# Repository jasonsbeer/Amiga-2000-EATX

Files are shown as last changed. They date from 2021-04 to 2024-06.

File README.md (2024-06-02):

# Amiga 2000 EATX PCB

This is an open source Amiga 2000 PCB in the EATX form factor. EATX is an ATX variant that defines larger PCBs, measuring 12 x 13 inches (305 × 330 mm). These are referred to as Extended ATX, or, EATX (see [Enterprise Electronics Bay Specification](/DataSheets/SSI%20EEB%202011%201.0.1.pdf)). The length of Zorro II cards and the abundance of components on the Amiga 2000 makes EATX the best choice for this project.

There are one-to-one board replacement projects for the Amiga 2000, but none to change the layout to meet current form factor standards. In addition, the Amiga 2000 made use of connectors and custom parts that are no longer commercially manufactured. This often requires parts to be pulled from existing machines. As such, this project will make use of only actively supported components when possible.

In addition to a new board replacement option, I believe the ubiquitous EATX standard will bring additional interest to the Amiga as a hobbyist and retro-computing option. At the time or writting this, the Amiga operating system is still actively developed and supported. In addition, there is a substantial database of existing software and hardware add-on options and an active community.

Discord: https://discord.gg/NU7SPYfNFj

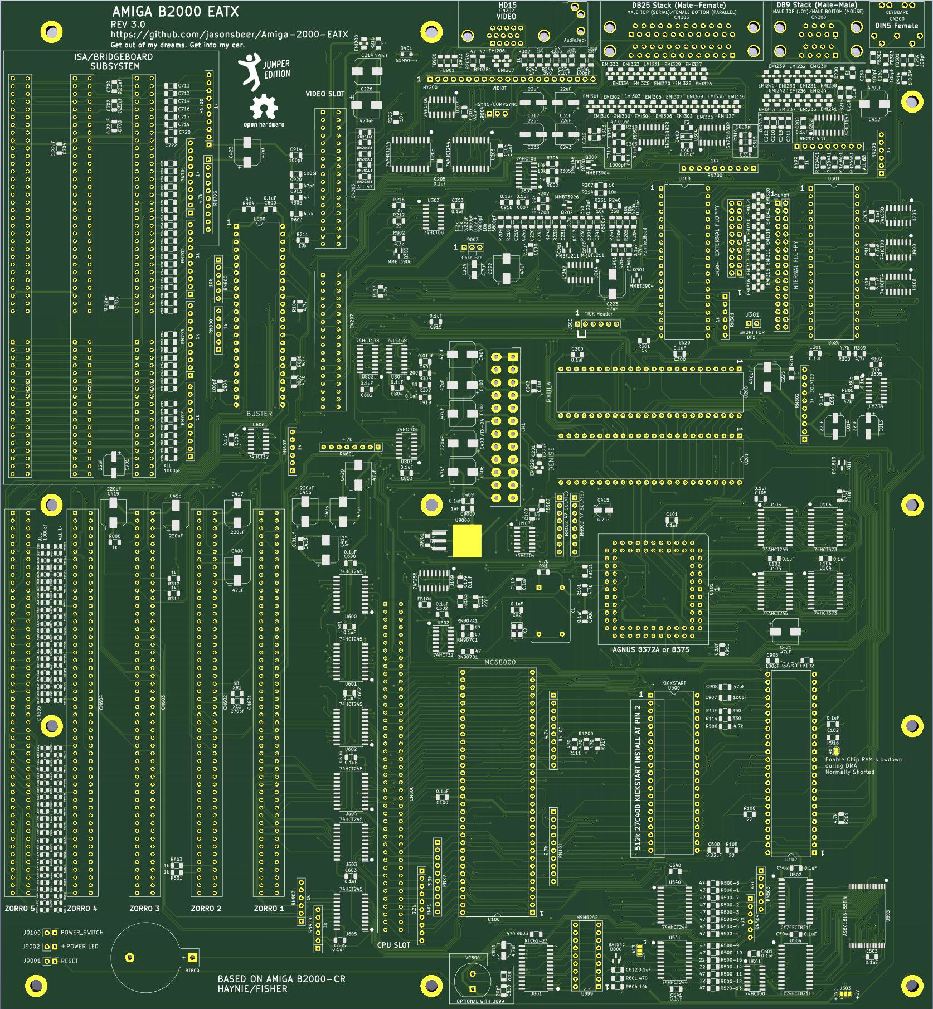
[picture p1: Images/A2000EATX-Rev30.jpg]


## Project Status

### Revision 3.1 is the current production board.

**Known Issues**: See Issues tab.

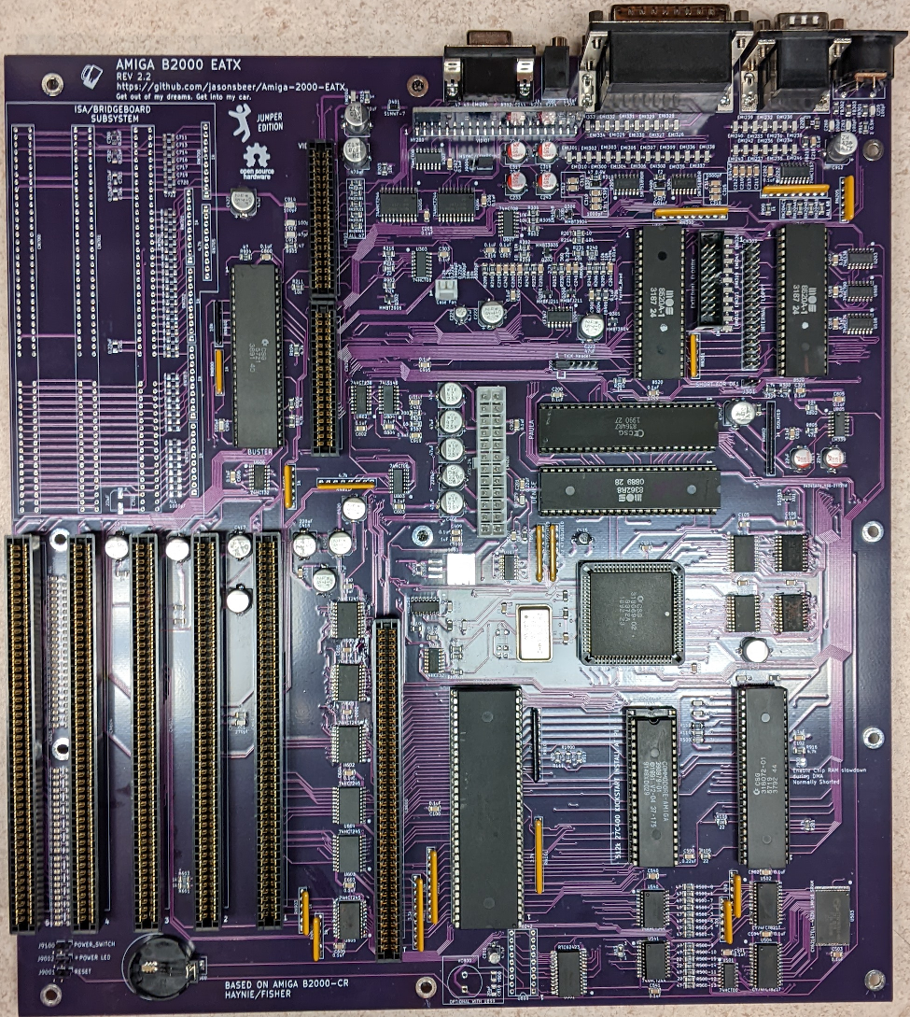
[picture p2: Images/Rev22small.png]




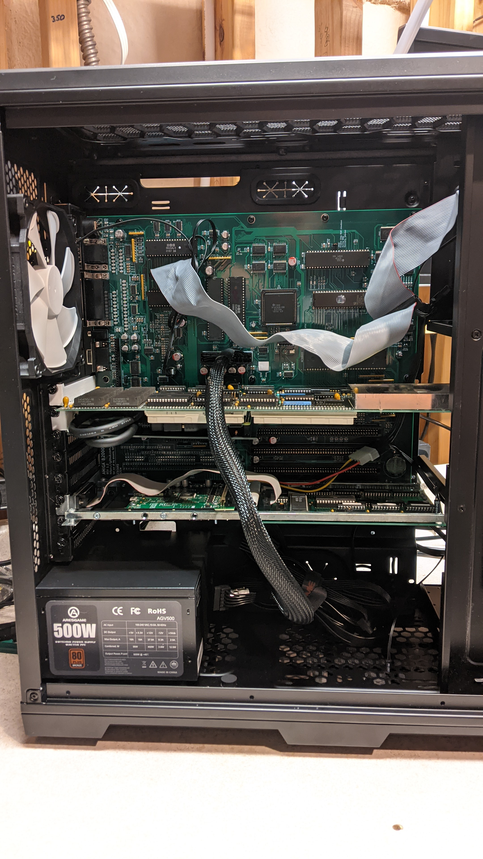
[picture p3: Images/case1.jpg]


Revision 3.0 can be found [here](https://github.com/jasonsbeer/Amiga-2000-EATX/tree/Rev-3.0).  
Revision 2.2 can be found [here](https://github.com/jasonsbeer/Amiga-2000-EATX/tree/Rev-2.2).  
Revision 1.2.1 can be found [here](https://github.com/jasonsbeer/Amiga-2000-EATX/tree/Rev-1.2.1).  

If you are interested in a brief history of this project, check out the [Gallery page](/Gallery.md).

## User Guide and Considerations
Review [this information](userguide.md) to ensure a smooth and happy experience when assembling an Amiga 2000 EATX system. It will answer many questions and inform you as to the physical requirements of the Amiga 2000 EATX PCB, various Amiga plug in cards, etc.

## Ordering PCBs
See information [here](PCB.md). 

## BOM and Assembling the Amiga 2000 EATX PCB

See information [here](AssemblyNotes.md).

## Changes from the original Amiga 2000

The Amiga 2000 EATX is derived from the Commodore Amiga 2000 Rev 6.2 schematics. To my knowledge, all known Rev 6.x PCB updates are included in this project. 

### Video
The DB23 video connector has been removed in favor of the HD15 connector. One of the goals of this project is to avoid parts that are not commercially available. The D-Sub 23 connector is a prime example. They are not stocked at popular electronic supply houses. Thus, the change to the widely available HD15 connector. Analog red, green, blue, HSYNC or COMPSYNC (jumper selectable), and VSYNC are supplied using the VGA standard pin out configuration. Other external video port signals are not supplied. Any VGA cable can be used to supply the video signal to a VGA monitor or conversion box supporting the 15KHz standard. 

The internal video slot is complete with all signals.

The external composite video jack has been removed.

### Memory
The original 256Kx4 DRAMs have been replaced by a single SRAM. The Amiga 2000 EATX supports 1 or 2 MB of chip memory, depending on your Agnus version. See additional information in the [assembly notes](AssemblyNotes.md).

### Audio Output
The left/right RCA jacks of the Amiga have been replaced by a 3.5mm stereo audio jack.

### Disk Drive Support
Internally, any Amiga compatable double density disk drive or properly configured Gotek floppy emulator is supported. Up to two internal disk drives may be connected to the internal floppy connector. Up to two external disk drives may be connected via a user supplied adapter cable.

### ISA Slots
The number of 16 bit ISA slots has been reduced to three. This was done to provide additional space on the board. Support for ISA cards via a Bridgeboard is unchanged from the Amiga 2000.

### Serial Port
The internal (infernal) serial port has been removed. The external serial port is present with all signals.

### PCB Layout
For obvious reasons, it was necessary to move components relative to one another. Zorro slots occupy slot positions 1-5, overlapping with ISA slots in the first 3 positions. The video slot occupies the sixth slot position on the board.  The CPU slot occupies position 7. It is possible to have every slot position populated simultaneously.

### ATX Power
ATX 24-pin power supplies are supported with -5V being supplied on board via a voltage regulator. The original Amiga 2000 power supply is not supported.

### External Reset Switch
The computer can be reset via CTRL-Amiga-Amiga on an Amiga keyboard or via the reset switch found on EATX computer cases.

### Real Time Clock
There are two real time clock (RTC) options beginning with revision 2.x. You can install the original Amiga 2000 RTC, which is based on the MSM6242, or a simplified RTC based on the RTC-62423. The MSM6242 requires more components and will need to be trimmed to dial in the correct clock speed. The RTC-62423 has a built in crystal and does not need adjustment, but is less accurate over time. In the Amiga, the RTC is written and read by 4 address and 4 data lines. There are no direct "modern" replacements for the type of bus connected RTC used in the Amiga. As such, the RTC chip you choose is among the legacy IC's that must be obtained. 

### TICK
The TICK timing signal on the original Amiga 2000 was supplied by the power supply and is a 50 or 60Hz signal determined by the mains power in use. ATX power supplies do not supply a TICK or any AC signal. Starting with Revision 2.2, a TICK Header (J300) was added to support independently generated TICK signals in the event your desired configuration demands this. The factory default setting supplies a TICK signal from the Agnus _VSYNC signal, which is suitable for most configurations. See [TICK HEADER](/AssemblyNotes.md#tick-header-j300) for more details and considerations. All revisions 2.1 and lower use the Agnus _VSYNC signal.

## What has not changed?
### Most External Ports
The keyboard, joystick, mouse, parallel, and serial ports are all present and function as they did in the Amiga 2000. The parallel, serial, mouse, and joystick ports are stacked DB9 and DB25 connectors, respectively. The Amiga keyboard port remains a DIN5 connector.

### Zorro II Slots
There are no changes to the Zorro II slots.

### Kickstart ROM
For now, the Kickstart ROM remains the original 27C400. These are no longer made, but are easy to find. In addition, this allows the use of an original Commodore Kickstart mask ROM. Revision 1.2 added support for 1MB (27C800) and 2MB (27C160) EPROMs for custom Kickstart ROMs.

### Everything Else
If something is not specifically mentioned, you should expect it to be unchanged in function or component from the original Amiga 2000.

## Revision History

Rev 3.1 **CURRENT PRODUCTION REVISION**
1. Various fixes (see closed issues flagged for Revision 3.1)
2. Changed SRAM back to +5V part
3. Added copper pours to top and bottom layer
4. Updated to KiCAD 8.0

Rev 3.0
1. Various fixes (see closed issues flagged for Revision 3.0)
2. Changed SRAM to 5V tolerant 3.3V part (lack of availability of +5V part)
3. Removed almost all signal traces from power planes
4. Swapped position of U801 and U899 and brought related components to front of board
5. Updated to KiCAD 7.0

Rev. 2.2  
1. Added TICK header (J300)
2. Cleaned up some odd routing that went back to the early revisions of this project
3. Changed footprint of CN300 to support more part options

Rev 2.1
1. Changed footprint of U9000 to offer more part options
2. Added U207 to buffer VSYNC and HSYNC signals
3. Relocated Zorro termination components
4. Added additional component values to silk screen
5. Moved many traces to the external layers

Rev 2.0
1. Supports both Agnus 8372A and certain Agnus 8375 part numbers on the same board
2. Added external floppy drive header
3. Support for two real-time clock options
4. Cleaned up the schematics

Rev 1.2.1 (First Production Release)
1. Added some missing component values to the silk screen, where there was room
2. Moved VIDIOT over to make additional room for coprocessor cards

Rev 1.2
1. Fixed traces on the keyboard connector (error on the C= schematic)
2. Added missing _COPCFG trace
3. Deleted some extra traces that were not needed
4. Added HSYNC/COMPSYNC selection jumper
5. Cleaned up parts of the schematics
6. Widened U801 footprint (RTC62423 is wider than the standard SOIC package)
7. Added support for 1 and 2 MB Kickstart ROMs (512k still supported)
8. Added some space around the external ports...they were crowded

Rev 1.1
1. New ATX on/off circuit
2. Modified SRAM circuit
3. Added case fan header
4. Fixed U100 and other footprints
5. Moved some components
6. Cleaned up silk screen

Rev 1.0
1. Adjusted postion of slots and several other components
2. Moved ATX On/Off circuit to back of board

Rev 0 - Prototype board
   
## Acknowledgments
kr239 - for the Amiga 500 DRAM replacement project inspiration and LIV2 and texneus for the modifications used in this project

iansbremmer - Amiga IC KiCad footprints - https://github.com/iansbremner/ReAmiga-3000---KiCAD

texneus - ATX ON/OFF and AC TICK circuit

DarrenHD - Pics and measurements of the Amiga 3000 video slot bracket adapter - https://eab.abime.net/showthread.php?t=106928

Chucky - Amiga Diagrom...a priceless diagnostic tool - http://www.diagrom.com/

floppie209 - For testing the Rev 3.0 board.

Everyone that made the Amiga possible.

**Last Updated 02-JUN-2024**

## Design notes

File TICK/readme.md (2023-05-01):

# TICK Generator Boards

Included here are two options ([9VAC](#9vac-tick-generator) and [Crystal Oscillator](#crystal-oscillator-tick-generator)) for generating an independent TICK signal for the Amiga 2000 EATX. These could be used in other projects needing a replacement TICK generator, such as adding an ATX power supply to an original big box Amiga. Both options are very simple circuits, small in size, and designed to be placed directly on J300 of the Amiga 2000 EATX Rev 2.2 and greater.

For more information on the Amiga 2000 EATX TICK and considerations, see [HERE](/README.md#tick) and [HERE](/AssemblyNotes.md#tick-header-j300)

Gerber files can be found [HERE](/Gerber).

## 9VAC TICK Generator
TICK signals are generated from the frequency of the mains power in use. This means 50 or 60 Hz, depending on where you are in the world. ATX power supplies, such as used by the Amiga 2000 EATX, supply neither a TICK nor AC signal of any type. Thus, it is necessary to create our own with a small circuit suitable for any mains frequency. In this case, we are using a 9VAC wall wart transformer to supply an AC signal based on the mains of the local power grid. Using 9VAC reduces the risk associated with powering such a device directly from mains while allowing us a more traditional TICK signal. Note that the AC TICK board will continue to receive power and function (to some extent) while the wall wart is plugged in, even when the Amiga 2000 EATX is turned off. You may wish to use a switched outlet or simply unplug the wall wort when not in use. Ensure alignment of pin 1 on the Amiga 2000 EATX with pin 1 on the 9VAC TICK board. See [BOM](#bom).

Image 1. The 9VAC TICK generator board on the Amiga 2000 EATX.

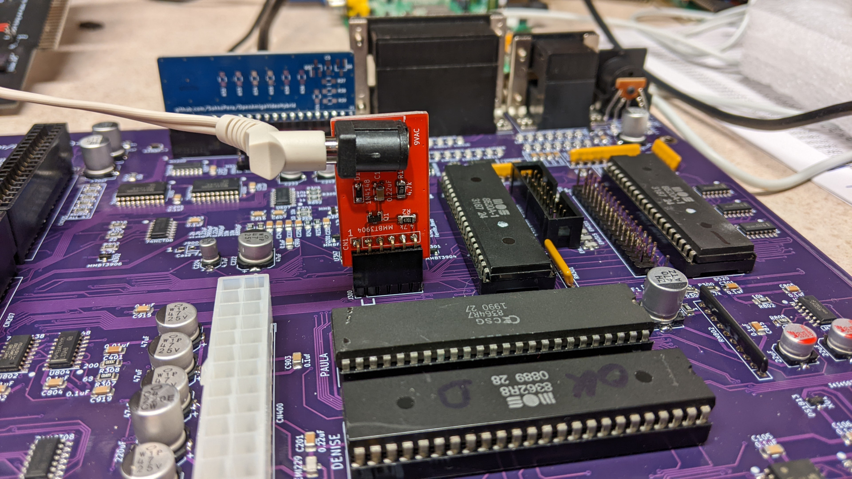
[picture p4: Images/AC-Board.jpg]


Image 2. A 60Hz TICK signal from the 9VAC TICK Generator.

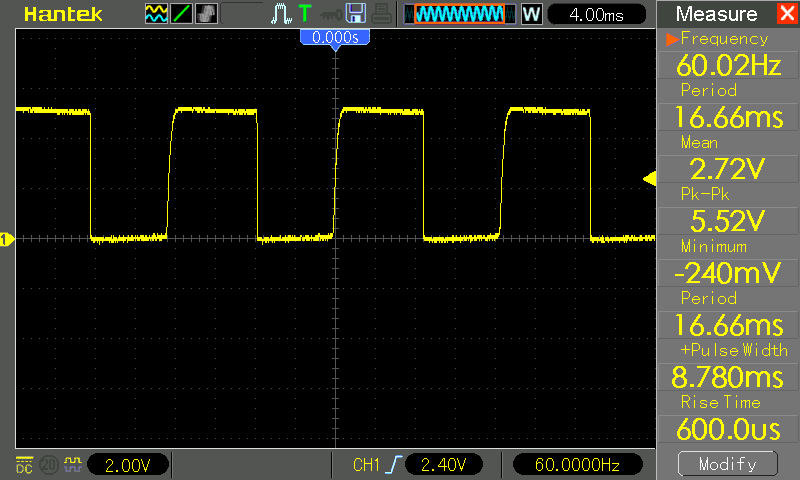
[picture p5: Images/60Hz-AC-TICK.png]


## Crystal Oscillator TICK Generator
Like many modern components, we can also generate an accurate TICK signal with a crystal oscillator. The advantage of this is that we have an entirely self-contained circuit that does not rely on external power sources to drive the frequency. This circuit is a single board, though slighly more complex than the AC TICK circuit, powered directly by the Amiga 2000 EATX. To ensure the correct 50 or 60 Hz frequency, we use the crystal that matches the desired frequency of the video standard your machine is configured to. This circuit is based on the original published by [Michael Schulz](https://aminet.net/package/docs/hard/Mix_and_Tick). Ensure alignment of pin 1 on the Amiga 2000 EATX with pin 1 on the crystal oscillator TICK board. See [BOM](#bom).

Image 3. The crystal oscillator TICK generator board on the Amiga 2000 EATX.

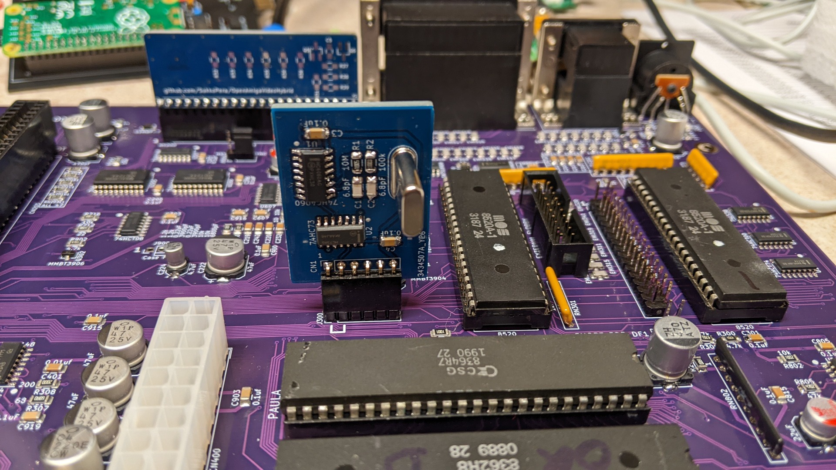
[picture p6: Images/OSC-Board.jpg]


Image 4. A 50Hz TICK signal from the crystal oscillator TICK Generator.

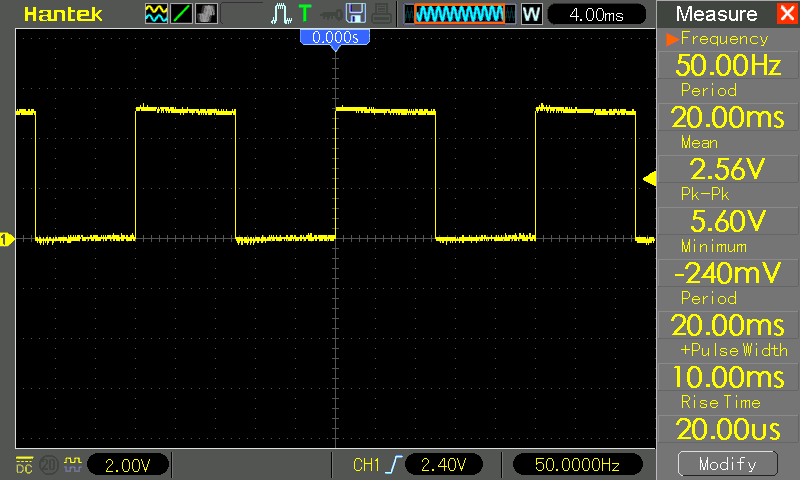
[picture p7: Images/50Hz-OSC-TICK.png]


## Dual Oscillator TICK Generator
Submitted by kavanoz and sparxUK, this TICK generator is based on the crystal oscillator TICK board but can be set to either PAL or NTSC via the on-board jumper. The passives have been reduced to the 0805 footprint. The BOM and assembly files can be found with the Gerber files in the [Gerber](/Gerber) folder.

Image 5. Dual oscillator TICK board on the Amiga 2000 EATX.

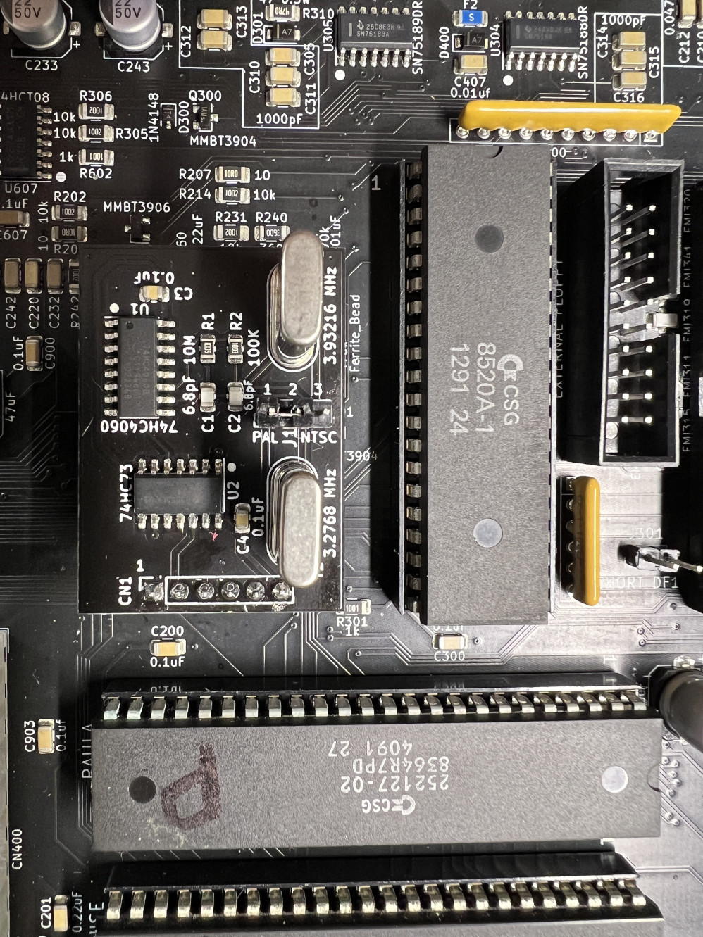
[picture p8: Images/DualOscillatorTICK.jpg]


## BOM
**Table 1.** 9VAC BOM

Reference|Value|Footprint|Notes
-|-|-|-
C1|0.22uF|1206|
D1|1N4148|SOD-323|
R1|4.7k|1206|See Footnote*
R2|4.7k|1206|
Q1|MMBT3904|SOT-23|
CN1|6 Pin Female Header|2.54mm Pitch|
CN2|Barrel Jack||Optional
-|9VAC Wall Wart Transformer||

*It is possible to use transformer output values other than 9VAC. For 6VAC, R1 does not change. For 12VAC or 16VAC transformers, R1 = 10k. For 20VAC or 24VAC transformers, R1 = 22k. These values are untested, so care should be taken when opting to use transformer values greater than 9VAC.

**Table 2.** Crystal Oscillator BOM
Reference|Value|Footprint|Notes
-|-|-|-
C1|6.8pF|1206|
C2|6.8pF|1206|
C3|0.1uF|1206|
C4|0.1uF|1206|
R1|10M|1206|
R2|100k|1206|
U1|74HC4060|16-SOIC|
U2|74HC73|14-SOIC|
Y1|3.93216MHZ|HC-49/U|60Hz (NTSC)
Y1|3.2768MHz|HC-49/U|50Hz (PAL)
CN1|6 Pin Female Header|2.54mm Pitch|

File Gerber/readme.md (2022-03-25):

Gerber files for the Amiga 2000 EATX and TICK generator boards.

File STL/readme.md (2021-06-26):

Here you can find STL and FreeCAD files for new card brackets that will be usefull when building an Amiga 2000 EATX.

[COP Adapter](/STL/COP-Simple-Adapter) is a simple adapter to attach coprocessor and video cards to standard computer slots.

[A26x0 Adapter](/STL/A26x0_Adapter) is a new bracket for the Commodore A2620 and A2630 coprocessor cards.

[Plain Bracket](/STL/Plain-Bracket) is a standard slot cover that can be used to make your own custom bracket or print a spare.

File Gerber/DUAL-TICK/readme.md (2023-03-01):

Contains the Dual-TICK gerber and production files.

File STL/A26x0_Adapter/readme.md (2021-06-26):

This is a standard bracket designed for the Commodore A2620 and A2630 coprocessor cards. This can be used to mount the A26x0 coprocessor card in a standard slot bracket for the Amiga 2000 EATX. Specifically, I designed it using the A2630 Rev 9 as a reference. As far as I know, it should work on either model and any revision.

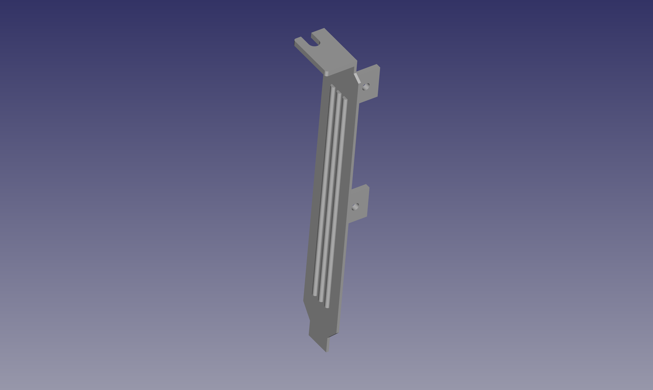
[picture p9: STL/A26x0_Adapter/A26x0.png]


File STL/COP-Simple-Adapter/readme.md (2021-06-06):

This is a simple adapter for coprocessor or video cards that allows you to attach one to a standard computer slot. The STL and FreeCAD files are included.

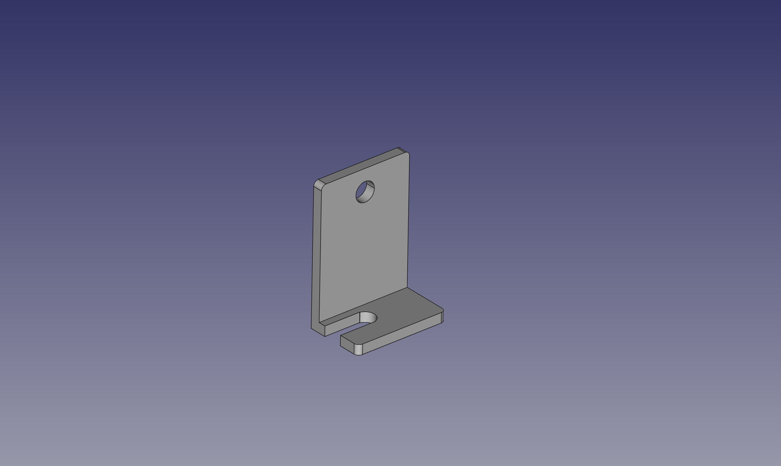
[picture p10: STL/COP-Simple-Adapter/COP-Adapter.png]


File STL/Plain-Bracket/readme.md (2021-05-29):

This is an unmodified slot cover. You can use this as a starting point to design your own custom brackets or just print spares. I have included the STL and FreeCAD files.

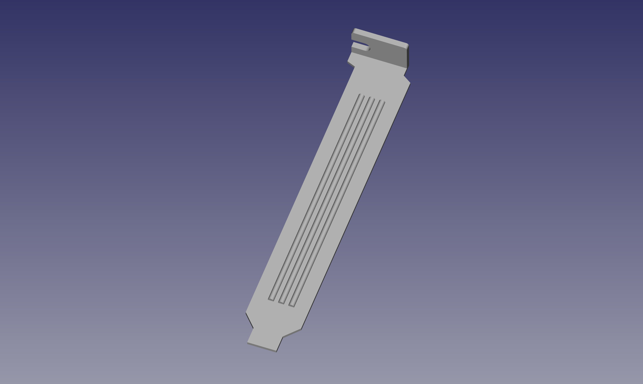
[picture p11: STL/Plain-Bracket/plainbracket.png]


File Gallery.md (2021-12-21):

Here are some photos of note and comments related to the development of the Amiga 2000 EATX. I ordered these from oldest to newest. I thought it would be fun to reflect on the last few months and how much effort this really took. It gives me a time to decompress and think about all it took to get here. Thanks for looking.

The revision 0 board. This is where it all started. Starting in March, 2021, it took 2 weeks to enter the schematics and another 6 weeks to route the board. No components were soldered to this revision because it was painfully obvious that the card slots are nowhere near where the should be. I measured from the edge of the board instead of the correct datum point, which is the upper left mounting hole. I was pretty unhappy with myself, to say the least.

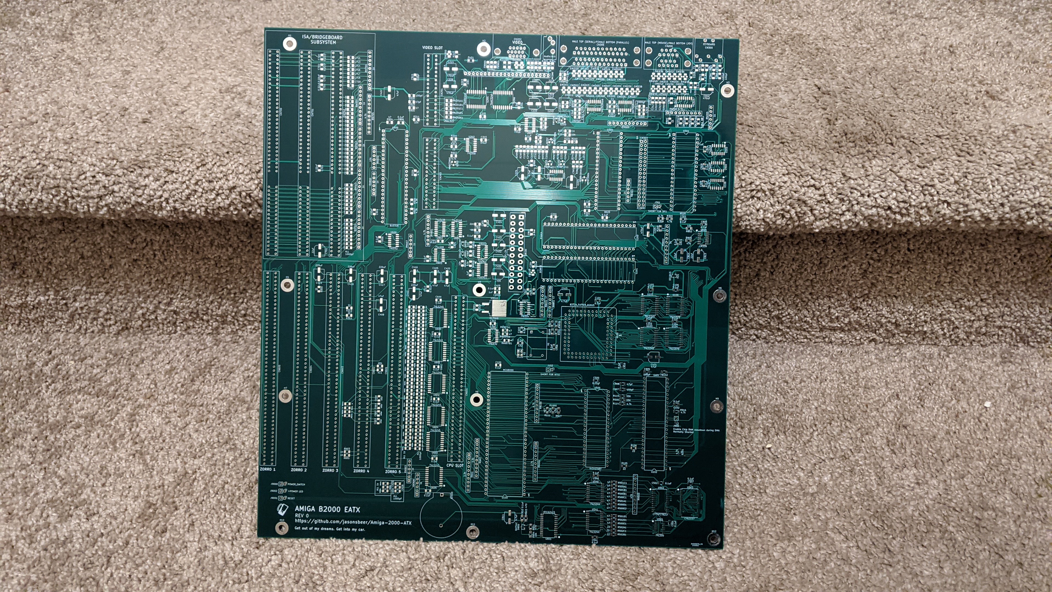
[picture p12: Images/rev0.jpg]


I quickly figured out the datum issue and moved the slots nearer to the correct position for the revision 1.0 board. The Zorro and ISA slot positions are well documented. The video and coprocessor slots...not so much. I spent time looking at pictures of the A3000 back plane and using a micrometer on my A2000 and A2630 to figure out where those slots needed to be. I was really close...within 1-2 millimeters, but still not quite right. I had to move them a little bit for the next revision.

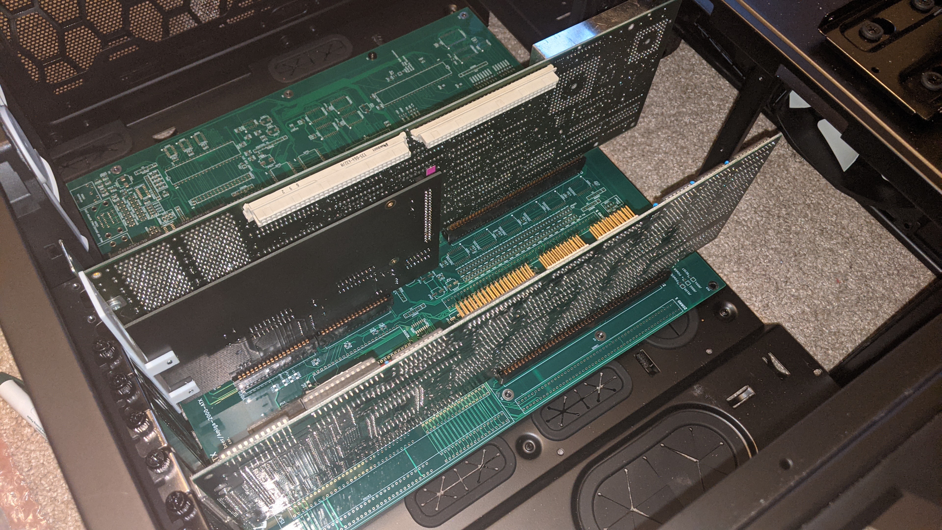
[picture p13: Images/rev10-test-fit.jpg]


Fortunately, it was pointed out to me that the RAM circuit I borrowed was, in fact, inoperable. See issue #1 on GitHub. Thanks to help from some friends and family, we were able to fix up the circuit. This is the bodge I attempted to implement the new RAM circuit on the revision 1.0 board. I never got that board to work. 

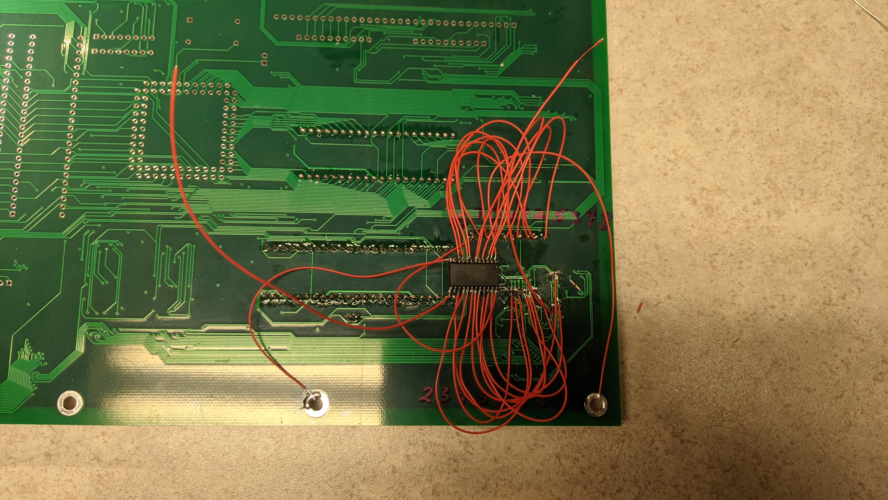
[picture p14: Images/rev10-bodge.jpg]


Trying to track down what was going on with the Revision 1.0 board.

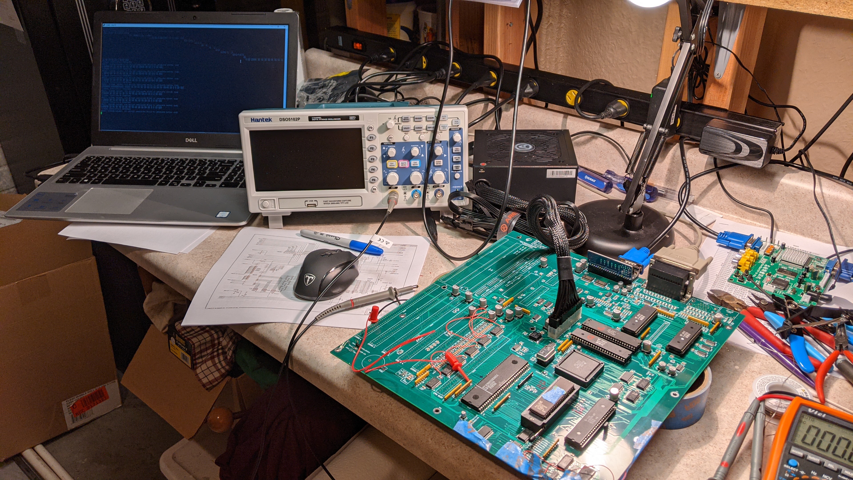
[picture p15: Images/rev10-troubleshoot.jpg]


A hint from diagrom? Ultimately, the original ATX on/off circuit stopped working, which I took as a hint it was time to move to the next revision. I turned to my brother to engineer a more robust latch circuit. He delivered one that first appeared in revision 1.1 and persists to this day.

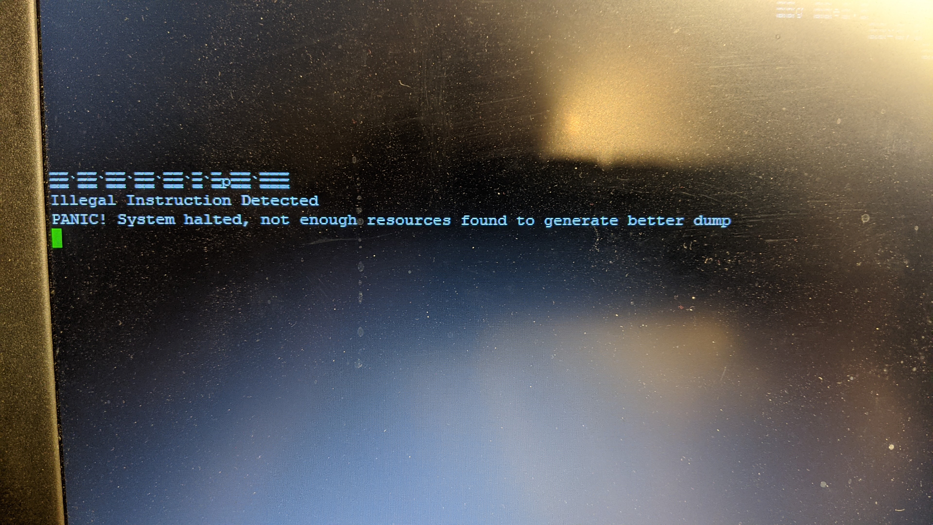
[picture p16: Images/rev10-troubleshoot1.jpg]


My idea of a pre-heater. My SMD technique is to use an electric griddle to pre-heat the board and go over it with a hot air station.

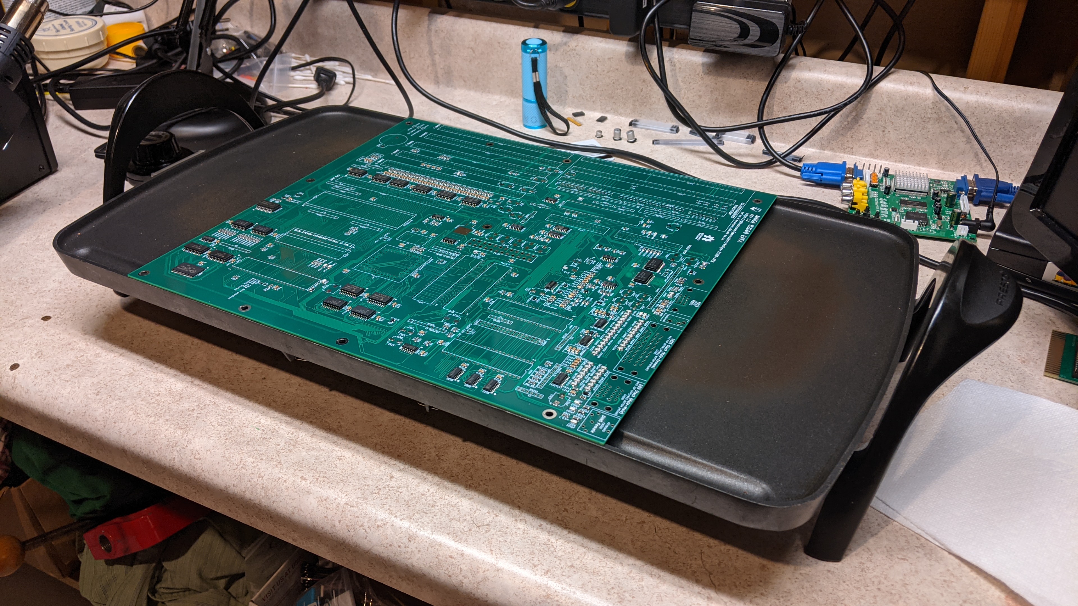
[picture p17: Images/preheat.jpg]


After sending off for the revision 1.1 boards, I found a major issue in the schematics. The most likely reason I was not able to get revision 1.0 working is due to data signals that were connected to PPD signals of U300. Basically, D1 was shorted to PPD1, etc. This happened due to how I labeled some of the signals in the schematics. Lesson learned. You can see the bodges around the serial and parallel port to fix this issue. In addition, I found an error on the Commodore A2000 (and A3000) schematics associated with the keyboard connector. You can see the bodges there, as well. One last bodge to implement the COPCFG signal, which was not routed due to a spelling mistake in the schematics. You can see a tactile switch soldered on as a power switch and an LED soldered directly to the board to serve as the power light.

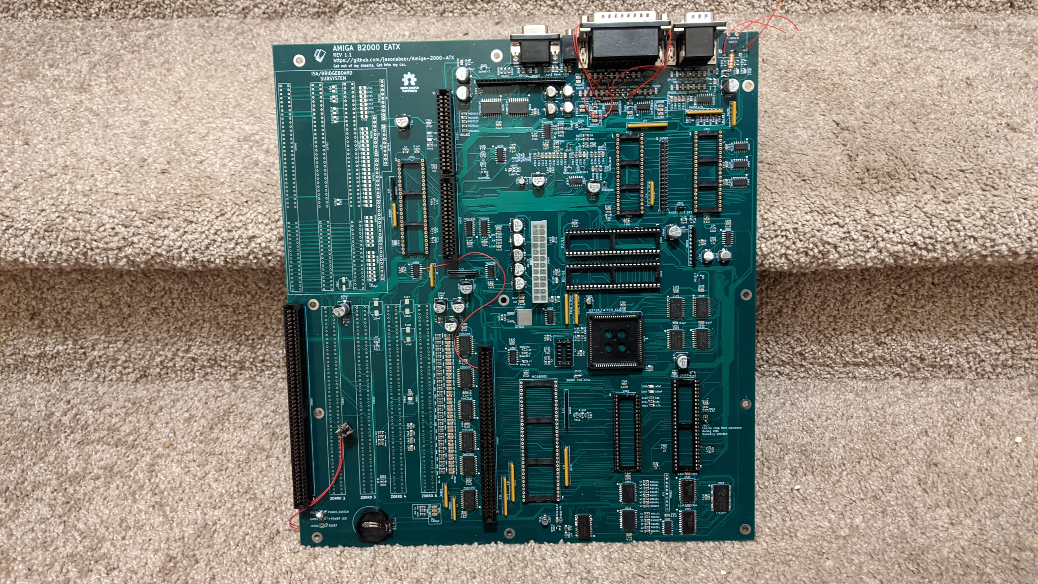
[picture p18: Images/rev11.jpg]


Diagrom says revision 1.1 is working!

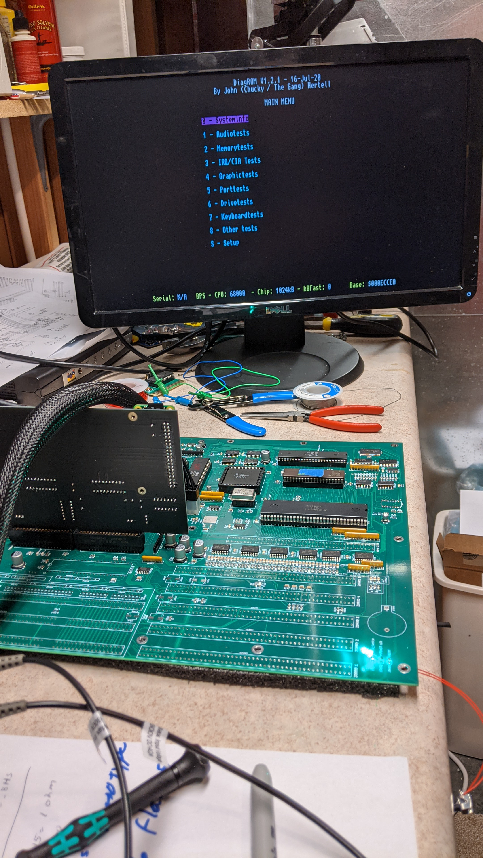
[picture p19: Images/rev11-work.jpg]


Finally! I jumped and yelled with joy when this familiar purple screen appeared.

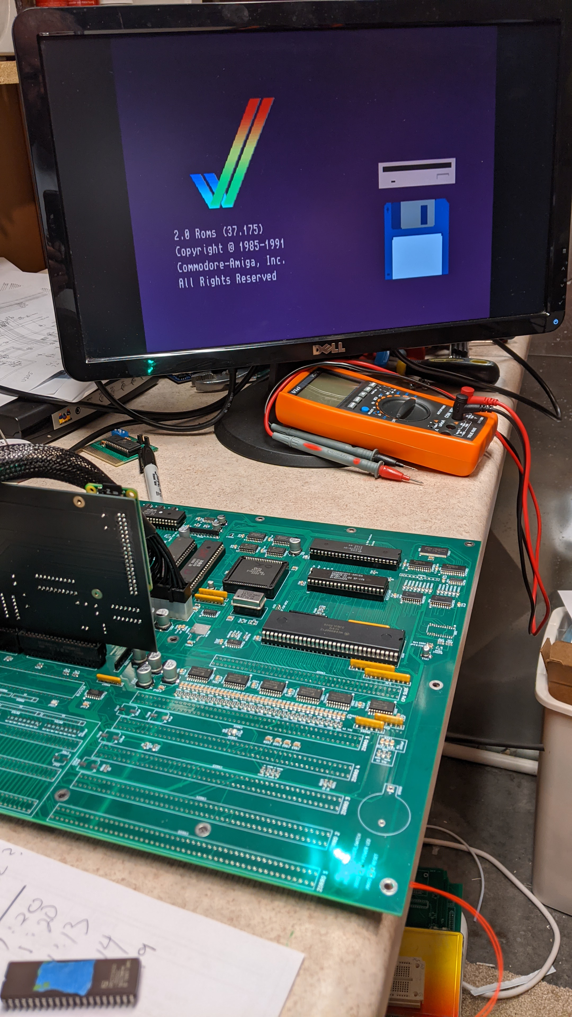
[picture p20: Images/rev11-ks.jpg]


However, not everything was rosey. I was unable to get a picture from the RGB port. The Pi -> HDMI card worked...after a firmware upgrade...that is another story. My brother and I worked on it over the phone several evenings but could find no answers. It seemed that we were unable to get a sync lock using the GBS8200 video adapter. We probed the sync signals incessantly to determine what was wrong. It turned out that there was no problem. After several days of struggle, I reviewed the GBS8200 documentation only to realize it needed a COMPSYNC signal. I had been feeding it HSYNC. I was really mad at myself. This whole ordeal lead to the inclusion of jumper J9004 HSYNC/COMPSYNC. In this picture, you can see the Amiga's VSYNC and HSYNC signals. They look great, which means Agnus is doing her job with flying colors.

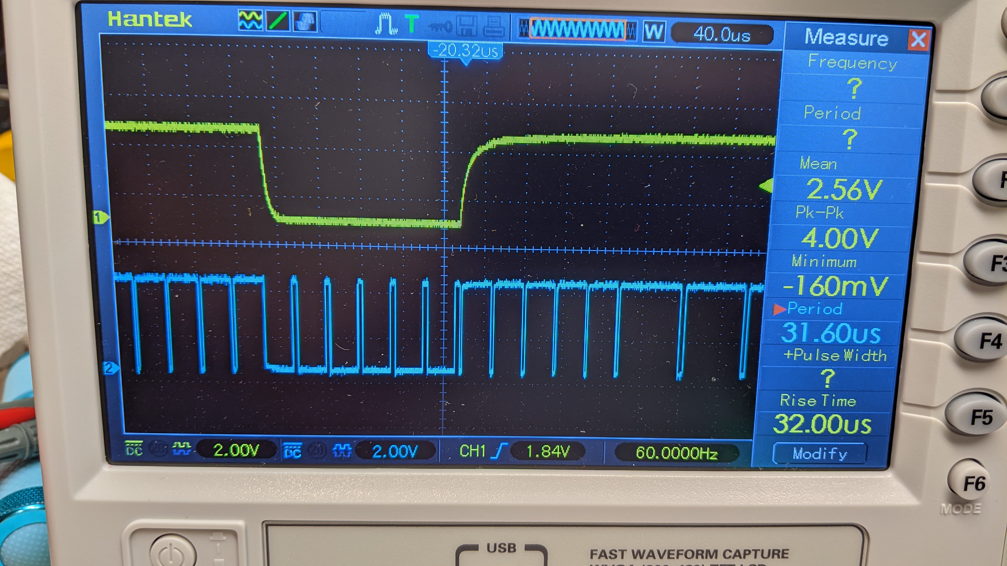
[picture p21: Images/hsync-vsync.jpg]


Revision 1.2, the first production candidate. It worked on the first try. After 6 months of work, we have a working PCB with no bodges.

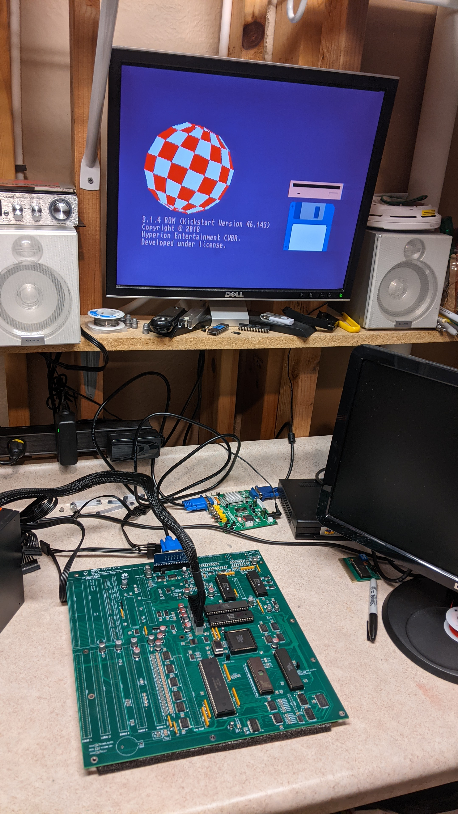
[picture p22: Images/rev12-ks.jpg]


The revision 1.2 board in an Enthoo EATX case.

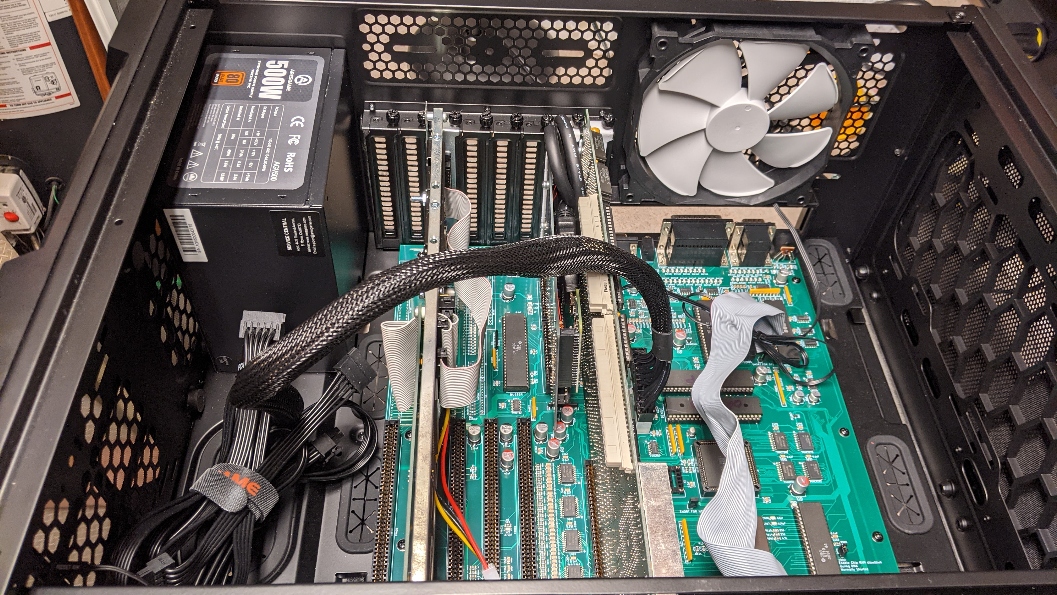
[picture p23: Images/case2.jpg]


Running Workbench 3.1.4 on the revision 1.2 board.

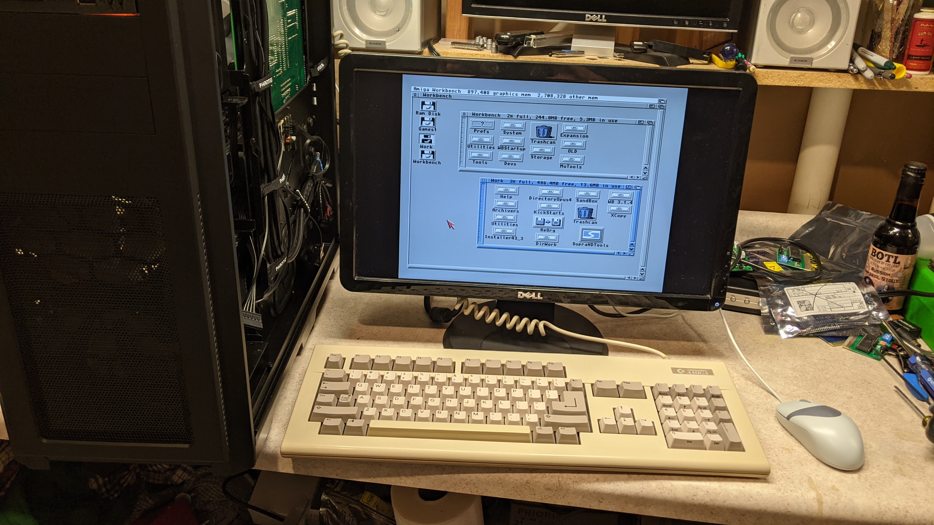
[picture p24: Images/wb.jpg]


The final touch on this project. Connected to J9003, the fan, she spins! 

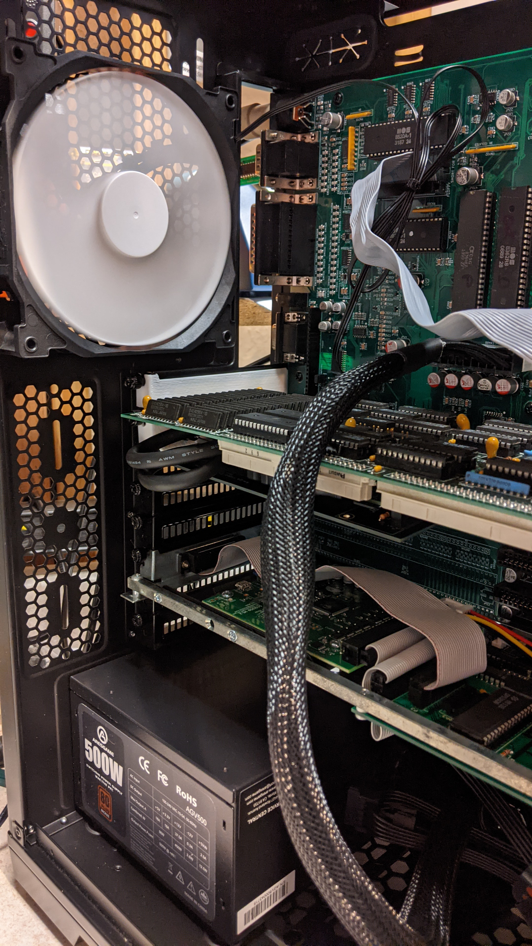
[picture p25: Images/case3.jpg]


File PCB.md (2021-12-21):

## PCB - Description and Ordering

The Amiga 2000 EATX PCB is 4 layers. See Table P1 for layer descriptions. Most components are on the top layer with the ATX on/off circuit and some Agnus and real time clock passives on the bottom.

Download the [Gerber zip file](/Gerber) and send to your favorite PCB manufacturer. If you do not have access to the appropriate stencil, it is highly recommended you purchase one at the time you purchase the PCB.

The development PCB's were purchased from JLCPCB and no issues were encountered. The JLCPCB order screens are shown to reflect their order options. Other PCB fabricators will have similar options, most will be set from the information in the gerber files. Other recommended order options are included to help guide you through the ordering process.

Final PCB thickness is 1.6mm.

Image P1 - Layer stackup

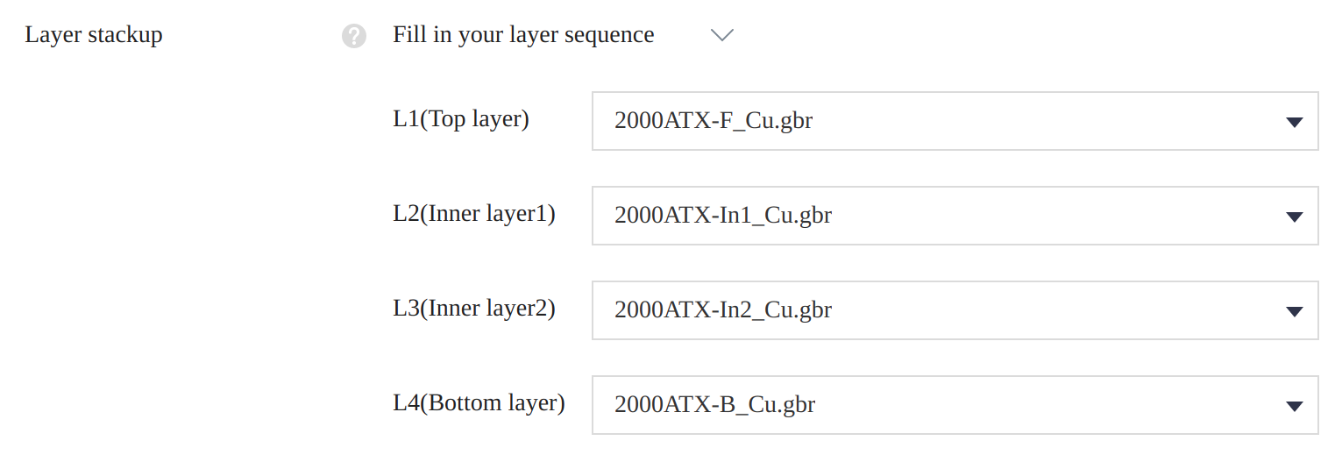
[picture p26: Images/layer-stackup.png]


Image P2 - General fabrication options

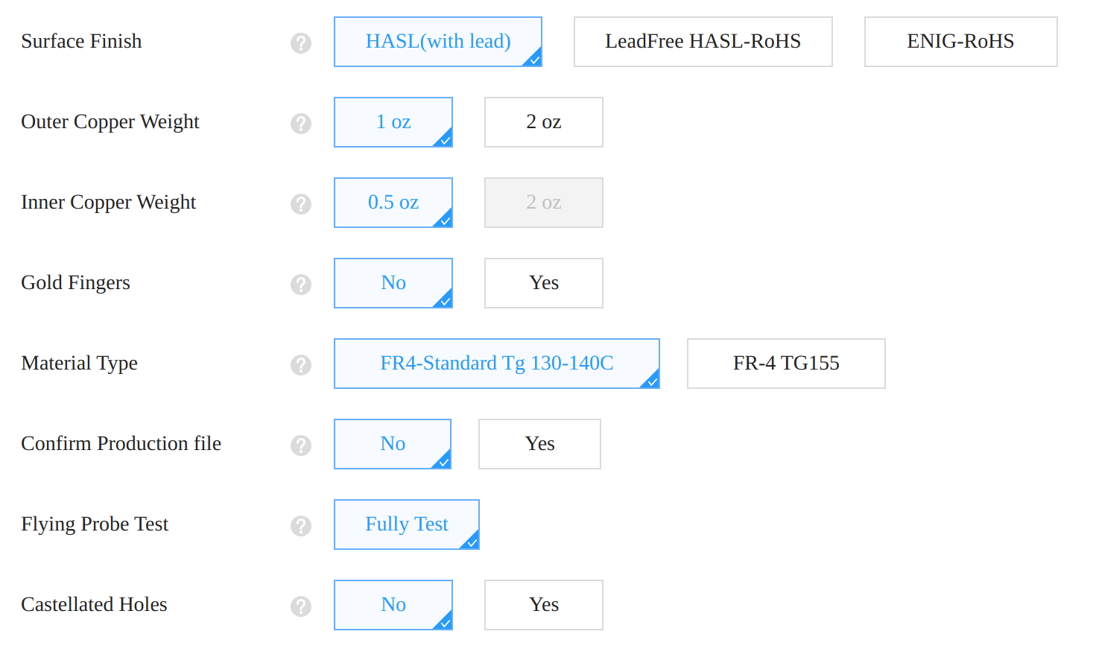
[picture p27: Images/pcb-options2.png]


Table P1. Board Layers
Layer|Description
-|-
1|Component and Signal
2|Ground Plane and Signal
3|Power Plane
4|Component and Signal

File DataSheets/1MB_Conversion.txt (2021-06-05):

Recording this process for posterity.

To convert an Amiga 2000 to 1MB chip ram with the 8372A Fatter Agnus.

1) J101 - Set to short pins 2 and 3 (default is pins 1 and 2, which is 512k chip ram)
2) J500 - Cut
3) J102 - Cut on PAL machines only

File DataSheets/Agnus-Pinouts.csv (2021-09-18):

Part # | 8372A | 8375 | 8375
Pin | All | 390554-01 | 318069-10
1 | DRD13 | DRD13 | DRD13
2 | DRD12 | DRD12 | DRD12
3 | DRD11 | DRD11 | DRD11
4 | DRD10 | DRD10 | DRD10
5 | DRD9 | DRD9 | DRD9
6 | DRD8 | DRD8 | DRD8
7 | DRD7 | DRD7 | DRD7
8 | DRD6 | DRD6 | DRD6
9 | DRD5 | DRD5 | DRD5
10 | DRD4 | DRD4 | DRD4
11 | DRD3 | DRD3 | DRD3
12 | DRD2 | DRD2 | DRD2
13 | DRD1 | DRD1 | DRD1
14 | DRD0 | DRD0 | DRD0
15 | VCC | Vcc | Vcc
16 | _RESET | _RESET | _RESET
17 | _INTR | _INTR | _INTR
18 | DMAL | DMAL | DMAL
19 | _BLISS | _BLISS | _BLISS
20 | _BLIT | _BLIT | _BLIT
21 | _WE | _WE | _WE
22 | R/W | R/W | R/W
23 | _REGEN | _REGEN | _REGEN
24 | _AS | _AS | _AS
25 | _RAMEN | _RAMEN | _RAMEN
26 | RGA8 | RGA8 | RGA8
27 | RGA7 | RGA7 | RGA7
28 | RGA6 | RGA6 | RGA6
29 | RGA5 | RGA5 | RGA5
30 | RGA4 | RGA4 | RGA4
31 | RGA3 | RGA3 | RGA3
32 | RGA2 | RGA2 | RGA2
33 | RGA1 | RGA1 | RGA1
34 | 28MHz | 28 MHz | 28 MHz
35 | XCLK | A20 | A20
36 | _XCLKEN | _CDAC | _CDAC
37 | _CDAC | 7 MHz | 7 MHz
38 | 7MHz | CCKQ | CCKQ
39 | CCKQ | CCK | CCK
40 | CCK | 14M | Vbb
41 | PAL/NTSC | GND | GND
42 | GND | DRA0 | DRA0
43 | DRA0 | DRA1 | DRA1
44 | DRA1 | DRA2 | DRA2
45 | DRA2 | DRA3 | DRA3
46 | DRA3 | DRA4 | DRA4
47 | DRA4 | DRA5 | DRA5
48 | DRA5 | DRA6 | DRA6
49 | DRA6 | DRA7 | DRA7
50 | DRA7 | DRA8 | DRA8
51 | DRA8 | _LDS | _LDS
52 | _LDS | _UDS | _UDS
53 | _UDS | _CASL | _CASL
54 | _CASL | _CASU | _CASU
55 | _CASU | DRA9 | DRA9
56 | _RAS1 | _RAS1 | _RAS1
57 | _RAS0 | _RAS0 | _RAS0
58 | GND | GND | GND
59 | A19 | A19 | A19
60 | A1 | A1 | A1
61 | A2 | A2 | A2
62 | A3 | A3 | A3
63 | A4 | A4 | A4
64 | A5 | A5 | A5
65 | A6 | A6 | A6
66 | A7 | A7 | A7
67 | A8 | A8 | A8
68 | A9 | A9 | A9
69 | A10 | A10 | A10
70 | A11 | A11 | A11
71 | A12 | A12 | A12
72 | A13 | A13 | A13
73 | A14 | A14 | A14
74 | A15 | A15 | A15
75 | A16 | A16 | A16
76 | A17 | A17 | A17
77 | A18 | A18 | A18
78 | _LPEN | _LPEN | _LPEN
79 | _VSYNC | _VSYNC | _VSYNC
80 | _CSYNC | _CSYNC | _CSYNC
81 | _HSYNC | _HSYNC | _HSYNC
82 | GND | GND | GND
83 | DRD15 | DRD15 | DRD15
84 | DRD14 | DRD14 | DRD14

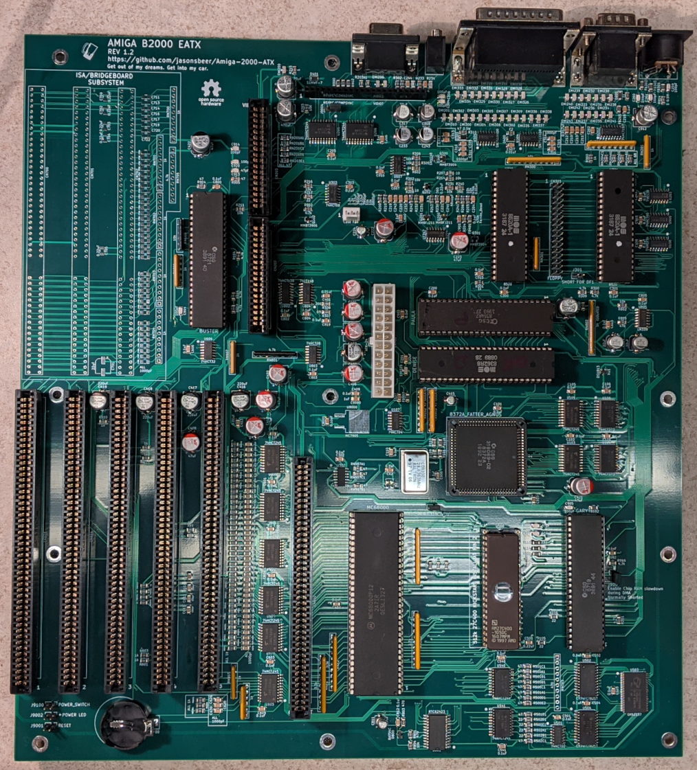
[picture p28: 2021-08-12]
Images/Rev12-Complete-small.png

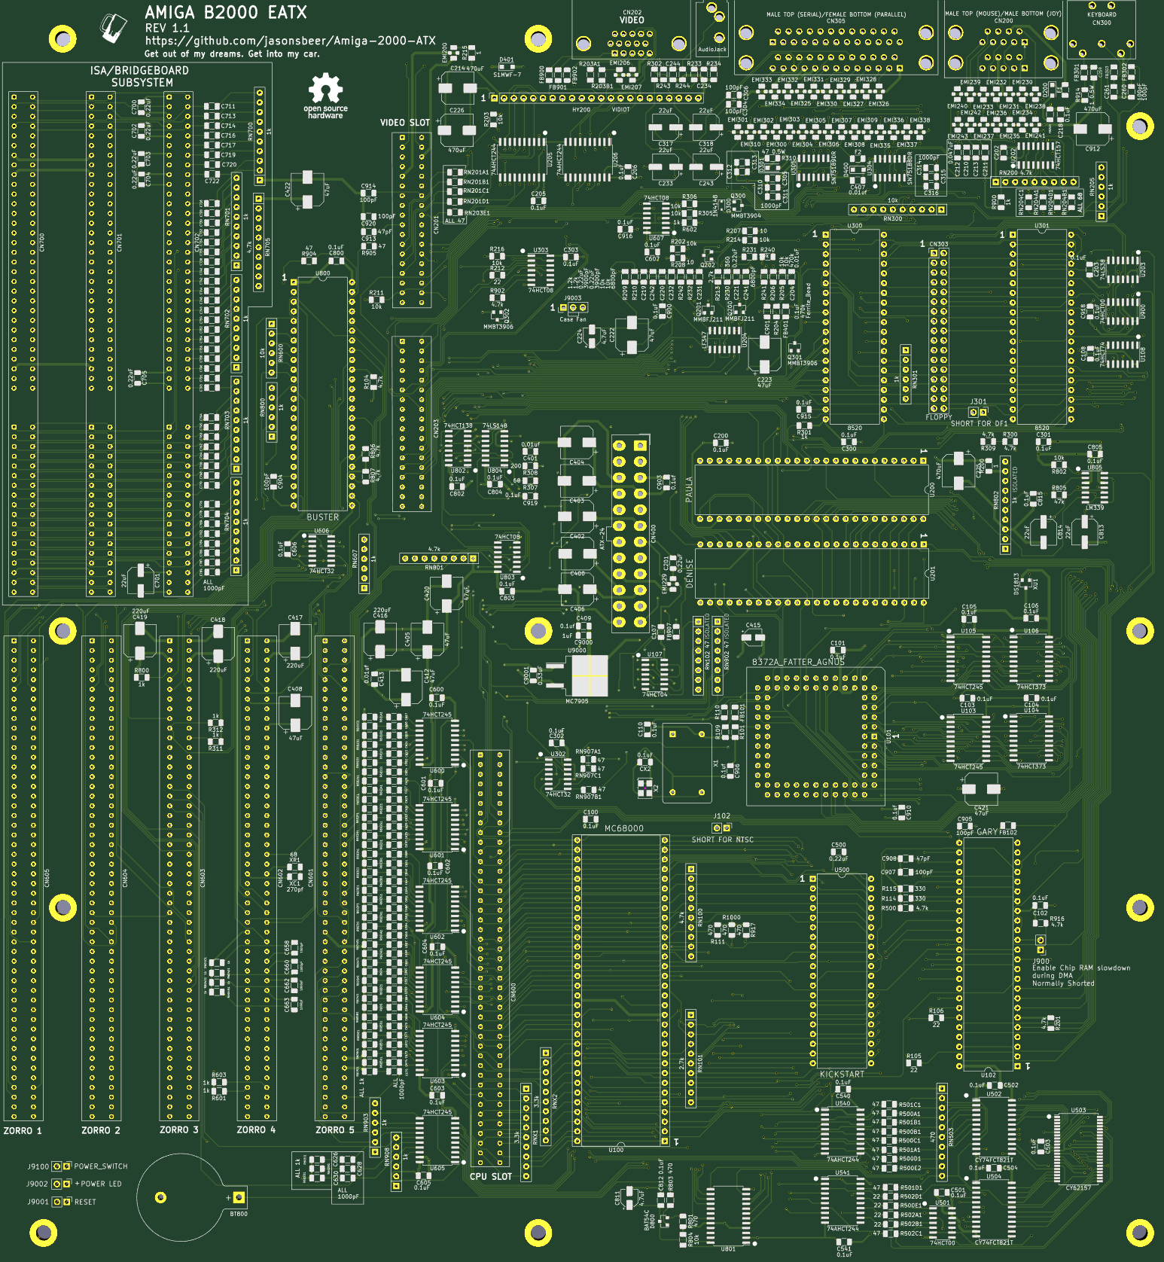
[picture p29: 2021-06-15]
Images/rev11.png

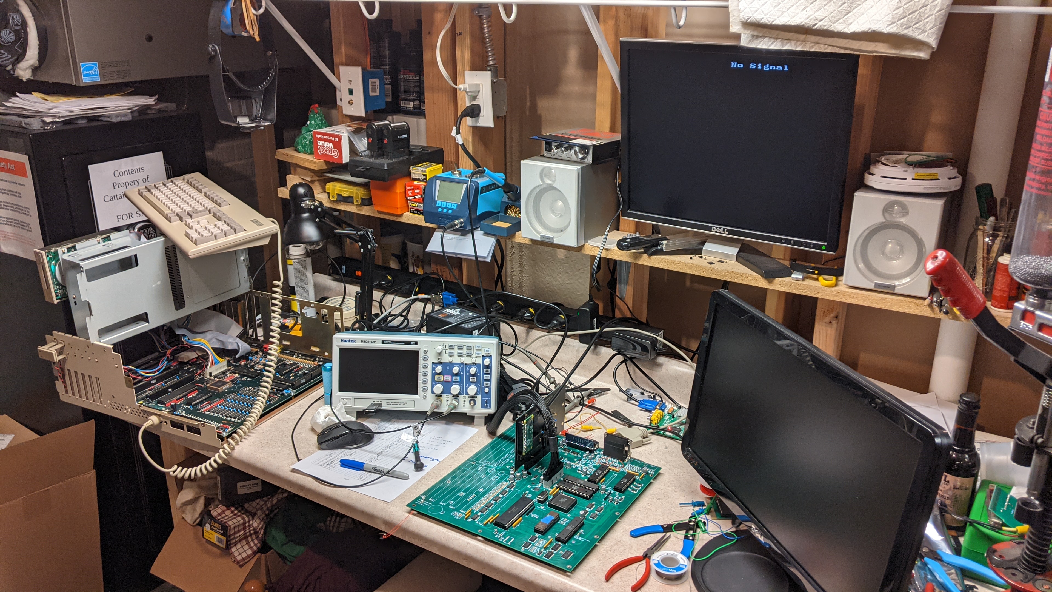
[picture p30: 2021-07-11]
Images/rev11-workbench.jpg

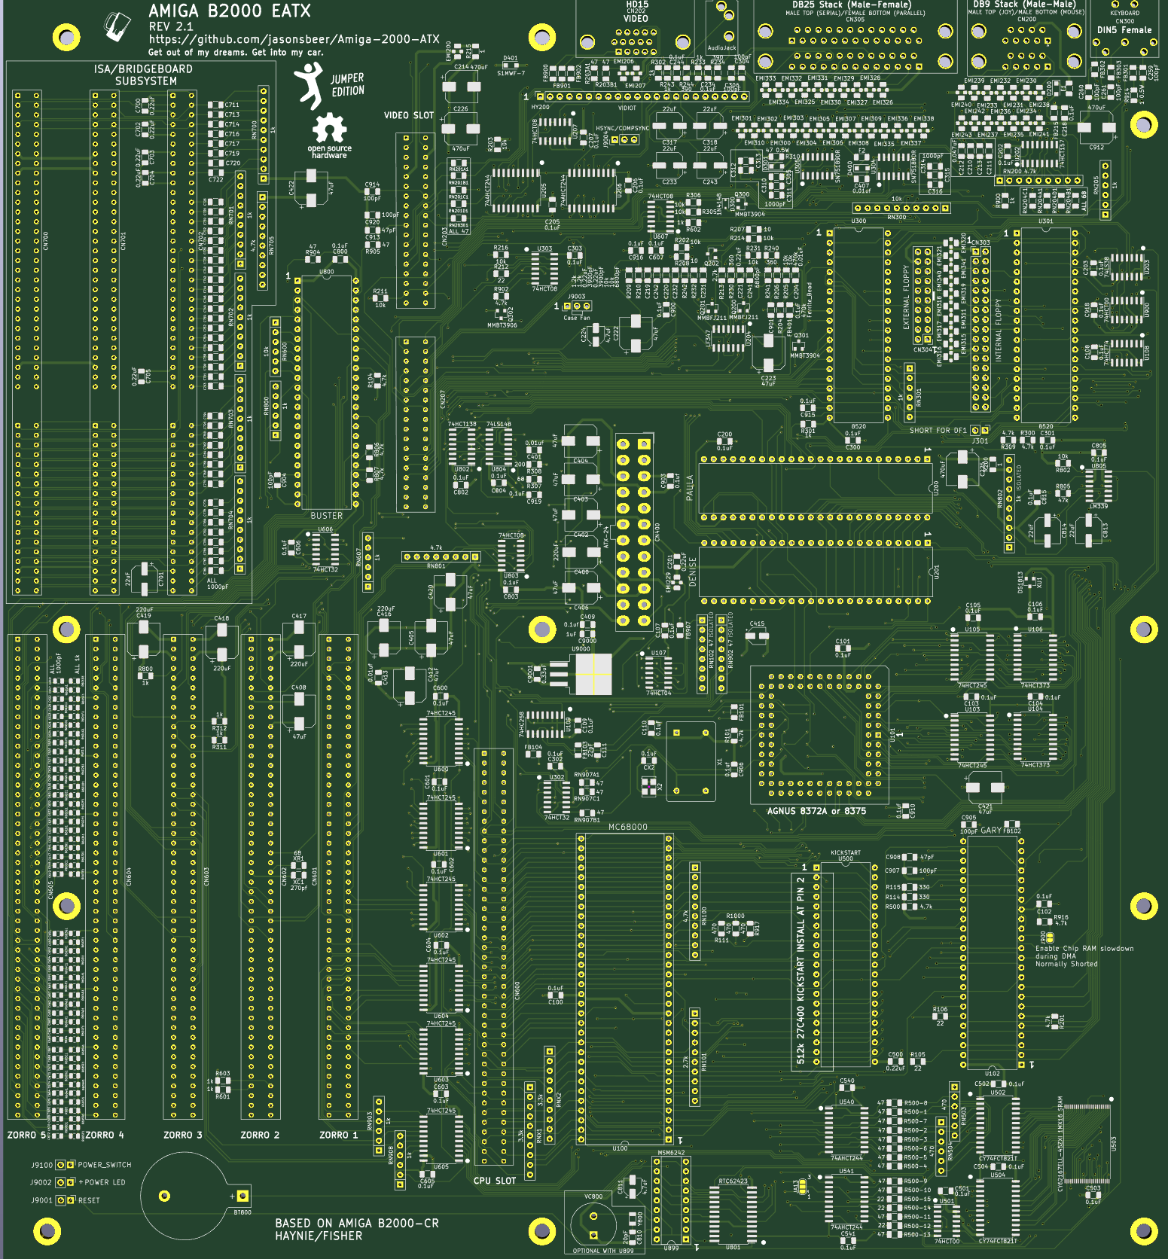
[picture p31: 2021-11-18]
Images/REV21-PCB.png

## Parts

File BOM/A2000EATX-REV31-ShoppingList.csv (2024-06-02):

Item | Qty | Value | Component Type | Footprint | Comments | Digikey Part
1 | 1 | MC7905 | -5V Voltage Regulator | TO-263-3 |  | 296-20799-2-ND
2 | 3 | ISA-16-BIT-Slot | 16 Bit ISA Slot | - |  | S3329-ND
3 | 4 | Male Pin Header | 1x02 Male Pin Header, 2.54 Pitch
4 | 1 | Case Fan | 1x03 Fan Header |  |  | WM4201-ND
5 | 1 | Male Pin Header | 1x03 Male Pin Header, 2.54 Pitch
6 | 1 | Male Pin Header | 1x06 Male Pin Header, 2.54 Pitch
7 | 1 | EXTERNAL FLOPPY | 2x10 Male Pin Header, 2.54 Pitch | -
8 | 1 | INTERNAL FLOPPY | 2x17 Male Pin Header, 2.54 Pitch | -
9 | 2 | Amiga-2000-Video-Slot | 2x18 Card Edge Slot | - | Video Slot | A31716-ND
10 | 1 | Amiga-2000-CPU-Slot | 2x43 Card Edge Slot | - | CPU Slot | A144213-ND
11 | 5 | Amiga-2000-Zorro-Slot | 2x50 Card Edge Slot | - | Zorro 2 Slot | A121376-ND
12 | 1 | AudioJack | 3.5mm Stereo Audio Jack | - |  | CP1-3533N-ND
13 | 1 | ATX-24 | ATX Power, Female | - |  | WM3811-ND
14 | 4 | 0.01uF | Capacitor, Ceramic | 1206 | 10000pF
16 | 4 | 0.047uF | Capacitor, Ceramic | 1206
17 | 62 | 0.1uF | Capacitor, Ceramic | 1206
20 | 10 | 0.22uF | Capacitor, Ceramic | 1206
21 | 1 | 0.33uF | Capacitor, Ceramic | 1206
22 | 51 | 1000pF | Capacitor, Ceramic | 1206
25 | 10 | 100pF | Capacitor, Ceramic | 1206
27 | 3 | 10uF | Capacitor, Ceramic | 1206
28 | 1 | 1uF | Capacitor, Ceramic | 1206
29 | 1 | 20pF | Capacitor, Ceramic | 1206
30 | 1 | 22pF | Capacitor, Ceramic | 1206
31 | 1 | 270pf | Capacitor, Ceramic | 1206
32 | 2 | 3900pF | Capacitor, Ceramic | 1206
33 | 2 | 47pF | Capacitor, Ceramic | 1206
35 | 2 | 6800pF | Capacitor, Ceramic | 1206
36 | 13 | 80R | Ferrite Bead | 1206
23 | 47 | 1000pF | Capacitor, Ceramic | 805
40 | 3 | 4.7uF | Capacitor, Electrolytic | 4x5.8
39 | 7 | 22uF | Capacitor, Electrolytic | 6.3x5.8
37 | 5 | 220uF | Capacitor, Electrolytic | 8x10
41 | 4 | 470uF | Capacitor, Electrolytic | 8x10
44 | 18 | 47uF | Capacitor, Electrolytic | 8x10
45 | 60 | 100pF | Capacitor, Feedthrough | 1206 |  | 478-11171-1-ND
46 | 1 | Battery_Cell | Coin Battery Holder | 1x20mm |  | 36-1066-ND
47 | 1 | KEYBOARD | DIN5, Female | - |  | CP-2350-ND
51 | 4 | S1MWF-7 | Diode, SMD | SOD-123F |  | RS1MWF-7DICT-ND
48 | 2 | 1N4148 | Diode, SMD | SOD-323 |  | 1655-1359-1-ND
50 | 1 | BAT54C | Diode, SMD | SOT-23 |  | 1655-1412-1-ND
52 | 1 | DB15_Female_HighDensity | DSUB 15 HD | - |  | AE11024-ND
53 | 1 | DB25_Stack_FemaleAndMale | DSUB 25 Stacked, Female Bottom/Male Top | - |  | AE10996-ND
54 | 1 | DB9_Male_Stack | DSUB 9 Stacked, Male/Male | - |  | L17H2110130-ND
55 | 2 | CY74FCT821T | Flip Flop | SOIC-24W_7.5x15.4mm |  | 296-CY74FCT821ATSOC-ND
56 | 4 | 4A | Fuse | 1206 |  | SF-1206S400-2CT-ND
57 | 1 | DS1813 | IC Supervisor | SOT-23 |  | DS1813R-5+CT-ND
58 | 2 | MMBFJ211 | JFET, SMD | SOT-23 |  | MMBFJ211CT-ND
63 | 2 | 74HCT00 | Logic | SOIC-14_3.9x8.7mm
65 | 1 | 74HCT04 | Logic | SOIC-14_3.9x8.7mm
66 | 4 | 74HCT08 | Logic | SOIC-14_3.9x8.7mm
68 | 1 | 74HCT14 | Logic | SOIC-14_3.9x8.7mm
71 | 2 | 74HCT32 | Logic | SOIC-14_3.9x8.7mm
73 | 2 | 74HCT74 | Logic | SOIC-14_3.9x8.7mm
76 | 1 | 74LS38 | Logic | SOIC-14_3.9x8.7mm
77 | 1 | SN75188DR | Logic | SOIC-14_3.9x8.7mm |  | 296-1276-1-ND
78 | 1 | SN75189DR | Logic | SOIC-14_3.9x8.7mm |  | 296-14957-1-ND
62 | 1 | 74F258 | Logic | SOIC-16_3.9x9.9mm
67 | 1 | 74HCT138 | Logic | SOIC-16_3.9x9.9mm
69 | 1 | 74HCT157 | Logic | SOIC-16_3.9x9.9mm
75 | 1 | 74LS148 | Logic | SOIC-16_3.9x9.9mm
59 | 4 | 74AHCT244 | Logic | SOIC-20W_7.5x12.8mm
61 | 2 | 74AHCT245 | Logic | SOIC-20W_7.5x12.8mm
70 | 6 | 74HCT245 | Logic | SOIC-20W_7.5x12.8mm
72 | 2 | 74HCT373 | Logic | SOIC-20W_7.5x12.8mm
79 | 1 | LF347 | Op Amp | SOIC-14_3.9x8.7mm
80 | 1 | 28.63636MHz | Oscillator | DIP-14 | 28.37516MHz for PAL | -
81 | 1 | RTC62423 | Real Time Clock | SOIC-24W_7.5x15.4mm |  | -
82 | 1 | MSM6242 | Real Time Clock (Optional) | DIP-18 |  | -
83 | 1 | 32.768KHz | Real Time Clock Crystal (Optional) | 3.2x1.5mm |  | SER4076CT-ND
86 | 1 | 10k | Resistor, Bussed Network | SIP10 |  | 4610X-1-103LF-ND
89 | 5 | 1k | Resistor, Bussed Network | SIP10 | RN700,RN701,RN702,RN703,RN704 | 4610X-1-102LF-ND
90 | 1 | 1k | Resistor, Isolated Network | SIP10 | RN802 | 4610X-2-102LF-ND
91 | 1 | 2.7k | Resistor, Bussed Network | SIP10 | RN101 | 4610X-1-272LF-ND
92 | 2 | 3.3k | Resistor, Bussed Network | SIP10 | RNX1,RNX2 | 4610X-1-332LF-ND
93 | 2 | 4.7k | Resistor, Bussed Network | SIP10 | RN100,RN705 | 4610X-1-472LF-ND
87 | 1 | 10k | Resistor, Bussed Network | SIP6 |  | 770-61-R10KP-ND
88 | 6 | 1k | Resistor, Bussed Network | SIP6 | RN205,RN301,RN607,RN800,RN903,RN908 | 4606X-1-102LF-ND
85 | 2 | 470R | Resistor, Bussed Network | SIP6 |  | 4606X-1-471LF-ND
95 | 1 | 4.7k | Resistor, Bussed Network | SIP8 |  | 4608X-1-472LF-ND
84 | 2 | 47R | Resistor, Isolated Network | SIP8 | RN102, RN902 | 4608X-2-470LF-ND
94 | 1 | 4.7k | Resistor, Bussed Network | SIP9 |  | 4609X-101-472LF-ND
96 | 1 | 1 0.5W | Resistor, SMD | 1206
97 | 2 | 1.2k | Resistor, SMD | 1206
98 | 10 | 10k | Resistor, SMD | 1206
99 | 4 | 10k | Resistor, SMD | 1206
100 | 2 | 10R | Resistor, SMD | 1206
101 | 10 | 1k | Resistor, SMD | 1206
103 | 1 | 1k | Resistor, SMD | 1206
104 | 1 | 1R | Resistor, SMD | 1206
105 | 1 | 1R | Resistor, SMD | 1206
106 | 1 | 2.7k | Resistor, SMD | 1206
107 | 1 | 200R | Resistor, SMD | 1206
108 | 5 | 22R | Resistor, SMD | 1206
109 | 1 | 22R | Resistor, SMD | 1206
110 | 3 | 30k | Resistor, SMD | 1206
111 | 2 | 330R | Resistor, SMD | 1206
112 | 2 | 360R | Resistor, SMD | 1206
113 | 2 | 390R | Resistor, SMD | 1206
114 | 11 | 4.7k | Resistor, SMD | 1206
115 | 3 | 4.7k | Resistor, SMD | 1206
116 | 1 | 47 0.5W | Resistor, SMD | 1206
117 | 2 | 470k | Resistor, SMD | 1206
118 | 5 | 470R | Resistor, SMD | 1206
119 | 2 | 47k | Resistor, SMD | 1206
120 | 9 | 47R | Resistor, SMD | 1206
121 | 15 | 47R | Resistor, SMD | 1206
122 | 1 | 6.2k | Resistor, SMD | 1206
123 | 5 | 68R | Resistor, SMD | 1206
124 | 1 | 68R | Resistor, SMD | 1206
102 | 47 | 1k | Resistor, SMD | 805
125 | 2 | DIP Socket | Socket, DIP 40 | DIP-40 |  | 3M5483-ND
126 | 1 | DIP Socket | Socket, DIP 42 | DIP-42 |  | -
127 | 4 | DIP Socket | Socket, DIP 48 | DIP-48 |  | 3M5484-ND
128 | 1 | DIP Socket | Socket, DIP 64 | DIP-64 |  | ED3764-ND
129 | 1 | PLCC Socket | Socket, PLCC 84 | PLCC-84 |  | 3M8411B1-ND
130 | 1 | 7C-28.63636MBB-T | Oscillator (SMD, Optional) | 5.0x3.2mm | 28.37516MHz for PAL | 887-1207-1-ND
131 | 1 | CY62167ELL-45ZXI | SRAM | TSOP-I-48_18.4x12mm |  | CY62167ELL-45ZXI-ND
132 | 3 | MMBT3904 | Transistor, NPN, SMD | SOT-23
133 | 2 | MMBT3906 | Transistor, PNP, SMD | SOT-23
134 | 1 | 22-47pF | Trimmer Cap (Optional) |  |  | 2447-GKG60015-ND
135 | 1 | LM339 | Voltage Comparator | SOIC-14_3.9x8.7mm

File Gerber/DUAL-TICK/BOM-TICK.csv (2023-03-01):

Comment | Designator | Footprint | LCSC
100K | R2 | R_0805_2012Metric | C149504
10M | R1 | R_0805_2012Metric | C26108
3.93216 MHz | Y1 | Crystal_HC49-U_Vertical | C2636250
0.1uF | C3,C4 | C_0805_2012Metric | C28233
74HC73 | U2 | SOIC-14_3.9x8.7mm_P1.27mm | C350539
3.2768 MHz | Y2 | Crystal_HC49-U_Vertical | C387612
6.8pF | C1,C2 | C_0805_2012Metric | C519942
74HC4060 | U1 | SOIC-16_3.9x9.9mm_P1.27mm | C5649

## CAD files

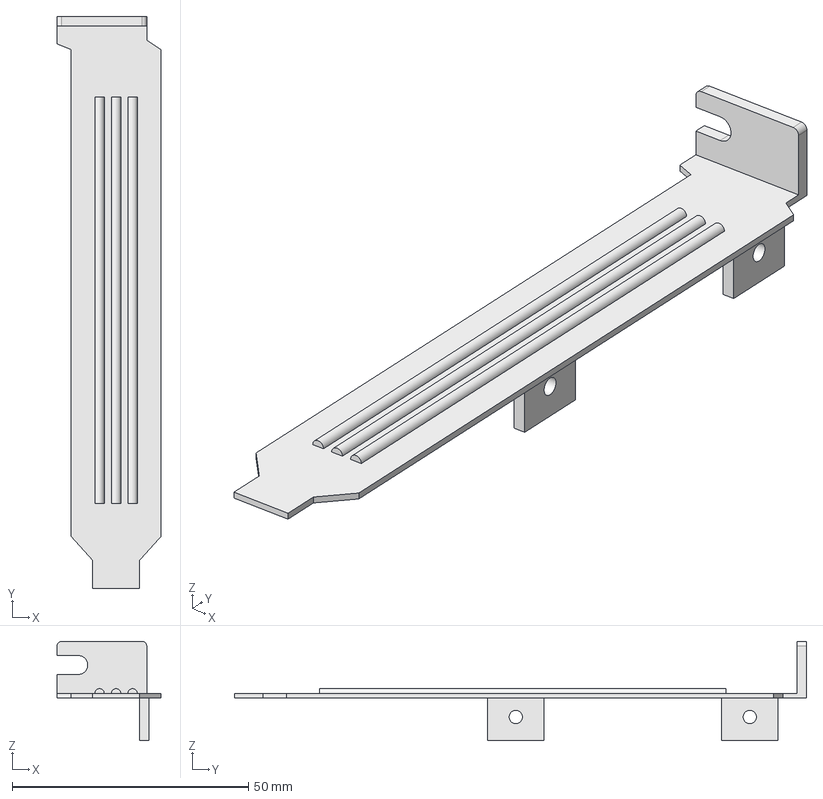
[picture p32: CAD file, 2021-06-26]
STL/A26x0_Adapter/A26x0 Slot Cover.FCStd
22.0 x 121.0 x 21.0 mm

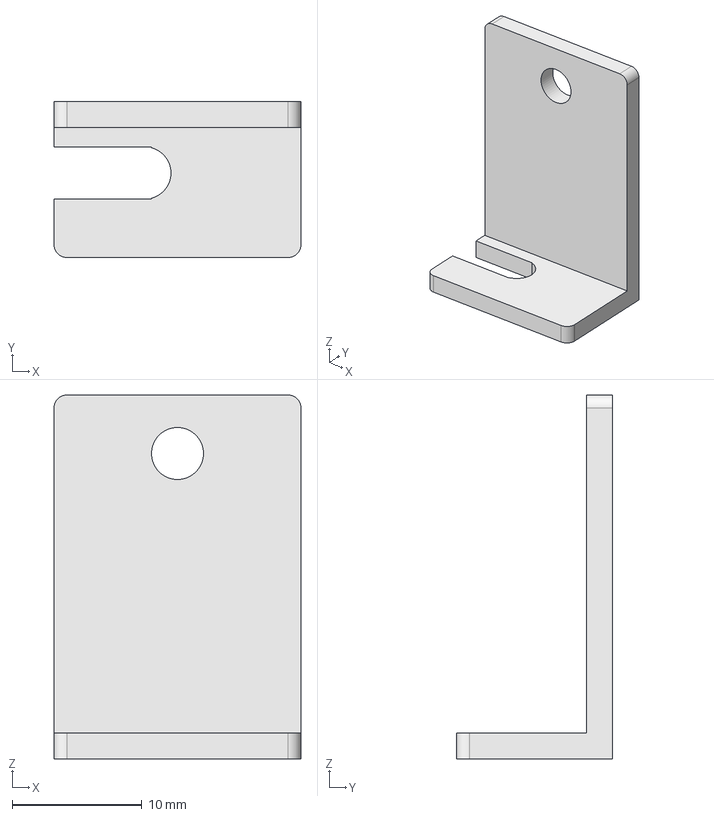
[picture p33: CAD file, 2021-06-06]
STL/COP-Simple-Adapter/COP-Adapter.FCStd
19.0 x 12.0 x 28.0 mm

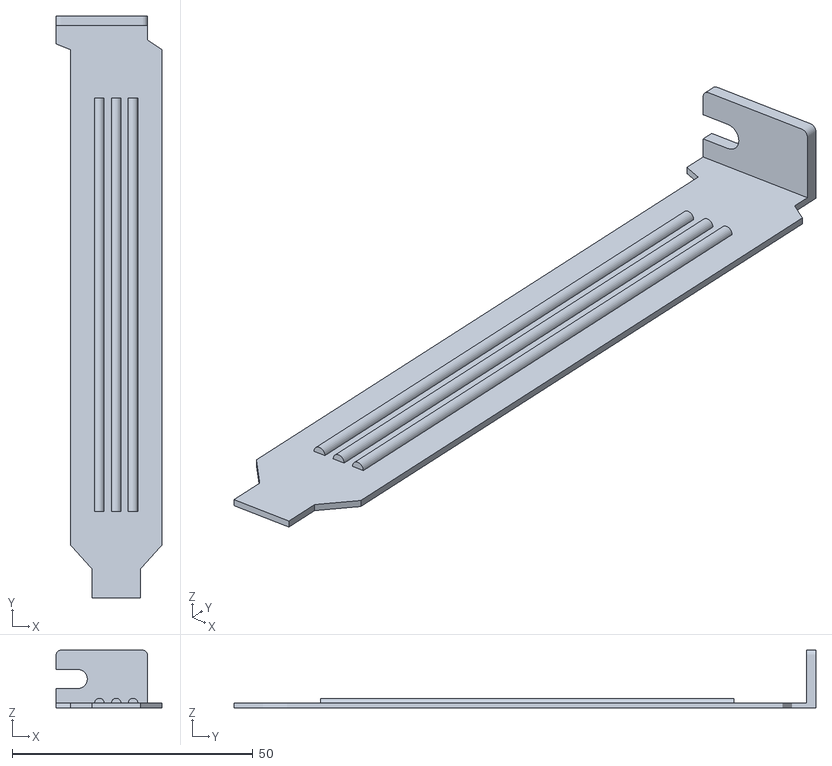
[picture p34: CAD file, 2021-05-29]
STL/Plain-Bracket/Amiga_EATX_Slot_Cover.stl
22.0 x 121.0 x 12.0

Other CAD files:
STL/Plain-Bracket/EmptyCover.FCStd
STL/A26x0_Adapter/A26x0-Slot-Cover.stl
STL/COP-Simple-Adapter/COP-Adapter.stl

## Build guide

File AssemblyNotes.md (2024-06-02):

# Assembly Notes, BOM, and Random Thoughts

IMPORTANT INFORMATION. It is highly recommended you read this entire page before assembling the Amiga 2000 EATX.

**Disclaimer:** This project is free and open source. It is a complex project and should only be undertaken by individuals experienced in SMD assembly techniques. No warranty or guarantee is offered that it will work for your particular situation. You assume all risk should you choose to build it.

This Amiga EATX PCB makes use of many modern surface mount components. These and the other standard components are available from most any good electronics supply house. In addition, you will need to obtain the legacy components shown in Table A1. 

Notes:
1. If you do not intend to use a bridgeboard or the ISA slots, you do not need to install the components shown in the ISA SUBSYSTEM silk screen.
2. When space was available, the values of components are listed on the PCB. In the event several components are placed together with the same value, the value may be shown once and the components will be marked together on the silk screen.
3. All end-of-life (no longer manufactured) components for this project are listed in table A1.
4. Always verify the orientation and location of all IC's before attaching. Never assume the orientation matches the original A2000.

## Where To Get Amiga Custom ICs and Legacy Parts

The best source of parts for this project is a dead or dying Amiga 2000 board. Otherwise, many of the Amiga legacy IC's and parts can be obatined from various internet suppliers. Unfortunately, Buster (MOS 5721) can be difficult to find. Beware the original Buster revision (318075-01) has a buffering error and cannot be used without a "Buster Tower". Be sure to use the one specifically listed in Table [A1](#table-a1-legacy-parts-required) or build a replacement option.

## Oscillator
You will need an oscillator installed at X1 or X2 to generate a clock signal. You can find 5V TTL oscillators from various legacy suppliers in the 14-DIP format. In the event you cannot find one, you can use a 3.3V CMOS oscillator of the same frequency in position X2. See Table [A1](#table-a1-legacy-parts-required). Do not populate both X1 and X2.

**Note on China sourced oscillators:** 
There are reports that some new 14-DIP oscillators sourced from China have an output enable signal on pin 1. Original 14-DIP oscillators have no connection on pin 1, thus pin 1 of X1 is not connected on the Amiga 2000 EATX board. If you have one of these oscillators and are not getting oscillations, or random system halts/crashes, you can try pulling pin 1 to logic high by temporarily bodging a resistor (<= 10k ohm) to pin 14 of X1. If that corrects the issue, you can make the bodge permanent.

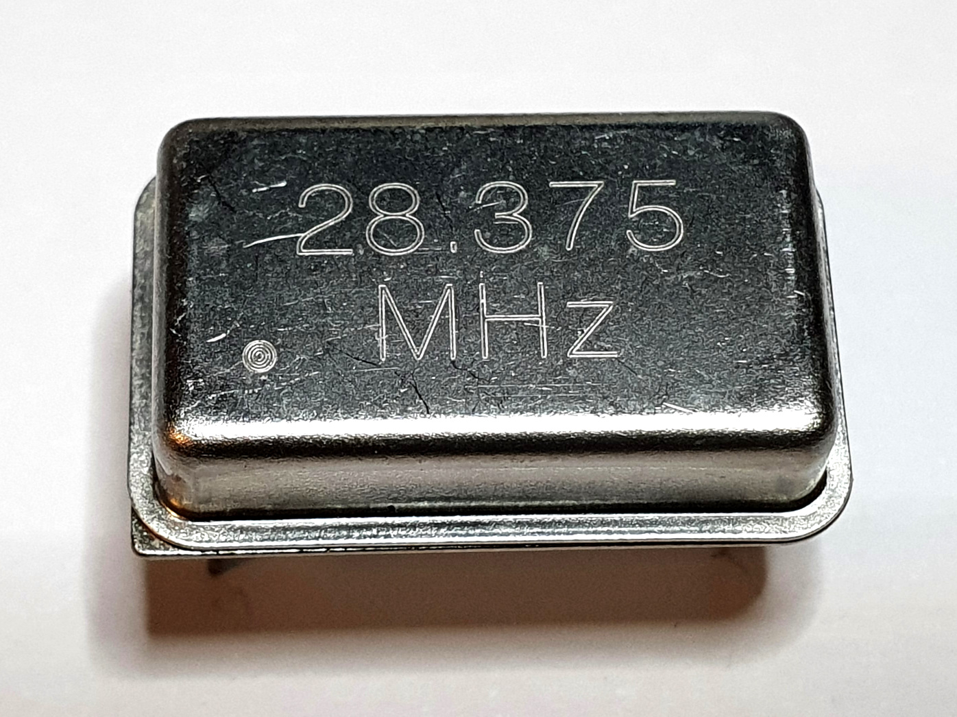
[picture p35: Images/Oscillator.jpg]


**Note on X2 CMOS oscillator:** 3.3v CMOS logic is compatible with in-spec TTL logic. My test board worked well with a +3.3V CMOS oscillator. All clock signals from Agnus are correct on my test machine. I would still recommend using like-for-like logic, if possible. Using the +3.3V CMOS oscillator should only be considered if a TTL oscillator cannot be reasonably obtained. 

## Configuring the Agnus Jumpers
The revision 2.x board supports multiple Agnus revisions. See Table [A2](#table-a2-agnus-parts-supported) for a list of part numbers supported. Not all the listed part numbers have been directly tested. Reviewing related literature suggests all the listed parts numbers *should* work. However, <b>until each specific part number is tested, there is no guarantee any particular Agnus will work</b>, even if listed. Table [A2](#table-a2-agnus-parts-supported) indicates the status of each part number. If you test a new Agnus part number, please place a new post in the issues tab so the table can be updated.

The Agnus solder pad jumpers are **not** configured from the factory. During board assembly, the jumpers defined in Table [A3](#table-a3-revision-2x-agnus-configuration-jumpers) must be configured for the specific Agnus part number to be used. The individual assembling the board must correctly short each jumper, as necessary. Failure to correctly do so will result in a malfunctioning board. Most of the configuration jumpers are on the back of the board, with only JA13 on the front of the board. See Images 1 and 2. The jumper pad locations are circled in red.

**Image 1.** Agnus Jumper Locations - Front

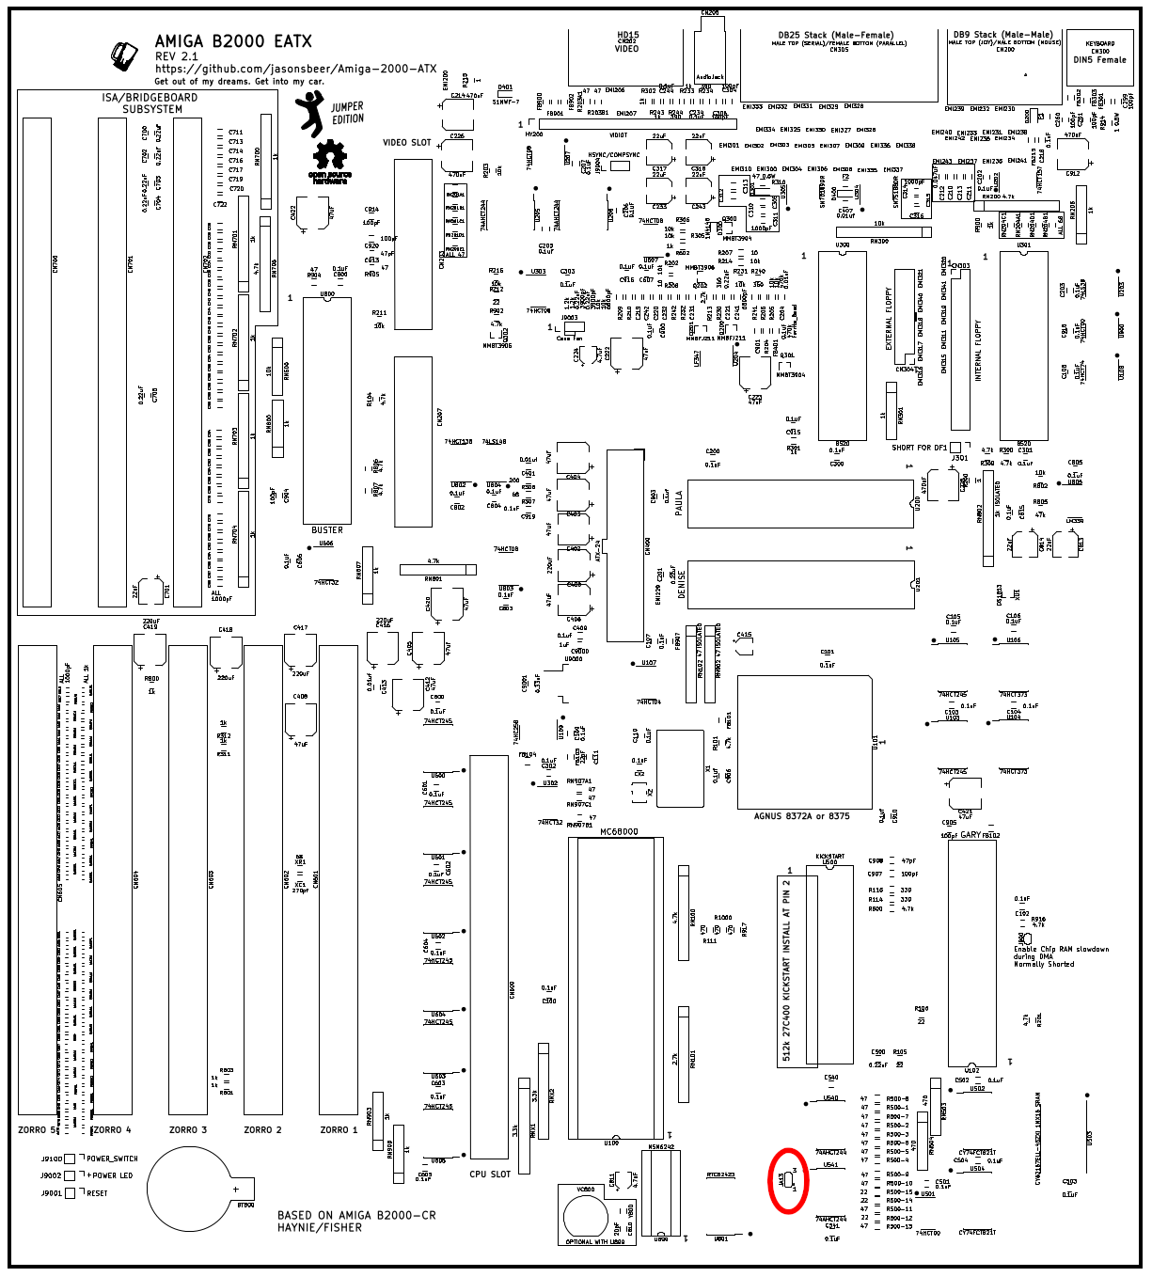
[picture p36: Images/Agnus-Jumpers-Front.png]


**Image 2.** Agnus Jumper Locations - Back

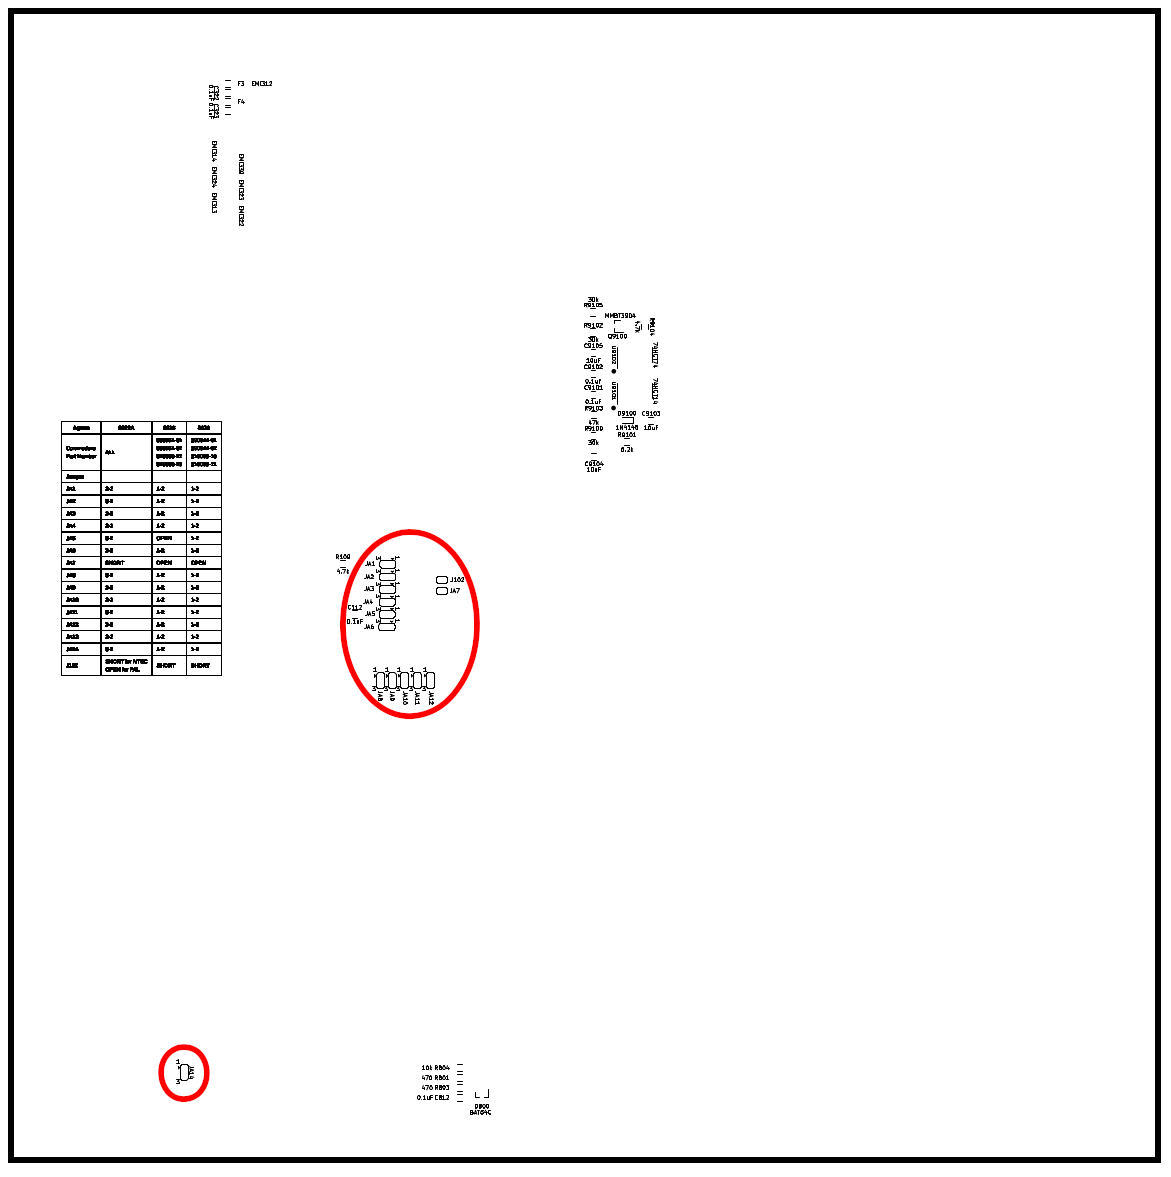
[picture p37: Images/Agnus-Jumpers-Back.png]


## SRAM Voltage
Due to lack of availability of +5V SRAM, the revision 3.0 board was set up for +3.3V SRAM. All other board revisions, including 3.1, come from the factory set up for +5V SRAM. The revision 3.x boards include jumper J503, which is used to set the SRAM voltage. It is important to note the voltage of your SRAM part and set J503 accordingly. It is recommended to use the +5V part on all revisions.

## TICK Header (J300)
The Amiga 2000 EATX (revision 2.2+) can support an externally or internally generated TICK. The factory default configuration for J300 is to short pins 1 and 2, which uses the _VSYNC signal from Agnus as the time base signal. For most configurations, the factory default is acceptable. However, if you intend to use video devices that replace the system clock via the _XCLKEN and XCLK signals, you should supply an external time base (TICK) signal. These types of video devices include genlocks, flicker fixers, and possibly others. See your product manual to determine whether this is of concern. Two accurate external TICK generators are included with this project and can be found in the [TICK](/TICK) folder. These devices are small boards with simple circuits intended to be installed directly on J300. For details on J300, see table [A6](#table-a6-tick-header-j300).

NOTE: You **MUST** jump pins 1 and 2 or install a TICK generator on J300 or your Amiga 2000 EATX will not function.

Revision 2.1 and earlier does not have a TICK header. In the event you need to add a TICK signal to an earlier revision, instructions for modifying revisions 2.1 and 1.2.1 can be seen [here](/Images/TICK-Convert.png). If power is needed, +5V can be drawn from pin 20 and ground from pin 1 of U300. You may also tap C300, if that is easier. It is recommended you make this modification only if it is required by your video hardware configuration.

## Kickstart Installation
The Amiga 2000 EATX is provisioned to accept 512k (27C400, 40 pin), 1MB (27C800, 42 pin), and 2MB (27C160, 42 pin) Kickstart EPROMs. The Kickstart socket (U500) is a 42 pin DIP footprint that supports all three types. A standard Amiga Kickstart ROM is based on the 27C400 EPROM. When installing a 27C400 EPROM, you must install it toward the bottom of the socket, leaving pins 1 and 42 of the socket empty. This is noted on the silk screen and will correctly align the pins. **Installing the 27C400 EPROM incorrectly may damage it!** Install 27C800 and 27C160 EPROMs as normal. Use of 1MB and larger EPROMs is considered experimental. Guides to create custom Kickstart ROMs can be found on Amiga community sites.



## Floppy Drive Headers
CN303 is a 34 pin header that is reponsible for the internal floppy drives DF0 and DF1. Pin 3 is a key. That is, factory Amiga floppy drive cables often have a pin socket blocked to ensure the cable is oriented correctly before installing. As such, it is recommended you remove pin 3 from the header before installing on the board. You can often pull it out with needle nose pliers. Alternatively, you can cut it off with a wire cutter.

CN304 is a 20 pin header that is reponsible for external floppy drives DF2 and DF3. This header provides 12V on pin 18. **Installing the cable backwards may result in damage to connected devices!** Thus, the BOM includes a keyed, shrouded connector that will help prevent incorrect installation when used with a keyed cable. To use external drives, an adapter cable will need to be created. See Tables [A4](#table-a4-external-floppy-drive-header-cn304) and [A5](#table-a5-amiga-db23-external-floppy-pinouts).

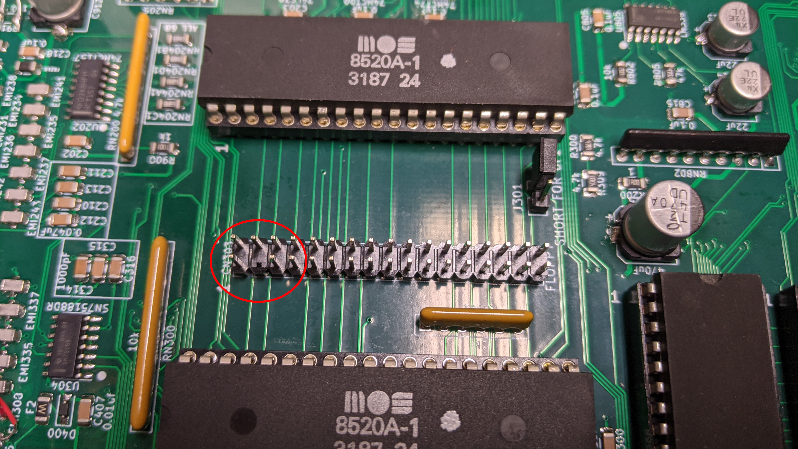
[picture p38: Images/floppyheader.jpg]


## Real Time Clock

There are two options for the real time clock (RTC). You can install the original Amiga RTC circuit based on the MSM6242 or a simpler circuit based on the RTC-62423A. The MSM6242 based circuit requires tuning of the trimmer cap to dial in the correct timing. The RTC-62423A circuit does not require tuning. This sacrifices accuracy, in that the RTC-62423A may drift over time. It is up to the user to decide which option is more appropriate for their needs.

When installing the MSM6242 circuit, include components Y800, C810, and VC800. When installing the RTC-62423A circuit, Y800, C810, and VC800 are omitted.

## BOM
The individual line items of non-legacy components with Digi-Key and manufacturer part numbers can be found [here](/BOM/Amiga_2000_EATX_REV22_SHOPPINGLIST.csv). This file can be used as a reference for ordering. This CSV file can be uploaded into your Digi-Key cart, automatically adding the required items to your cart. It will also tell you when bumping the quantity to the next price break will save you money. Quite nice! Note that some items are optional, depending on your desired configuration.

Each individual component and PCB reference can be found [here](/BOM/2000EATX-REFERENCE_REV22.csv). This is a useful reference for placing parts, especially for those locations where labeling the component value was not possible.

In addition to the items in the BOM, you will need to obtain the legacy components shown in Table A1. Select a single oscillator that matches the video standard you desire.

## Locating Components on the PCB
You should download the interactive BOM, which will help you locate components on the board. It can be found [here](/BOM/Amiga2000EATX-ibom.html). Download the file and open it in your browser.

## Component Orientation

### Diodes
There are a few single diodes on the board. They are designated Dxxx and marked with a rectangle with one open side. The closed side indicates the cathode. This is often marked on the diode body with a solid line.

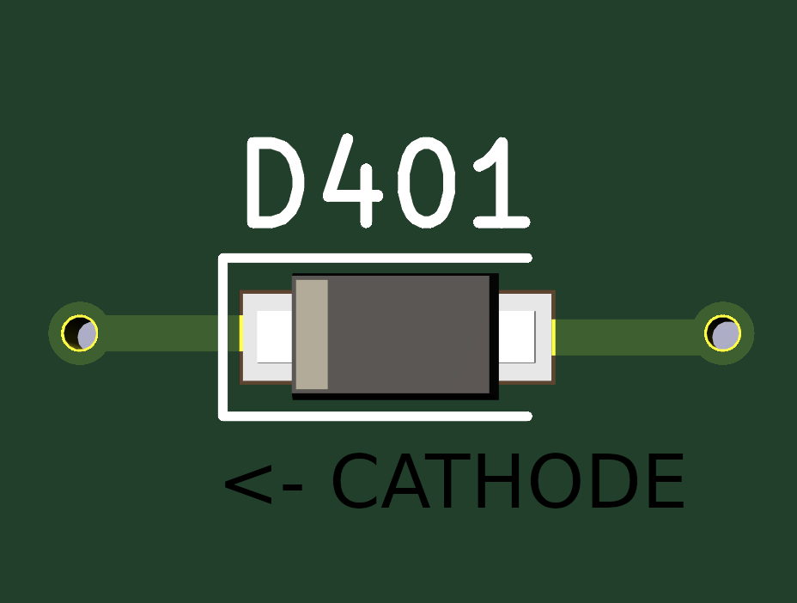
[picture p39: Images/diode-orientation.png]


### Capacitors
The electrolytic caps on the board are polarized and must be installed correctly. Electrolytic caps have a black mark that indicates negative (-). Positive (+) is marked on the board. Align the black side away from the + mark. Ceramic capacitors are not polarized and may be installed in either direction

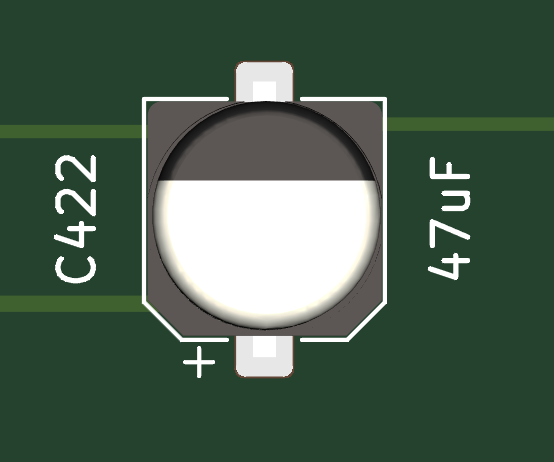
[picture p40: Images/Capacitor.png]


### Surface Mount IC's
Pin 1 of surface mount ICs may be marked in a number of different ways. A small circle, notch, line, or text alignment can indicate pin 1. If in doubt, check the data sheet. A small circle marking pin 1 has been placed next to each surace mount IC on the board to assist with orentation. There are also lines drawn across the top and bottom of the SMD position. The longer line indicates pin 1. 

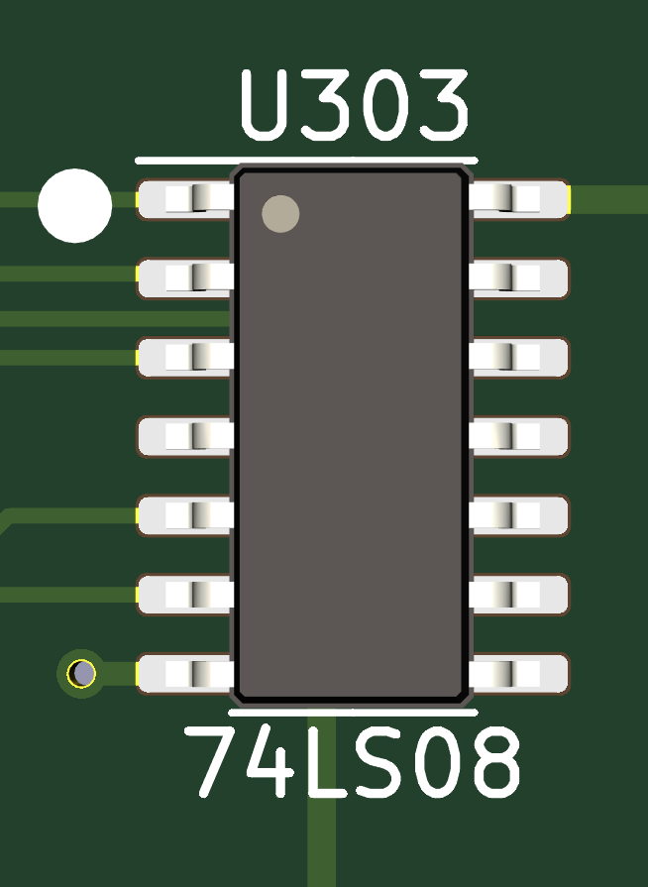
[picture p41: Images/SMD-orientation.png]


### Through Hole IC's
Throught hole IC's have a square pad and a "1" marking pin one. Pin one is usually indicated with a small notch on one end of the IC body. Occasionally, there may be a small circle on the IC body indicating pin 1.

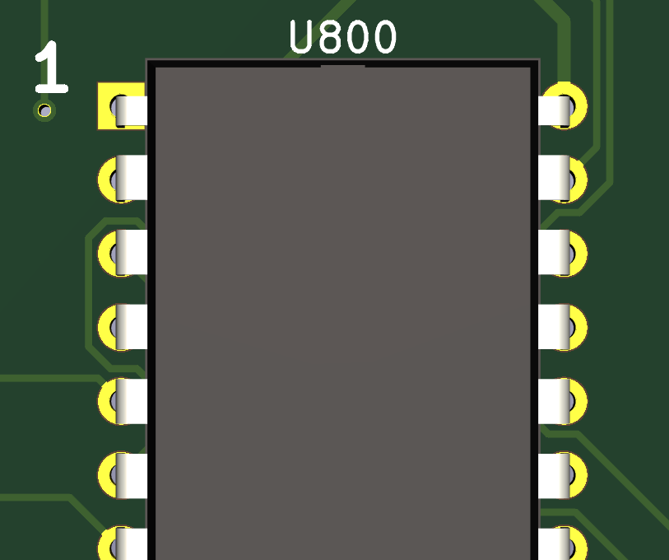
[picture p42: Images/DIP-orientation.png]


### Solder Pad Jumpers
Solder pad jumpers are present on the board. In the event there are only two pads for the jumper, you will place a solder blob across the two pads to short them when necessary. In the event of a 3 pad jumper, the solder blob must be placed between pad 2 (the center pad) and either pad 1 or 3, as defined in Table A3. Pad 1 is marked with a small arrow and the numeral "1" on the silkscreen. Pad 3 is marked by a number "3" on the silkscreen.

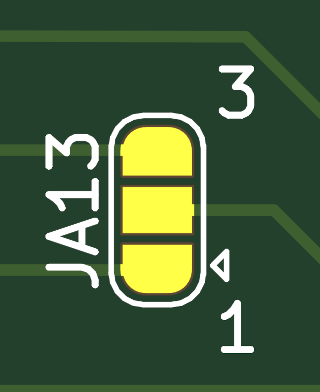
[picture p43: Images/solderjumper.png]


## Tables

### Table A1. Legacy Parts Required
Common Name|Designation/Part Number|Postion|Package|Notes
-|-|-|-|-
Motorola 68000|MC68000|U100|DIP-64| 8MHz or greater
Fatter Agnus|See Table A2|U101|PLCC-84|
Gary|MOS 5719|U102|DIP-48|
Paula|MOS 8364|U200|DIP-48|
Denise|MOS 8362 or CSG 8373|U201|DIP-48|[Deniser](https://github.com/endofexclusive/deniser)
CIA|MOS 8520A, 8520A-1, 8520R2, or 8520PD|U300 and U301|DIP-40|These are all interchangeable
Buster|MOS 5721/318075-02|U800|DIP-48|[Bluster](https://github.com/LIV2/Bluster)
Kickstart|Commodore ROM or Burned 27C400/V1.2+|U500|DIP-40|Various Amiga suppliers sell ROMs ready to use
Video Hybrid|Commodore 390229-0x|HY200|SIP-22|[Video Hybrid](https://github.com/SukkoPera/OpenAmigaVideoHybrid)
Real Time Clock|RTC-62423A|U801|SOP-24|"A" revision is more accurate, but non-A version can be used
Optional Real Time Clock|MSM6242|U899|DIP-18|This is the original, tunable RTC from the Amiga
28.636363 MHz Oscillator|NTSC Oscillator, 5V TTL|X1|DIP-14|Alternatively, populate X2 with a 5.0x3.2mm footprint 3.3V CMOS oscillator
28.37516 MHz Oscillator|PAL Oscillator, 5V TTL|X1|DIP-14|Alternatively, populate X2 with a 5.0x3.2mm footprint 3.3V CMOS oscillator

*Commodore IC's may be marked "MOS" or "CSG", or possibly neither in the case of contract runs. These are interchangeable by part number.

### Table A2. Agnus Parts Supported

Agnus|Commodore Part Number|Status
-|-|-
8372A|ALL|Tested and working
8375|390544-01|Tested and working
8375|390544-02|Tested and working
8375|318069-10|Tested and working
8375|318069-11|Tested and working
8375|390554-01|Unknown
8375|390554-02|Unknown
8375|318069-12|Unknown
8375|318069-13|Unknown

### Table A3. Revision 2.x Agnus Configuration Jumpers

Agnus|<b>8372A</b>|<b>8375</b>|<b>8375</b>
-|-|-|-
Commodore<br>Part Number|ALL|390544-01<br>390544-02<br>390554-01<br>390554-02<br>318069-12<br>318069-13|318069-10<br>318069-11
Jumper|||
JA1|3-2|1-2|1-2
JA2|3-2|1-2|1-2
JA3|3-2|1-2|1-2
JA4|3-2|1-2|1-2
JA5|3-2|OPEN|1-2
JA6|3-2|1-2|1-2
JA7|SHORT|OPEN|OPEN
JA8|3-2|1-2|1-2
JA9|3-2|1-2|1-2
JA10|3-2|1-2|1-2
JA11|3-2|1-2|1-2
JA12|3-2|1-2|1-2
JA13|3-2|1-2|1-2
JA14|3-2|1-2|1-2
J102|SHORT for NTSC<br>OPEN for PAL|SHORT|SHORT

1-2 = Short pads 1 and 2 together<br>3-2 = Short pads 3 and 2 together<br>SHORT = Short the two pads together<br>OPEN = Nothing is shorted

### Table A4. External Floppy Drive Header (CN304)

Pin|Signal|Pin|Signal
-|-|-|-
1|_RDY|11|DIR
2|_SIDE|12|_MTRX
3|_DKRD|13|_SEL3
4|_WPROT|14|_SEL2
5|GROUND|15|_DKRST
6|_TRK0|16|_INDEX
7|GROUND|17|_CHNG
8|_DKWEB|18|+12V
9|_DKWDB|19|+5V
10|_STEP|20|GROUND

### Table A5. Amiga DB23 External Floppy Pinouts

Pin|Signal|Pin|Signal
-|-|-|-
1|_RDY|13|_SIDE
2|_DKRD|14|_WPROT
3|GROUND|15|_TRK0
4|GROUND|16|_DKWEB
5|GROUND|17|_DKWDB
6|GROUND|18|_STEP
7|GROUND|19|DIR
8|_MTRX|20|NC
9|_SEL3|21|_SEL2
10|_DKRST|22|_INDEX
11|_CHNG|23|+12V
|12|+5V||

### Table A6. TICK Header (J300)
Pin|Signal
-|-
1|_VSYNC
2|Time Base (TICK)
3|GROUND
4|_RESET
5|NC
6|+5V

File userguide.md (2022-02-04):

# User Guide

Here you will find basic information on final set up of your Amiga 2000 EATX computer. For information on building an Amiga 2000 EATX PCB, see [here](AssemblyNotes.md). For general information on the Amiga 2000 not covered here, refer to the [Amiga 500 and 2000 Technical Reference Manual](/DataSheets/Amiga_A500_A2000_Technical_Reference_Manual_1987.pdf).

## Case Considerations
When selecting a case, considerations must be made for accomodating full size plug in cards (PICs). The Amiga 2000 EATX motherboard is 12x13 inches (305 × 330 mm) in size and will fit any EATX or ATX case with sufficient room for this size PCB. Beware cases advertised as "EATX" that do not support full size EATX boards. Somewhere in the fine print, the specs will indicate "EATX up to *x* x *y*". These are not true EATX cases and may not support the Amiga 2000 EATX board.  

Full length plug in cards (PICs) for the Amiga 2000 are very large by today's standards. Zorro II PICs are up to 337.19mm in length, coprocessor cards up to 356 mm in length, and video slot PICs up to 210mm (see [Amiga 500 and 2000 Technical Reference Manual](/DataSheets/Amiga_A500_A2000_Technical_Reference_Manual_1987.pdf)). As you can see, full length Zorro II and coprocessor PICs exceed the maximum depth of the EATX specification (see [Enterprise Electronics Bay Specification](/DataSheets/SSI%20EEB%202011%201.0.1.pdf)). It is recommended you consider a case that has additional space between the "front" of the PCB and the case front in the slot area. This will allow room to accomodate full length PICs. EATX cases are already quite large, but may have permanent features that conflict with full length PICs. If the case has removable drive bays or an open area, you should be fine.

For the purposes of testing, the Phanteks Enthoo EATX case was used and will accomodate full length Amiga 2000 PICs. The lower two drive bays are removable and were removed to create extra space. This case is able to accomodate the A2630 coprocessor and A2090 SCSI/MFM Zorro II PICs. Both are full length. Unfortunately, this case is very large and may not be practical for casual use.

## Coprocessor and Video Slot Plug In Cards
The Amiga 2000 used a proprietary bracket for the coprocessor and video slot cards. These brackets are not compatable with standard card slot brackets. It is recommended you obtain or create a bracket adapter to accomodate the difference. I have supplied STL files so that you can print an adapter or replacement brackets for specific plug in cards. You can find the STL files [here](/STL/). Note that Zorro II plug in card brackets are standard brackets and do not require modification.

The board surface to surface clearance between the coprocessor and video slot is approximately 21mm. These two slots were not together in the original Amiga 2000. Because of this, there may be physical incompatabilities between certain cards.

<b>Special note on the A26x0 coprocessor cards:</b> These cards have a RAM expansion connector on the non-component side of the card. In the event you have this card, especially with a RAM expansion unit, it may interfere with the placement of a card in the video slot. 

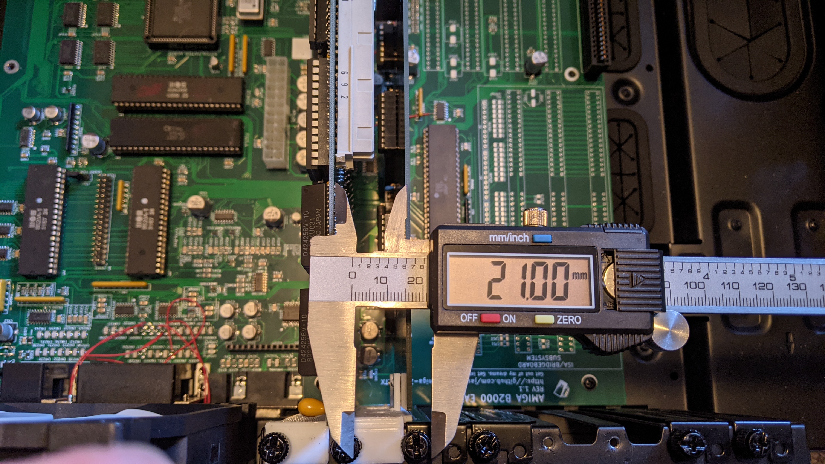
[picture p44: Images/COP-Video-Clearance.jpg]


## User Jumper Settings

Jumper|Description|Detail
-|-|-
J300|TICK Time Base|Jump Pins 1 and 2 (factory default). See [TICK](/TICK) for other options.
J301|DF1 Presence|Place jumper when using two internal disk drives.
J900|Chip RAM DMA Slowdown|Solder Pad set to factory default.
J9001|Reset|Attach EATX case reset switch.
J9002|Power LED|Attach EATX case power LED.
J9003|Case Fan|Attach 12V cooling fan.
J9004|HSYNC/COMPSYNC|Sends Composite Sync or HSYNC on video port.
J9100|Power Switch|Attach EATX case power switch.

Jumper Locations (click to enlarge)

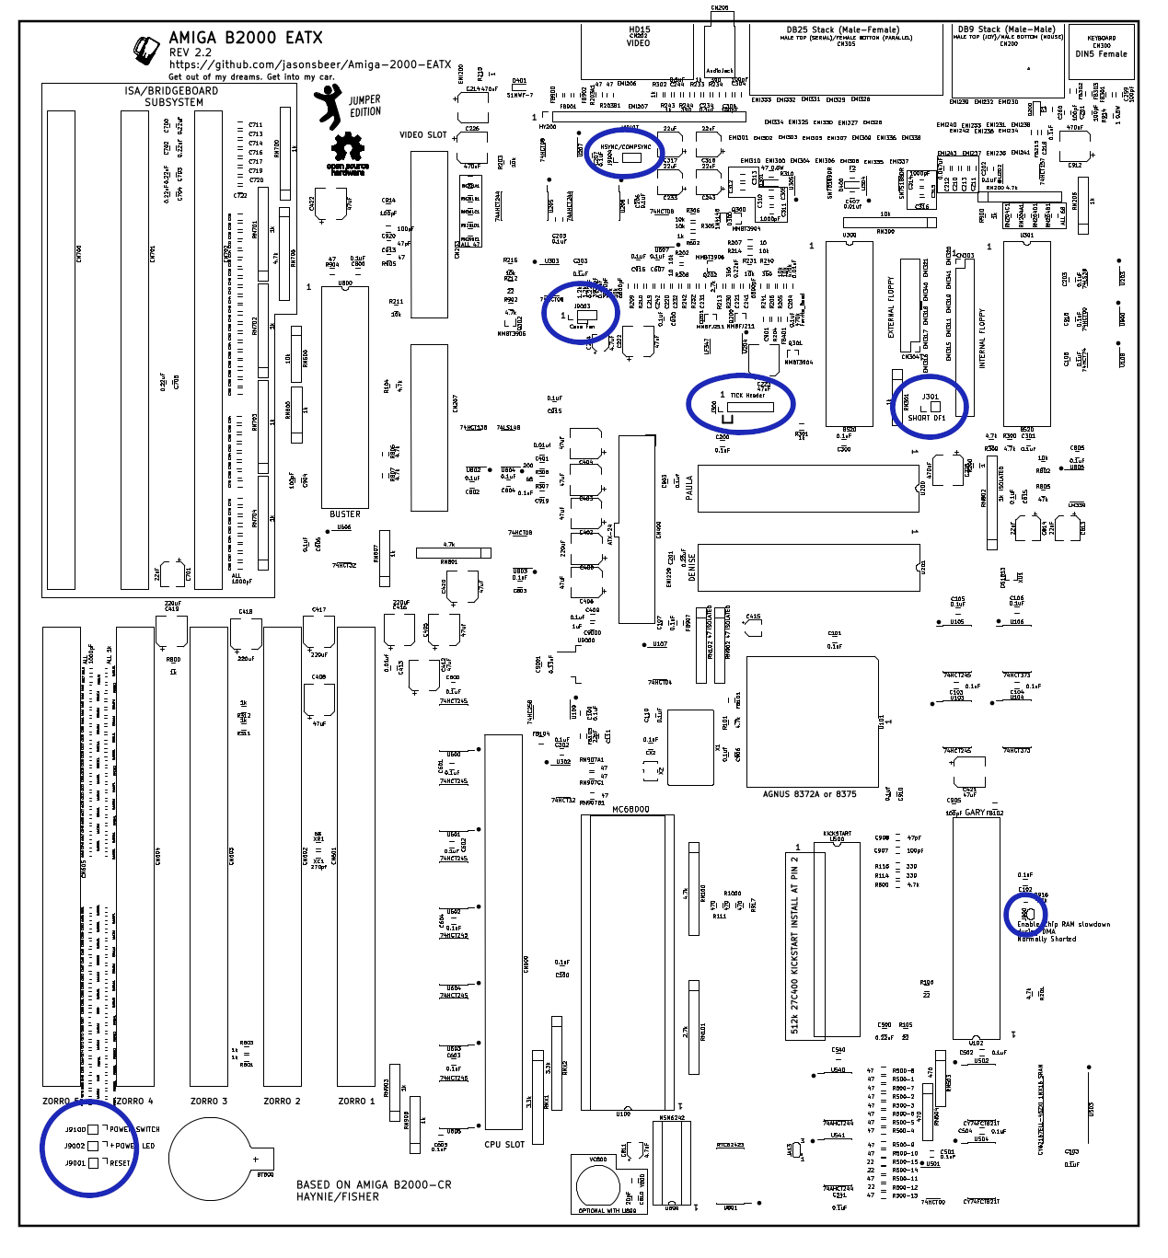
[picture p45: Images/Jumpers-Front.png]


## Connecting your Amiga 2000 EATX
You will need a computer case that will accept EATX boards as well as an ATX power supply (see Case Considerations, above). Connect the Amiga 2000 EATX as you would any other ATX board.

1. Ensure the power supply is not plugged in.
2. Mount the Amiga 2000 EATX mother board to the case.
3. Attach the ATX power supply connection to the power connector on the computer board.
4. Attach the case power button, reset button, and power LED to J9100, J9001, and J9002, respectively.
5. Attach case fan to J9003.
6. Set J9004 to HSYNC or COMPSYNC based on video output needs (see Video, below)
7. Attach floppy drive(s) with the appropriate ribbon cable to CN303, noting pin 1.
8. Attach power supply connections to any peripherals.
9. Attach keyboard, mouse, and 15KHz video.
10. Power up system.

## Connectors/Ports
The Amiga 2000 EATX is intended to be used with legacy Amiga keyboards and mice. In the event you do not have those, there are options to use PC mice and keyboards. Discussion of those options is not in the scope of this project or document. A search of Amiga specific community sites will yield useful information in that regard.

### Video
The video port supplies a 15KHz analog RGB signal via the HD15 connector. The pins are in the standard VGA configuration. Use a standard VGA cable to connect to a 15KHz compatable monitor or conversion box.

Certain video adapters, such as the GBS 8220, require a composite sync signal instead of the HSYNC signal. If you are using such an adapter, you can provide composite sync on pin 13 of the video port by setting J9004 to COMPSYNC. Set J9004 to HSYNC when using 15KHz compatble VGA monitors or video adapters that support HSYNC and VSYNC. See Table 1.

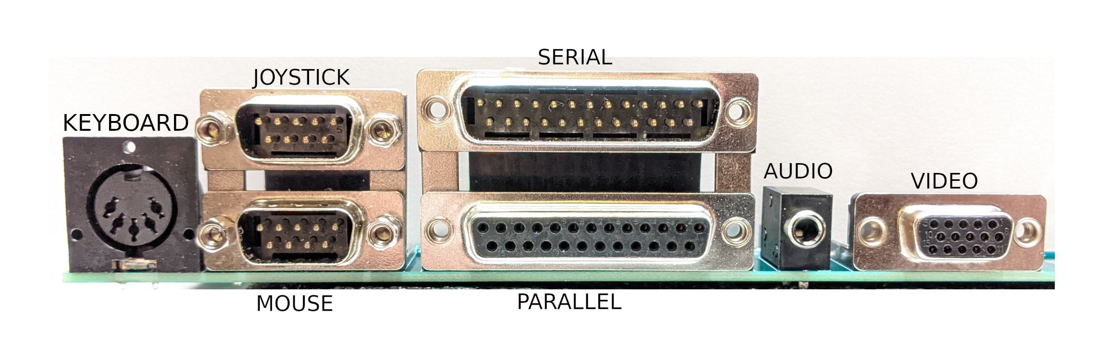
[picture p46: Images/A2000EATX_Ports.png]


## Floppy Drive(s)
The Revision 2.x board has two floppy drive headers. CN303 is for the internal drives (DF0 and DF1) and CN304 is for external drives (DF2 and DF3). The discussion below refers to the internal drives header (CN303). In order to use the external drive header, you will need to build a cable to DB23 connector. Refer to the assembly notes for further information.

The Amiga uses a 34 pin cable to attach up to two internal floppy drives or floppy drive emulators to CN303. The Amiga floppy cable is different from a PC floppy cable. The cable must be oriented and drives attached in the correct order for full functionality. Ensure correct alignment of pin 1 at each connection.

### Setting Device IDs
The Amiga requires the device ID be designated on the floppy drive. This is accomplished through the use of jumpers on the drive. Drive DF0 must be jumpered as S0. DF1 must be jumpered as S1.

### Connecting One Floppy Drive
To connect one floppy drive (DF0), use any straight through 34 pin cable. In the event you are using an Amiga two drive cable, use either connection.

### Connecting Two Floppy Drives
Drive DF0 must be at the end of the cable, past the twist. DF1 must be physically first on the cable, before the twist. In the event the drives are reversed on the cable, the drive lights will not operate independently.

### Amiga Floppy Cable Twist
To build an Amiga floppy cable, the first connection is straight through. Conductors 4-6 are twisted before the second connection.

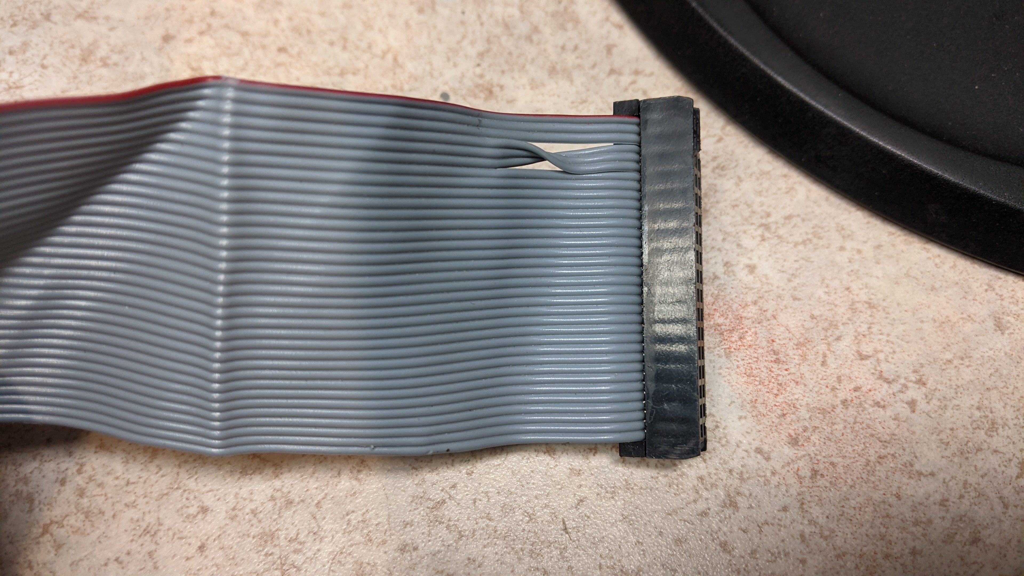
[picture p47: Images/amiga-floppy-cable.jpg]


## Powering Cards and Hardware
The +12V pins on the card slots will support approximately 2.5 amps total on the Zorro slots and 1 amp total on the ISA slots. If you intend to use multiple high current draw devices, such as mechanical hard drives, it is recommended you power them directly from the power supply. The +5V pins will support approximately 2.5 amps per slot. The -5V and -12V pins will support approximately 1 amp total between all slots.

## Resetting Your Amiga 2000 EATX
On an Amiga keyboard, the Left Amiga-Right Amiga-Ctrl keys are pressed simultaneously. This signals the computer to complete any pending tasks and then reset. You also have the option to use the reset button on the computer case. Pressing this button will activate the same signals internally and will result in a reset in the same way. This is especially useful if you do not have an Amiga keyboard.

## Tables

Table 1. Video Port

Pin|Signal|Pin|Signal|Pin|Signal
-|-|-|-|-|-
1|Red|6|GND|11|NC
2|Green|7|GND|12|NC
3|Blue|8|GND|13|HSYNC or COMPSYNC
4|NC|9|NC|14|VSYNC
5|GND|10|GND|15|NC

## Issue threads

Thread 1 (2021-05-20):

Issues with the SRAM Circuit

LIV2, 2021-05-20:
Hi @jasonsbeer, Great project! I can't wait to build one!

Just thought I'd note that the published circuit for Kai's SRAM board is incorrect and doesn't work properly, I poked it a bit to troubleshoot why and got it working in the end but the changes ended up slipping through the cracks and weren't upstreamed at the time - I'll try to sort that out.

I've attached the schematic I came up with after bodging up the board to make it work, if you've already submitted this rev for manufacturing an easy way to work around this would be to use something like my 2MB Agnus adapter and the relevant agnus with this board as it provides it's own ram.
I'd be happy to donate an assembled adapter to help with this project if you'd like, you'd just need to get your hands on an 8375 Agnus

[sram-sch.pdf](https://github.com/jasonsbeer/Amiga-2000-ATX/files/6517884/sram-sch.pdf)

jasonsbeer, 2021-05-20:
@LIV2

Thank you for this valuable information. Unfortunately, fabrication of the current revision is nearly complete. I will need to include your proposed changes in a new revision. Any speculation on why the original circuit does not work?

Thank you for your generous offer of the Agnus adapter. Unfortunately, I do not have an 8375. I think is is unlikely I will be able to obtain one. They seem rarely available and expensive when they are.

jasonsbeer, 2021-05-21:
Hi @LIV2

I reviewed the schematic you supplied. Obviously, there are differences between the Rev 6.x A2000 and the A500+ in the amount of chip ram that can be addressed. The A500+ (with 8375) supplies signal DRA9  and has 10 memory address lines. The 1 MB Agnus does not supply signal DRA9 and has 9 memory address lines.

I'm thinking the best solution is to use a different SRAM IC. 256k x 16 memory chips have 18 address lines, so they match up well that way and we do not have extra address connections we need to figure out. One example is attached. Happy to hear your thoughts. Thanks!

[AS6C4016.pdf](https://github.com/jasonsbeer/Amiga-2000-ATX/files/6519684/AS6C4016.pdf)

LIV2, 2021-05-22:
Hey @jasonsbeer
I hadn't even thought about DRA9 that's a good point!

2*256Kx16s would work well, a 512Kx16 would work too and would mean that the OR gate (U3 in the original design) is no longer needed, you'd be able to just connect _sramce to the srams chip select I think

The changes I made to the design and why, also relevant the timing diagrams [Here](https://www.techtravels.org/a500-dram-card/)
* Added second latch (U7) for upper address bits - As shown on the timing diagram, the address pins change while CAS is still asserted, but we need to keep the address stable while SRAMCE is active
* Removed RAS from SRAMCE so it's just CAS - As shown on the timing diagram, RAS deasserts early which means SRAMCE would deassert before the ram cycle is complete, CAS always comes after RAS so RAS isn't needed as part of the SRAMCE equation anyway
* MA8 was not connected to the ram, A8 was connected instead to both pins 19 and 28 of the SRAMs
* Because CE's are NAND'ed with the BDRA9 which isn't latched, this will also cause _ceu4/5 to deassert when the address bus changes, in my updated design the nand input uses MA19/INVMA19 instead which are latched by U7 so they remain stable throughout the memory cycle

texneus, 2021-05-22:
Hi @LIV2 , I've been consulting @jasonsbeer on this issue.  Thanks for providing this data.  I took a preliminary updated schematic provided by @jasonsbeer and marked it up based on your input and my reverse engineering of the A2000 chipram circuit.  If you have a chance, I wouldn't mind another set of eyes and an opinion if you think this more changes are needed.

Summary of changes:

- @jasonsbeer added a latch for the column address, latched on CAS (derived from /CASx inputs)
- Changed _SRAMCE so it is just an inversion of CAS.  SRAM is now selected independent of /RASx signals.
- A8 is tied to pin 19 and 28 of the SDRAM via the latches (depending on if A8 is the row or column address) (by @jasonsbeer)
- This would appear to be unique to using 2 chips, however /RAS1 is now latched (which will serve as A18*) based on the statement that "RAS deasserts early".  Effectively this will serve as the 19th address line to select which half of the SRAM will be accessed (functionally equivalent to asserting /RAS0 or /RAS1 which selects the top or the bottom row of DRAM chips).
- NOTE:  The OR circuit in your design is eliminated since we don't have an A19 or a second SRAM chip to address.

Question (while we're at it):  Do you know why the series resistors and pull ups are present in this circuit?  There are no stubs here so they don't seem to be necessary for bus termination.  The only reason I can think of would be because the original DRAMS presented too much of a load for 74xxx logic, or were needed to correct an impedance mismatch.  I suspect these can be removed as well.  I noticed they are not in your schematic, have you seen any ill effects from this?

*Based on the A500 schematics [here](https://www.amigawiki.org/dnl/schematics/A500_R6.pdf), it would appear /RAS1 and DRA9 are the same signal - see pin 56 of the Agnus chip, although it appears to me that either /RAS0 or /RAS1 would serve this function.

[IMG_20210522_0001.pdf](https://github.com/jasonsbeer/Amiga-2000-ATX/files/6526717/IMG_20210522_0001.pdf)

LIV2, 2021-05-22:
Hi @texneus

All of the above looks correct to me and I believe that if implemented as described it should work well.
I'd probably spec something like 74AHCT244's instead of HCT for U540/541 though as it has a prop delay closer to the original's F244s and the timing may be critical.

> Question (while we're at it): Do you know why the series resistors and pull ups are present in this circuit? There are no stubs here so they don't seem to be necessary for bus termination. The only reason I can think of would be because the original DRAMS presented too much of a load for 74xxx logic, or were needed to correct an impedance mismatch. I suspect these can be removed as well. I noticed they are not in your schematic, have you seen any ill effects from this?

For the A500+ SRAM board this wasn't a consideration - since it plugs into an A500+ mainboard which would already have the resistors etc.
I'm not 100% sure what they're used for but the 74F244's in the original A500/2000's have quite a fast transition time and strong drive current so any impedance mismatching, ringing etc might be bad enough to damage the old DRAMs they used back then.
I'd probably leave it in the design just in case there are other concerns like stability etc.

> *Based on the A500 schematics here, it would appear /RAS1 and DRA9 are the same signal - see pin 56 of the Agnus chip, although it appears to me that either /RAS0 or /RAS1 would serve this function.
Yep exactly, either one works for this purpose just fine

jasonsbeer, 2021-05-22:
Great discussion! I very much appreciate both your time on this. I have no doubt we have a solid plan and I will make these changes on the next revision. Now...how to bodge this together on the current revision...

I'll leave this issue open until we have a working prototype in hand.

jasonsbeer, 2021-07-06:
This circuit was implemented on Rev 1.1 and seems to work perfectly, according to diagrom.

Thanks everyone for your help!

Closed 2021-07-06.

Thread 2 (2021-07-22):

Commodore A2000 Schematic Errata

jasonsbeer, 2021-07-22:
Putting this here for posterity. The Amiga B2000 schematics have an error related to the connections of CN300 (the keyboard DIN socket). The pins are mirrored on the Commodore schematic. Using the Commodore connections will cause R914 to burn up. These bad pin outs were carried on to the A3000 schematics.

**Correct, as used in the Amiga 2000 EATX.**
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

**Incorrect, as in the Commodore schematics.**
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

jasonsbeer, 2021-07-22:
This was informational.

Closed 2021-07-22.

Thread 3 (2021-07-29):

RTC-62423 accuracy is likely much worse than the original design

darrenfreeman, 2021-07-29:
The RTC-62423 datasheet specifies the frequency accuracy to be 20 ppm for the 62423A version, and 50 ppm for the 62423. This is really lousy compared to what you can achieve using a trimmer capacitor and a frequency counter. It might be even worse if the chip is decades old.

To put this into perspective, a 1 ppm error is one second over 11.6 days. So the non-A version could be out by one minute per fortnight. If you're using your A2000 only occasionally, it will be really noticeable every time you go to use it. And there's no way to adjust that.

I'm sure Commodore would have trimmed them all in the factory. This substitute is really a step down from the original hardware. If you need access to a frequency counter, go to an amateur radio club and ask nicely, someone will be happy to trim it to <1 ppm for you. (And now you have a new friend.) Or you could monitor whether it is running fast or slow compared to other clocks, and tweak it as needed.

Could you please include the component footprints needed for the capacitors and watch crystal, for those who want to use a part with a trimmable external oscillator? I am looking at a "parts only" A501 on eBay, and thinking that a through-hole footprint for the chip would be a helpful addition, alongside the SMD version.

jasonsbeer, 2021-07-30:
Adding worst case scenario notes for future reference...

62423A may lose just over 10 minutes per year
62423 may lose just over 26 minutes per year

darrenfreeman, 2021-07-31:
A DIP footprint would also be helpful if someone comes up with a replacement, e.g. a modern RTC with some translation to the 4-bit interface.

darrenfreeman, 2021-07-31:
BTW I really admire what you've done, I can't wait to build one.

jasonsbeer, 2021-08-02:
> BTW I really admire what you've done, I can't wait to build one.

Thanks!

jasonsbeer, 2021-09-26:
Revision 2.0 now includes the option of installing the original Amiga RTC circuit with the MSM6242 or using the RTC62423 design, which is simpler, but less accurate.

Closed 2021-09-26.

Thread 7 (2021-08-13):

Bom and CPL files for components

kipper2k, 2021-08-13:
Hi, Great work, i would like to give this board a build but TBH i don't want to fiddle with the small components. Is there a BOM and CPL file with the gerbers available so i could get the board partially assembled. Without the .Brd file i cant generate the X and Y coordinates, the only way i could do it is to put in gerber viewer and manually do it (Ouch). Even basic CPL with the coords listed would be a headstart. If i generated the assembly files i would upload to this project page for others to use.

thanks  Brian (Kipper2k)

Acill, 2021-08-13:
I generated a CPL file, but I cant get the BOM to generate correctly. Here
is the CPL. I only edited the headers for jlcpcb on the top file. You will
need to open the top and look at headers and rename them for bottom if you
dont want to hand assemble the few parts on the bottom yourself. IF anyone
can get a BOM that works at jlcpcb please let me know as well!

-Paul (Acill) Rezendes

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

kipper2k, 2021-08-13:
Thanks for the reply. The BOM is not that bad to do for JLC, it is just very picky with upper case, spaces and commas etc. if there is a mistake then the BOM generation just stops without any clue as to why.  Did you post the CPL, i cant see it ?

Acill, 2021-08-13:
I was able to do the BOM.

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

Acill, 2021-08-13:
Seems I can post the files. If Jason has it set for no uploads from outside
users. If you email me at ***@***.*** I can send you them.

-Paul (Acill)

On Fri, Aug 13, 2021 at 7:30 AM Paul Rezendes ***@***.***>
wrote:

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

kipper2k, 2021-08-13:
hi, can you send to kipper2k@shaw.ca

thanks

jasonsbeer, 2021-08-13:
Hi everyone....I'm not sure why you can not drop files in your replies. I have not intentionally blocked it. In fact, others have posted files to other issues. I can look into it later when I get home.

jasonsbeer, 2021-08-14:
I don't see how to affect changes to the upload settings for the issues tab. If you are unable to attach files, maybe you have an idea of what to look at and I can follow up. I would very much like to include the files you are working on for PCB assembly. I'm sure others will find them useful.

Thanks

mikebetz42, 2021-09-01:
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

Could you send me a copy of the files please?

mikebetz42 at hotmail dot com

Thank you,

Mike

jasonsbeer, 2021-11-15:
Closing this due to lack of discussion for some time.

Closed 2021-11-15.

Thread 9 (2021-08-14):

Tick signal

seb132, 2021-08-14:
Hello Jason - what a nice project you did here!
How is the tick signal dealt with ? I see you recommend a standard ATX PSU, and you mention how the -5V is generated but what about the tick signal ? Is it onboard too ? Thanks ! (might not be an issue, after all... haha)

jasonsbeer, 2021-08-14:
TICK is replaced by _VSYNC from Agnus. This is how it's done on the Amiga 500 and jumper J300 can set this on the original Amiga 2000. I will add a comment to the build page about this.

Closed 2021-08-14.

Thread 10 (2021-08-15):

Questions about pcb

nobodyisinocent, 2021-08-15:
Hello,

I have downloaded the Kicad project. What you have done is really great !
There are some holes which are not connected like the Int6 signal onto the Zorro slots.
The 3v3 pins of the power connector are not connected also.

Is it normal that there are some missing tracks  as shown in the pictures below ?

Int6 signal:
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

3v3 signal:
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

Kind regards,
Franck

nobodyisinocent, 2021-08-15:
To be conform to the schematics, the Int6 holes should be connected. Something like that: :-)

![Uploading image.png…]()

nobodyisinocent, 2021-08-15:
I assume you used Freerouting for generating the tracks.
This software is excellent, but the optimization batch can have some weaknesses.
Like the original tracks dispositions on CN600 for example. On the left the automatic rooting, and on the right a manual modification of the tracks.

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

I'm actually trying to optimize the pcb of your fantastic project ! :-)

nobodyisinocent, 2021-08-15:
A little work of rooting optimization around U102.
Here, the original rooting:
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

Here, the modified rooting:
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

nobodyisinocent, 2021-08-15:
Around beautiful ANGUS ! :-)
Before:
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

After:
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

jasonsbeer, 2021-08-15:
The _INT6 signal is connected correctly in the supplied files. Perhaps something was disconnected during your optimization work.

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

The 3.3V taps don't need to be tied together. I probably should have removed them from the schematic, but chose to ignore them instead. Only X2 uses 3.3V and that's connected properly. So, it is as expected.

The board is completely routed by hand. I did not take the time to review everything for optimization. My thought, if it works, let it be. I'll look at your suggestions for consideration in a possible future revision. Thanks

Closed 2021-08-17.

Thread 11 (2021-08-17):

Wrong voltage on SRAM

jasonsbeer, 2021-08-17:
Just to get to the point...the correct voltage for the CY62157EV30 SRAM chip is 3.3v. The current revision (1.2.1) supplies 5v. I am going to pull the Gerbers until I can look at this more tomorrow. At worst, this would be simple bodge on any existing 1.2.1 boards.

In the weeds...I changed the SRAM part number in the BOM early on when the original desired part was sold out (still is). I neglected to recognize the replacement part I selected is 3.3v. All three of the prototype boards I built have this same setup...CY62157EV30 getting 5v. They have all been rock solid and said chip runs cool. Unfortunately, even though this has been a stable implementation so far, running the part over voltage may reduce the lifespan of said part or eventually result in odd behavior.

I'll have more tomorrow.

jasonsbeer, 2021-08-17:
OK...after a quick sweep of options, I think it is simply best to replace the 3.3v part with a 5v part. No need to change the board.

THE BOM HAS CHANGED--

OLD PART -
Digikey part 428-3574-1-ND
Manfuacturer part CY62157EV30LL-45ZSXIT

NEW PART
Digikey part 428-2077-ND
Manufacturer part CY62157ELL-45ZSXI

The BOM files have been updated. I'll leave this open for any comments or input for a day or two.

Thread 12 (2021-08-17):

BOM Change

jasonsbeer, 2021-08-17:
I noticed I have been using a 3.3v SRAM chip in the BOM. Although it runs rock solid in all my prototype builds, I think it is best to replace the 3.3v part with a 5v part.

THE BOM HAS CHANGED--

OLD PART -
Digikey part 428-3574-1-ND
Manfuacturer part CY62157EV30LL-45ZSXIT

NEW PART
Digikey part 428-2077-ND
Manufacturer part CY62157ELL-45ZSXI

The BOM files have been updated. I'll leave this open for any comments or input for a day or two.

Closed 2021-09-08.

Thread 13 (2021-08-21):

8375 Agnus Support

jasonsbeer, 2021-08-21:
Paging the Amiga RAM team! @texneus @LIV2

I desire to make an alternate revision of the Amiga 2000 EATX that directly supports the 8375 2MB Agnus. I have attached a proposed schematic of the RAM circuit. Not everything is connected, but all the parts relevant to this discussion should be. Can I impose upon you guys to review the schematic and let me know what you think?

Thanks!

[CY62167E_16_Mbit_1_ M_ 16_Static_RAM.pdf](https://github.com/jasonsbeer/Amiga-2000-ATX/files/7024724/CY62167E_16_Mbit_1_.M_.16_Static_RAM.pdf)

[file6121153C-Sheet6121153C.pdf](https://github.com/jasonsbeer/Amiga-2000-ATX/files/7024725/file6121153C-Sheet6121153C.pdf)

LIV2, 2021-08-21:
No worries @jasonsbeer I've had a look and it looks good to me!

jasonsbeer, 2021-08-21:
> No worries @jasonsbeer I've had a look and it looks good to me!

Thanks, Matt!

darrenfreeman, 2021-08-21:
Will it be backwards compatible with a 1 MB Agnus, even with the 2 MB SRAM? I.e. will the uppermost address line to the SRAM be a constant during access?

If so, you could build a 2 MB board, and then go searching for the 2 MB Agnus sometime later. This is especially relevant if someone makes up a batch of boards without the custom chips.

If not, would it be hard to add a jumper for forcing it to only see 1 MB of the SRAM?

jasonsbeer, 2021-08-21:
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

I have been thinking a lot about this concept. Unfortunately, the 8375 is not pin compatible with the 8372A. By quick count, there are 21 signals on a different pin. Using a single board to support both versions would require a considerably large field of jumpers and a mess of traces to make it work. This would take a lot of rework to implement, but I certainly agree a single board approach is preferable. I will see what I can do.

jasonsbeer, 2021-08-21:
In order to explore a single board to support both 8372A and 8375...I worked up the schematics. I ended up with 34 jumpers that would need to be configured to support either configuration. 21 to configure Agnus, and 12 to configure the SRAM. I call it the Insane Jumper Edition. I'll upload it to the dev branch if anyone gets a desire to check it out. I do not intend to follow that path any further at this time.

darrenfreeman, 2021-08-22:
What about two sockets? Could you make enough room to place them side by side, and you only populate one?

LIV2, 2021-08-22:
It might be possible to fit two sockets, perhaps if the footprints were overlapping but offset diagonally by 1.27MM (kinda like I did on my A500 8375 adapter).
I wouldn't recommend this though, adding dual sockets will result in stubs for every signal going to Agnus which can result in instability and radiated noise.

darrenfreeman, 2021-08-23:
Stubs won't be an issue at this clock frequency, they will just add a tiny lumped capacitance. (The capacitance of the traces on the four-layer ATX version will be completely different to the original.) The Agnus is 30 years old, and the original B2000 board was two layers and used 1 kOhm terminations.

The two-socket PCB would be an alternative to the Mini Megi style of adaptor, and those ran an address line over a twisted pair.

Here's one for comparison, on a real rev 6.2 board: https://www.ebay.com.au/itm/203532038100

jasonsbeer, 2021-08-24:
I am working with @texneus on this. We have a couple options we are evaluating. Stay tuned.

texneus, 2021-08-24:
I'm going to reopen this as I think there are ways to eliminate jumpers that are worthy of further discussion, and personally I would like to see this as one board layout for a variety of reasons including those already discussed.  Focusing on 2Mb SRAM only and spring boarding of some schematics created earlier by @jasonsbeer, the following gets us down to "only" 14 jumpers and (assuming my eyes didn't get crossed somewhere) this should work with either Agnus.

This particular design takes advantage of the fact that most of the Agnus RAM address lines (DRA0-9) are still address signals even though they are not in the same place between Agnus chips.  In the end, the SRAM won't care as long as it's addressed consistently.  In 1Mb mode A0 is logical 0 at all times, effectively allowing only half of the 2Mb SRAM to be addressed.  The other addresses lines would skewed as shown on the second sheet.  For 2Mb all address lines line up.  Feel free to review and point out the error of my ways.

Also, at least one jumper (at the bottom of the first sheet) is redundant and can be removed.  The silk screen could be changed to "Short for NTSC or 8375 Agnus".

Please excuse the crudity of this drawings, I did not have time to paint it or build it to scale...I will learn KiCAD at some point, but until then I will do layouts like its 1989 :-)

I have not looked at other jumpers yet but there are probably opportunities to reduce these further as well.

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

darrenfreeman, 2021-08-24:
On my A500, I remember doing a mod for 1 MB chip instead of 512k chip and 512k pseudo-fast. IIRC that was a jumper implemented as three pads and a track between two of them, I had to cut the track and bridge the other two. (Forgive me if that's not quite right, it was in the early '90s!)

Such an approach, defaulting to the 1 MB Agnus, would make almost everyone happy. And it would be period-correct! :)

darrenfreeman, 2021-08-24:
I also wonder, in relation to that 512k chip and 512k pseudo-fast. Was this done to allow boards with the older Agnus to address 512k of chip, while allowing the CPU to address the rest? Can this approach work with 2 MB of SRAM, and a 1 MB Agnus?

Or was it only ever possible to do that with a 1 MB Agnus, and they downgraded it for other reasons?

LIV2, 2021-08-24:
@texneus that's clever! Very nice

> I also wonder, in relation to that 512k chip and 512k pseudo-fast. Was this done to allow boards with the older Agnus to address 512k of chip, while allowing the CPU to address the rest?

Yes the older Agnus' internal registers could only make use of 512K Chip but the memory controller portion could address up to 1MB which allows the CPU access the slow ram

Presumably even when they came out with the 1MB Agnus they left it defaulting to 512K chip / 512K slow to ensure compatibility with existing software that might have assumed that configuration

> Can this approach work with 2 MB of SRAM, and a 1 MB Agnus?

Unfortunately not. 1MB Agnus only has enough address inputs for 1MB so the memory controller can't address more than that.
With a bunch of external logic

darrenfreeman, 2021-08-24:
Oh well. So, how about a jumpered configuration as per @texneus, but done using 0603 0R resistors? And including a default configuration of 1 MB, implemented using thin tracks that will be easy to cut.

If, at some point in the future, you're fortunate enough to get a 2 MB Agnus, you just install the 0R resistors (or solder blobs) across the pads that are not shorted, and then cut those tracks. It should be easy enough to get the resistors on the right pads, by making sure you can still see the tracks that you need to cut.

jasonsbeer, 2021-08-24:
Just to add some info to the schematics texneus uploaded. I drew up a symbol that would cover both Agnus versions in question (8375 and 8372A). On the symbol, you will see some pins identified with slashes in the name. These are (probably obviously) the pins that differ between the two versions of Agnus. The format is [8375 Signal]/[8372A Signal].

You guys can double check I drew it up correctly, as well.

darrenfreeman, 2021-09-04:
This was news to me - there are (at least) two different pin-outs for the 8375, depending on the CBM part number. It will not be sufficient to call the chip "8375". That designation should be dropped, going forwards, as baffling and inconvenient as this is.

https://www.amigawiki.org/lib/exe/fetch.php?media=de:parts:agnus-history.pdf

From my reading, the A3000 used a 2 MB Agnus, with a similar pinout to the 1 MB Agnus of the A500/A2000. The A500 Rev 8a, A500+, and A600, use the modified pinout that requires all these jumpers.

I think we can support all the 1 and 2 MB parts, it will just require a table of jumper settings for each CBM part number. Perhaps it can go on the bottom silk screen, with all the jumpers.

LIV2, 2021-09-04:
The 2MB A3000 Agnus is practically unobtainable though

darrenfreeman, 2021-09-04:
According to this thread, the A500 Rev 8a had the A3000 version, while the A500+ (same motherboard, different components) had the A600 version.

http://eab.abime.net/showthread.php?t=52072

So it will be interesting to look at the schematic for the Rev 8a, maybe we will find a lot of jumpers...

darrenfreeman, 2021-09-04:
I had a look, couldn't see anything related to that. Maybe the above thread is mistaken. Maybe the board didn't work, because someone put the wrong part on it.

jasonsbeer, 2021-09-10:
Here is a list of 8375 part numbers that I think we can support without going totally over the top. I would have to tweek existing jumpers, but not add any. Part 390551-01 is what I have been using on the schematics up to now.

|Part Number|PAL/NTSC|Comment|
|-|-|-|
|390551-01|PAL|8375R0 Original Release|
|390551-02|NTSC|8375R0 Original Release|
|318069-12|PAL|Differs from 390551-01, pin 41 is Vbb instead of GND|
|318069-13|NTSC|Differs from 390551-02, pin 41 is Vbb instead of GND|
|318069-10|PAL|Differs from 390551-01, pin 40 is Vbb instead of 14MHz|
|318069-11|NTSC|Differs from 390551-02, pin 40 is Vbb instead of 14MHz|
|390544-01|PAL|Pin compatible with 318069-10|
|390544-02|NTSC|Pin compatible with 318069-11|

This information is taken from https://www.amigawiki.org/lib/exe/fetch.php?media=de:parts:agnusliste_v09_120923.pdf, which has provenance. Anyone reading this is welcome to review this list. Let me know if you see any discrepancies.

jasonsbeer, 2021-09-20:
Good discussion here, everyone. I think this thread has gone as far as it could. The new board revision is routed and uses solder pad jumpers to configure the board for the Agni shown in my previous post.

Closed 2021-09-20.

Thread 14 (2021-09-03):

Enhancements to the internal floppy connector

darrenfreeman, 2021-09-03:
I have been comparing the A500 and B2000 internal floppy connector circuits. The A500 only supports one internal drive, because it turns the motor on only when DF0 is meant to spin. (Incidentally, can we agree that _MTROD is a typo? It's called _MTRON on the A500.)

The B2000 drives the _INUSEx lines as you would expect the motors, accounting for the twist in the cable before DF0. Then it logically ORs those into _MTRON, so both motors spin if either drive is in use, it's just the LEDs that differ. (Ouch, my antique floppies, they will wear out faster!) Despite the cable twist, the drives still need jumpers set for which _SELx line they respond to.

Since we are aiming at a 100% new parts build, I figure I'll use PC drives. Either modded to work like Amiga drives, or using an adapter right at the drive. I'd do a bit more twisting on the cable, so both drives only have to listen to one of the _SELx lines, and they become interchangeable.

Then you can modify the drive to spin the motor when it is _INUSE, which restores the behaviour of external drives, i.e. all drive motors are independent. The common _MTRON signal can be dropped.

And since ATX cases usually have two bays, I'll install two drives. But then I'd also like a Gotek, hmm... and there's no external drive port any more...

One approach is to just bring out _SEL2 and _SEL3, as well as _MTRx and _DKRST, so the internal floppy port has the needed signals to supply drives using external floppy controllers. But, it's the same number of pins if we supply _SEL2, _SEL3, _INUSE2, _INUSE3, and that would make the case layout so much neater. All drives are treated the same.

So, I suggest that instead of one jumper, for DF1, there would be three. And a couple more logic chips to derive the extra four signals.

You can free up pins 14 and 16 straight away. Make them _SEL2 and _SEL3, respectively. It's a neat solution, the cable shifts the wires by two places after each drive. (Pull out the sharp metal part of the IDC connector, for any new signals that you don't want to send to a given drive.)

And pin 3 is usually cut off, but it could be used. Perhaps as an _INUSEx, because those signals don't really need twisting with ground anyway. E.g. wire the motherboard as:

* 4 - _INUSE0
* 5 - _INUSE1
* 6 - _INUSE2
* 7 - _INUSE3

Similar to above, the wires move one across after each drive.

As I've specified the above pins, the drive closest to the motherboard would be DF0. This means you can make a cable for only one drive, without any twists in it. If you want DF0 at the far end of the cable, you twist the _SELx and the _INUSEx groups, between the motherboard and the first drive. The drive ordering is now reversed, with DF3 being closest to the motherboard.

I think that's pretty close to optimal, really. Simple cable wiring, take some photos and anyone can copy it. It does mean changing the drive behaviour, so the motor spins on _INUSE. (You can do this in the cable, if you really want. But if you're modding PC drives anyway, what's another wire.)

darrenfreeman, 2021-09-08:
I see your point about EATX cases not supporting floppy bays, but there are plenty of brand new ATX cases that do. I don't have an opportunity to look at cases in person, due to the pandemic, so I can only be optimistic about finding one that can be made to fit the EATX board. I still have a roomy ATX case with 4x 5.25" and 2x floppy bays, and I can get more.

I'm not personally interested in modernising everything about the system, if that means losing functionality. I think there will be builders who feel the same way. I'm interested in trying out things I never got to try 30 years ago, things you can't do in UAE.

I think I could fill up all four floppy drives. For example, 2x 3.5" floppies (so you can X-copy), one GoTek drive, and one 5.25" drive for reading even older discs (e.g. C-64).

Here's another suggestion: provide the external floppy connector as a 26-way header on the motherboard, using the pinout that would allow a ribbon cable to be soldered to a DB23 female connector. These are now available for a reasonable price (under $10), so some builders will want to install one on the back panel.

Then it would be pretty easy to plug a small adapter board into that 26-way header, which provides the logic to drive a secondary 34-way internal floppy connector. Those who want more internal drives, could get them with a second standard A2000 floppy cable.

neilo40, 2021-09-08:
> Intriguing idea. Do you feel there is a good use case for more than 2 floppy drives? I'm not sure it fits into the forward looking/modernization intent of this project. Projects like WHDLoad have greatly decreased their usefulness. External drive bays are disappearing from all computer cases.
>
> Alternatively, I would like to consider a future project or enhancement that brings removable USB drive compatibility to the platform.

I really like this idea.  I'm imagining a gotek-like capability on the mainboard with the USB port interface via standard header so that a case USB port could be used.  control and feedback would need to be thought through, but +1 for this direction

darrenfreeman, 2021-09-08:
If you want a USB floppy emulator, you can just use the floppy interface as it stands. Emulators are an off-the-shelf item. Note, I was originally asking if we can have four drives internal, because I want two floppies _and_ an emulator. But I also like the idea of mounting a DB23 on the back of the case, since those are available. Then I can plug in whatever devices I feel like, at the time. And as I suggested, that header can be used as a second copy of the internal header, if that's what you want. (Just need a daughter board with a couple of chips on it.)

I would certainly like to have native USB support though. But there are Zorro cards that offer this, and what's the point of a Zorro backplane if you stuff everything into the motherboard anyway ;)

For games, you need to run the mouse through the custom chips. There are USB to mouse/joystick adapters already, as off the shelf items. But what would be pretty nice, is if we could fit them internally and use the USB sockets on the front of the case. Perhaps add two internal mouse/joystick headers, which combine the signals with the external ports?

I'm not sure what happens when you unplug the USB mouse from the various adapters, the ideal behaviour is they let all signals float high. So you just wire it in parallel with the external mouse port, and use whichever one you want at the time.

It would suck if they hold two of the quadrature signals low, as then you need a way to isolate them in order to use an Amiga mouse/joystick. It would require a bus mux and a toggle switch, to decide whether to use the external port, or the internal pin header. Quite doable still, but if anyone can confirm there is a USB adapter that goes completely passive when you unplug the USB device, then it's a really easy thing to add them in parallel with the external Amiga ports. Adds a few cents to the board, for a whole lot of options.

jasonsbeer, 2021-09-26:
Revision 2.0 includes an internal header that supplies the external floppy signals. The user can build a DB23 adapter cable to support external floppies or otherwise tap into those signals as they choose.

Closed 2021-09-26.

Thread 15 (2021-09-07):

EMI filters

Pragakhan09, 2021-09-07:
Hi,
first of all, @jasonsbeer thank you for this wonderful project ! I'm going to build one but I see that those EMI filters (W3F11A1018AT1F) are not available. Can someone suggest a 1206 form factor alternative ? I'm wondering if the 0805 form factor ‎101X15N101MV4E‎ would fit ?
Kind regards

jasonsbeer, 2021-09-08:
If you can't find the exact part, you can try part NFE31PT101C1E9L. Its a bit odd looking, but is the correct footprint.

I would avoid using the 0805 part. You can probably get it to work if you place just perfect, but are likely to have trouble with consistent solder joints.

Pragakhan09, 2021-09-08:
Great, thanks for your answer. I looked at that part but like you say it's a bit odd looking and has a few different specs (25v...). I'll implement those :-)

Closed 2021-09-10.

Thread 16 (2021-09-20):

Looking to borrow or buy certain 8375 Agnus parts

jasonsbeer, 2021-09-20:
I have finished routing Rev 2.0, which is intended to support both 8372A and certain 8375 Agnus chips on the same board. I'll probably send this off for fabrication soon.

My next quest is to either buy or borrow some different 8375 Agnus part numbers. Please let me know if you can help out with any of the Agnus part numbers below.

UPDATE: I have obtained a 390554-01 Agnus. Still looking for the other part numbers.

<s>390554-01</s>
<s>390554-02</s>
318069-12
318069-13
318069-10
318069-11
390544-01
390544-02

I also added a discord channel for this project...https://discord.gg/NU7SPYfNFj

jasonsbeer, 2021-09-26:
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

I added the option to use either the original Amiga RTC design with the MSM6242 or the RTC62423, as was originally included in this project. The user can decide which they prefer to install.

I added an internal header to support external floppies. The user can build a cable to DB23 and mount it to the case or tap into the signals however they choose.

For the mouse/joystick headers...the term "diminishing returns" comes to mind...in terms of time, PCB real estate, and general need. I don't believe this is needed for the large majority of users. It takes a lot of time to modify the schematics and re-work the board. If this request is to support an open source Amiga project, I will consider adding it. Otherwise, I'm at feature lock for this revision.

kinmami, 2022-04-03:
Hello @jasonsbeer
I have the following chips in stock pulled off from operating machines:

Agnus (1MB)	8375 R1			318069-16	PAL
Agnus (2MB)	8375 R2			318069-10	PAL
Agnus (2MB)	8375			318069-11	NTSC
Agnus (2MB)	8375			390544-01       PAL
Agnus (2MB)	8375 R0			390544-01	(should be PAL)
Agnus (2MB)	8375			390544-02	NTSC

I do prefer keeping the PAL versions, but we can find an agreement for the NTSC chips 318069-11 & 390544-02.
I am going to pvt you on the Discord channel.

Closed 2022-04-12.

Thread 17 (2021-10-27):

Board may not boot on all VGA monitors

xtpower, 2021-10-27:
When J9004 is on pos. 1-2, the POST process breaks.
That only happens when my Philips LCD monitor is connected.
This is caused by an unbuffered HSYNC to pin 13 on the VGA connector.
I figure that it is caused by a power drain on HSYNC, done by the monitor itself.

By using pin 8,9 and 10 on U303, which are redundant pins, this has ben fixed from my part.
It is done by lifting one leg from R203B1, running the HSYNC into Pin 9 and10 and out of pin 8 and down to the board toward pin 13 on the VGA.

There is a 23pin to 15pin adapter from commodore (390682-01) that comes with the A4000, that contains a 74HCT08 buffer.
I think mostly to avoid any monitors to be connected almost directly to any custom chips.

texneus, 2021-11-01:
A couple of observations/comments on this issue.

1) Where is U303C on the schematics?  I cannot locate it on either 1.21 or 2.0.  I suspect it should be listed as a spare as per originating issue.  Are there any other unidentified spare logic gates that need to be flushed out?

2) Looking at the HSYNC vs VSYNC, I'm not sure I see why one is affected and not the other.  HSYNC has a single TTL load difference as compared to VSYNC, which seems insignificant.  None the less I agree buffering both is appropriate.  However, NMOS ICs are not usually able to drive logical 1 very well.  There is already a 10k (R203) pull up for HSYNC, but none for VSYNC.  Perhaps coincidentally, HSYNC is asked to drive a TTL load where-as VSYNC is not.  My suggestion to make this a bit more bullet proof would be to change R203 to 4.7k and add a 10k (or 4.7k) pullup to VSYNC.

3) Instead of adding a new logic chip to serve as a buffer, have you considered revisiting some of the existing logic to ensure efficient use?  As an example, U607 stands out like a sore thumb as all ANDs are configured as a buffer.  If geographically possible, I would suggest replacing U607 with a 74x34 hex buffer.  Use four buffers in place of the current AND/Buffer gates, and the two extra buffers for HSYNC/VSYNC.  This is just an example, but other opportunities may exist.  Below are gates I found just casually looking that are masquerading as a buffer or inverter.  There might be some I missed...

Ref Des | Gate | Func
-- | -- | --
U302C | OR | BFR
U302D | OR | BFR
U303A | AND | BFR
U303B | AND | BFR
U303C | AND | SPARE?
U501C | NAND | INV
U501D | NAND | SPARE
U607A | AND | BFR
U607B | AND | BFR
U607C | AND | BFR
U607D | AND | BFR
U900A | NAND | INV
U900B | NAND | INV
U900D | NAND | INV

jasonsbeer, 2021-11-04:
> 1. Where is U303C on the schematics?  I cannot locate it on either 1.21 or 2.0.  I suspect it should be listed as a spare as per originating issue.  Are there any other unidentified spare logic gates that need to be flushed out?

Spares are intended to be listed on the power sheet of the schematics. I missed U303C. Calling out spares wasn't a priority for the first round of the project. 8^>

> 2. Looking at the HSYNC vs VSYNC, I'm not sure I see why one is affected and not the other.  HSYNC has a single TTL load difference as compared to VSYNC, which seems insignificant.  None the less I agree buffering both is appropriate.  However, NMOS ICs are not usually able to drive logical 1 very well.  There is already a 10k (R203) pull up for HSYNC, but none for VSYNC.  Perhaps coincidentally, HSYNC is asked to drive a TTL load where-as VSYNC is not.  My suggestion to make this a bit more bullet proof would be to change R203 to 4.7k and add a 10k (or 4.7k) pullup to VSYNC to assist with TTL loads when H/V SYNC are logic 1.

Curious as to why the value change and difference in recommendation (4.7k vs 10k). As a side note, _VSYNC supplies the TICK signal to U300. This is related to CIA timing.

> 3. Instead of adding a new logic chip to serve as a buffer, have you considered revisiting some of the existing logic to ensure efficient use?  As an example, U607 stands out like a sore thumb as all ANDs are configured as a buffer.  If geographically possible, I would suggest replacing U607 with a 74x34 hex buffer.  Use four buffers in place of the current AND/Buffer gates, and the two extra buffers for HSYNC/VSYNC.  This is just an example, but other opportunities may exist.  Below are gates I found just casually looking that are masquerading as a buffer or inverter.  There might be some I missed...

I don't see anything like a 74x34. Maybe you meant a 74x367? That is a non-inverting hex buffer. Probably doable. The obvious candidate is U607. Its nearby and, as you point out, every gate is used as a buffer. I will take a look.

Most of the logic gates mentioned are geographically distant. Combining them would require a lot of work to re-route the board. Probably not worth it if the goal is to reduce part count by 1 or 2 cheap logic chips.

Add to the your list...
U303D is shown on the processor sheet and contributes to bus arbitration. Not a buffer.

texneus, 2021-11-07:
> I don't see anything like a 74x34. Maybe you meant a 74x367?

I was being generic.  7436 is a hex buffer.  Any buffer would work that is currently available.  The AHCT244 already used would also be fine.  These are octal rather than hex.

> Most of the logic gates mentioned are geographically distant. Combining them would require a lot of work to re-route the board. Probably not worth it if the goal is to reduce part count by 1 or 2 cheap logic chips.

If it's too much effort then I agree - it was just a suggestion for you to think about, nothing more.

> Add to the your list...U303D

Something got lost in translation, I think.  U303D isn't on my list.  As you note it's used as an AND gate.

> Curious as to why the value change and difference in recommendation (4.7k vs 10k).

This will take some explaining but in retrospect I no longer believe any change is necessary.  Disregard.

The explanation why I thought it was necessary (warning, long and rambling...):

The reason pullup resistors might be needed has to do with limitations of NMOS logic, where logic 1 outputs are inherently “weak”.  This can be seen in the Denise (and other NMOS ICs) datasheet:
```
Characteristic      Symbol  Min  Max  units  Conditions
Output high level   Voh     2.4  -    volts  Ioh = -200ua
Output low level    Vol     -    0.4  volts  Iol = 3.2ma
```
Source: Datasheets/252126-01_Denise_specification.pdf para 3.3 in this repo

Note a logic 0 can sink up to 3.2mA, but a logic high can only source 200uA.  If the application requires 200uA from the output, the voltage can drop to as low as 2.4V.  The reason for this is because there is no easy way to push out current using only NMOS transistors.  For the nerdy explanation, the NMOS NAND gate on Wikipedia provides a great illustration.

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
Source: https://en.wikipedia.org/wiki/Depletion-load_NMOS_logic

When both A and B are high, FETs T2 and T3 both turn on.  This more or less directly connects the output Y to ground.  This turns off T1 and produces a logic 0 at the Y output.  Since Y is connected to ground through T2 and T3, it can handle a relatively high amount of current coming into the input.

Now consider if a logic 0 is applied to A or B (or both).  T2 and/or T3 turn off, which causes Y to float.  The voltage at Y increases only because some current leaks through T1.  As the voltage increases, eventually it reaches a point where T1 barely turns on, producing a logic 1 at output Y.  In real life this means the transition of NMOS outputs from low to high tends to be “lazy”.  It also means that even a small load at Y will drop the output voltage, causing T1 to start to turn off, reducing the voltage at Y further.

This is not normally an issue when driving other NMOS logic, as the inputs are FETs which require very little power to drive.  The input to bipolar logic (i.e. 74LSxxx) is however completely different and a high input can require more power than NMOS can deliver, especially when multiple inputs are driven at once.  One solution to this problem is to use pullup resistors which “help” the NMOS output stage achieve a stable logic 1 output.

In this case, however, we are not driving bipolar logic, but HCT (CMOS) logic, which has a FET input stage likely similar to NMOS.  Per the TI 74HCT08 datasheet, a high input only requires 1uA max (so a 2uA load per buffer, as configured).  So, on paper, pullups are not necessary.  Since the original A2000 Rev 6 schematic shows pullups on Denise outputs, but are unpopulated on A2000 boards (and don’t even exist on this project), it would seem to confirm the paper analysis.  This is likely valid so long as (A)HCT buffers are used.

jasonsbeer, 2021-11-15:
Closing this issue -

I have duplicated the behavior described in the original post.
I have validated the proposed solution.
The solution is included in Rev 2.1, which will be the next production version.

Thanks, everyone!

Closed 2021-11-15.

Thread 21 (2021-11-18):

Flickerfixers and scandoublers do not work correctly in videoport

xtpower, 2021-11-18:
I have ben having some trouble using my 2 flickerfixers / scandoublers on the board.
A little backstory.
I have 2 scandoublers / flickerfixers which both works out well on my stock A2000 rev6

I have ben comparing the picture and signals from my org. A2000 and the A2000ATX board on my bench - I will post the pictures.
I'm writing because I'm at a dead end in this.

My setup is the same on both boards: Kick 1.3 - up and running, but not booted into anything.
I'm using a Lighttech Flickerfixer.
My second Flickerfixer is a microway: https://bigbookofamigahardware.com/bboah/product.aspx?id=374
This part do not work in the port for some reason.
Both machines are PAL machines, and the Xtal is 28,37516 MHZ

And here's some pictures of a simultaneous comparison of the videoslot.
The Burst signal on both looks like this
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
:

The hsync signal looks like this:
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

When on kickscreen, I got this:
Original A2000
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

ATX amiga
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

It is noticeable that there is a white barre just below the kick picture.

Second: When trying to change screenmode to interlaced, a thing the flicker card can handle, the ATX board doe not handle this at all.
Two pictures to show this.:
Org amiga 2000:
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

ATX amiga:
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

Also a part of the picture (topmost) is out of the picture.

I do not know what causes this issue. All the signals is there, but they seems wrong in some way.
Maybe a misconfiguration of the videoengine??
Idunno.

jasonsbeer, 2021-11-19:
Tagging this thread as help wanted, for now.

I looked up the two cards you mention, and I found schematics for the Light Tech card. I suggest we concentrate on that one since the schematics and VDHL code is available. Please confirm this is the one you are working with: [https://www.lighttech-hg.de/index.php/open-source-projects/a2000-scandoubler](url)

The first thing that comes to mind is a bad clock somewhere. As a reference, I have been using the Pi -> HDMI video card in both PAL and NTSC machines without trouble, but I have no "flicker fixer" cards to test.

Let's start easy and work our way to hard...

It appears the Light Tech card uses the XCLK/_XCLKEN signals. Cards in the video slot use these signals to replace the system clock supplied by X1. If one or both of those signals are not functioning as intended, all the clocks will be running from X1. In that event, this would not correct for the hardware in the video slot.

I recommend you...

1) Check that _XCLKEN is LOW when your card is in. It should be HIGH when the slot is empty.
2) Probe the XCLK signal. What is the frequency?
3) Probe the 7M signal at pin 15 of the 68000. What is the frequency?
4) Probe the other clocks used by the Light Tech card..._VC3, _VC1, _VC4, _CDAC. What are the frequencies?

Let's go from there.

darrenfreeman, 2021-11-19:
@xtpower unplug anything that might be plugged into the SVGA connector, see if that helps.

xtpower, 2021-11-19:
Hi again.
I can confirm that the card I mentioned is indeed the card you are linking to.
I will have a look tonight reading the frequencies.

And yes, There's nothing plugged into the SVGA connector, so it's not that.

xtpower, 2021-11-24:
Just to come around your original question,
The frequencies is as expected.
7,09 and 3.54 on the testingpoints.

The _XCLKEN  is the same on both machines and the same with XCLK

I have ben able to replicate the FlickerFixer issue,  (Picture of the Logica Diagnostic not using the whole screen) on My Amiga 2000.
Moving J300 Where you are choosing between _VSYNC and TICK.
On Amiga 2000 Rev 6. with position 1-2, this thing / issue where the screen is not filling out the full potential, vertically, occurs.

I guess that Pin 14 on CN207 still needs the original 50HZ no matter what the rest of the machine is up to.

I do have that raspberry pie HDMI card for the Video port, and it works despite all I have said.
I know that there is an ATX to A2000 power plug, containing a PIC that is producing a 50HZ ([LINK](https://www.ebay.com/itm/403251225065)).
I was wondering if a similar thing could be integrated on the board.

jasonsbeer, 2021-11-25:
>Moving J300 Where you are choosing between _VSYNC and TICK. On Amiga 2000 Rev 6. with position 2-3, this thing / issue where the screen is not filling out the full potential, vertically, occurs.

 >I guess that Pin 14 on CN207 still needs the original 50HZ no matter what the rest of the machine is up to.

At last it seems we have a definitive answer to why TICK was driven by an alternate source in the big box Amiga. HSYNC needs to be solid 50 or 60 Hz, and any hardware that overrides the system clock with also cause HSYNC to deviate from expected. VSYNC would also be affected. None of the wedge Amigas had a power supply TICK and would have suffered from this same issue. Fascinating.

> I know that there is an ATX to A2000 power plug, that is producing a 50HZ ([LINK](https://www.pcbway.com/project/shareproject/Tick_signal_generator_for_Commodore_Amiga_2000__3000__4000_Power_Supply_Unit.html)). I was wondering if a similar thing could be integrated on the board.

I'm not sure that specific example could be incorporated, as it needs connection to mains, and that is not supplied through the ATX power connector. There are other examples where programmable oscillators or PICs are used to supply the correct signal. I'll dig into this and see what can be done. In the meantime, I'll add this as a known issue so people are aware.

Thanks for sharing your findings.

darrenfreeman, 2021-11-25:
That may not be the reason why they chose the mains frequency for the ticks. For a long time, the mains was used to set the timing in mains-powered clocks, and it was very reliable. Probably a more accurate wall-clock time than the crystal oscillator on the Amiga motherboard.

The wedge Amigas don't have a tick signal on the connector, so it's not an option for them.

I feel like this specific issue is more of an accident. Although the truth is that unless you're genlocking to a signal for broadcast, it's possibly even worse for measuring wall-clock time. A VCR in playback for example... all bets are off :D

darrenfreeman, 2021-11-25:
I was hoping to bodge a connector onto the board, so that I can inject my own tick signal. Perhaps that can go into the next revision? Perhaps make it a three pin jumper as before, only pin 1 is ground. So you jumper 2-3 for internal oscillator, or you install a two-wire header onto pins 1 and 2, to supply your own tick.

jasonsbeer, 2021-11-25:
I did some brief investigation last night and found a tick circuit on aminet. I like this concept because it uses off the shelf parts that do not need mains and does not need programming. I will investigate if it is a robust solution. Any comments are appreciated.

http://aminet.net/package/docs/hard/Mix_and_Tick

In a nutshell, it's a 74HCT4060 ripple counter driven by a crystal that feeds into back to back flip flops. It will generate 50 or 60 Hz depending on the crystal frequency. My concern is how accurate and consistent the output frequency is.

jasonsbeer, 2021-11-25:
> I was hoping to bodge a connector onto the board, so that I can inject my own tick signal. Perhaps that can go into the next revision? Perhaps make it a three pin jumper as before, only pin 1 is ground. So you jumper 2-3 for internal oscillator, or you install a two-wire header onto pins 1 and 2, to supply your own tick.

>

Yup. However we end up with a new TICK, we will make it jumper selectable like the original.

darrenfreeman, 2021-11-25:
Please don't put something cheap and nasty on the board, just make it a header for something that's as good as the user wants. I plan to use the RTC with trimmer option, and I will trim it as close as I can. I could see myself eventually making an accurate 50 Hz clock, for the system to keep proper time when it's on.

xtpower, 2021-11-25:
It took me a little while to find but here it is.
[Atx to a2000 adapter with tick](https://www.amibay.com/forum/want-to-sell/hardware-for-sale/amiga/121610-amiga-2000-3000-atx-power-adapter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)
This may do the job, but be aware, it only do 50 Hz

jasonsbeer, 2021-12-02:
I pushed revision 2.2 schematics and Kicad drawings to the DEV branch. This revision adds a "tick header" that one can use to attach their own TICK generator circuit. I plan to evaluate a couple options for a simple TICK generator that will be posted as part of this project. I would feel bad if I put the header on the board and did not offer something to put on it. The header is a 1x6 2.54mm pitch male pin header.

If you do not need a TICK signal, short pins 1 and 2 to use /VSYNC, which is the current Rev 2.1 ("A500") configuration.

TICK Header
Pin|Description
-|-
1|/VSYNC
2|TBASE (TICK)
3|GND
4|/RESET
5|NC
6|+5V

jasonsbeer, 2021-12-14:
A quick update...
I have prototyped two stand alone TICK circuits. One that @texneus devised, which is driven by a 9VAC* wall wart and another that is oscillator driven by Michael Schulz (referenced above from Aminet). First impressions of both are very positive and either should make a good substitute when a discrete TICK is required. Having the two options will allow users to select which they prefer. The KiCAD files for both have been uploaded to the TICK folder in the DEV branch.

*Other voltages are supported via resistor value

Here is the 9VAC TICK output. 60Hz, since I am in North America. 50Hz will work as well.
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

Here is the output from Michael Schulz's project. Both 50 and 60 Hz.
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

xtpower, 2022-01-19:
I have had the time to test out the 50/60HZ external solution, and it is working.
Normal Lores and Hires is working well, so there is a reason for the TICK jumper configuration on the original A2000.

jasonsbeer, 2022-01-19:
>

This is great news. Thank you for helping with this. I am in the middle of building a Rev 2.2 board to test it before release. I had to wait for some parts and now things are busy. I hope to have it completed and pushed to main very soon.

xtpower, 2022-01-19:
Thanx, and great work.
I appreciate you taking things serious, and taking steps towards solutions.
This is a mighty fine project, and I have ben flashing it around :)
I guess This issue can be closed - for my part.

jasonsbeer, 2022-01-25:
Great! I finally have my 2.2 board running today. I will spend the next few days checking stability and the new TICK header. I very much appreciate your help and patience with this issue.

jasonsbeer, 2022-02-04:
Revision 2.2 with the TICK header (J300) and the two TICK generator options has been pushed to main.

Closed 2022-02-04.

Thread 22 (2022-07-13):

Crowdfunding of assembled boards

Sgw32, 2022-07-13:
Hi everyone,

I've made a calculation for production on PCBWay and seems like it is possible to make a small batch for a price of ~300 USD(all populated will be ~400 USD) per board. If anyone is interested we can make sort of crowdfunding.
I'm located in Russia though so there can be some shipping issues because of all of these things happenning...  (EMS works worldwide though, ~70 USD shipping) but we can make a direct shipping from China if needed. If anyone if interested I think we can make a collective order and split parcel to small parcels with direct delivery. Payment is also a question, however we can discuss it here. I now have 7 customers in Russia so I'm almost ready to order 10 boards. Maybe someone else wants to organize the order(for a larger batch), I can pay for boards.

jasonsbeer, sorry for bothering you with this message. I think that anyway collective procurement and crowdfunding is more efficient than separate ordering and will help more people to try the project.
I can share assembly order files(BOM, Pos) if needed - it will help many people and save time&money.
And of course thank you for your amazing work, looks impressive!!!

BR,
Fedor

jasonsbeer, 2022-07-13:
Sounds like a great plan! You may to place this on the Discord channel.

jasonsbeer, 2022-09-07:
Closing due to inactivity for some time. Let me know if it should be reopened.

Closed 2022-09-07.

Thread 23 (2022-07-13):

Note on U109, XCLKEN

jasonsbeer, 2022-07-13:
ISSUE: The XCLKEN pin is lacking a pullup resistor, which could result in the 74HC258 switching to the XCLK signal when there is not one present.

SEVERITY: There have been several reports of this happening.

SCOPE: Rev 2.x boards only.

PROPOSED FIX: In the event you do not get a 28MHz clock from pin 12 of U109, add a 10k pullup to pin 1 of U109. You can attach the pullup to any +5V source. C109 is nearest. Target future revision for fix.

History
Jul-13-2022 Original report.
Nov-27-2022 Updated severity.

jasonsbeer, 2023-03-01:
Added to Revision 3.0.

Sgw32, 2023-03-04:
Confirm this thing. Had this on a fully working board, and it started to shut down while working.

Closed 2023-05-11.

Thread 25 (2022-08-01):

CD Audio Header

jasonsbeer, 2022-08-01:
ISSUE: Add internal header for CD Audio, such as found on the Amiga 4000.

SEVERITY: Enhancement request.

SCOPE: Future revision.

PROPOSED FIX: Review A4000 schematics and include similar solution.

darrenfreeman, 2022-08-01:
Note that the addition of the A4000 CD header introduced a design flaw - C433/C443 (final AC coupling capacitors) have a reversed DC voltage under most conditions. The usual fix is to reverse these caps during recapping, however I think it is possible for software to deliberately reverse this voltage again with properly chosen DAC outputs.

This defect is not especially serious, as the voltage is only about -1.1 V. Still, it should not have been in production like this.

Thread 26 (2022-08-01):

Increase Slot Through Hole Size

jasonsbeer, 2022-08-01:
ISSUE: Through holes for the slots are somewhat small. This makes them slightly difficult to install.

SEVERITY: Enhancement request.

SCOPE: Future revision. Slot footprints only.

PROPOSED FIX: Review actual pin sizes of slots in common use and adjust footprints, as necessary.

jasonsbeer, 2023-03-01:
Added.

Closed 2023-03-01.

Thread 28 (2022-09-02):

A500 - ram-expansion port

pluspeople, 2022-09-02:
ISSUE: A A314 expansion can not be used on the B2000 EATX board.

SEVERITY: Enhancement request.

SCOPE: Future revision.

PROPOSED: Add the option for a pin-header similar to the A500 ram expansion, on the B2000 board, potentially just above the ram-chip - leave it as an option so people can choose not to populate this pin-header if they have no desire for this feature.

BACKGROUND/MOTIVATION:
The A314 expansion is a game-changer in what is possible with an Amiga, since it has direct access to the chip-ram bus it can do some truly amazing stuff - chip-ram on steriods!
However a normal A2000 has no way of using this great new expansion, which means that it is limited to only being used in the A500/600.
The B2000 could change this, since the A2000 essentially is an A500 architecture, it should not be difficult to find the pins required for the ram-slot - I imagine they are all near the agnus and/or ram-chip, and a simple un-populated pinheader on the pcb with these connections would make it possible to "insert" the A314 vertically ontop of the board and essentially take over the chip-ram handling of the computer... A314 & Zorro slots what a combo.

jasonsbeer, 2023-02-27:
The appropriate way to expand the A2000 is by way of the Zorro 2 bus. This will be a bespoke connector for a single device. In addition, real estate will be an issue.

Closed 2023-02-28.

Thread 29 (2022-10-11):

U103 and U105 - Timing concern and updated BOM.

jasonsbeer, 2022-10-11:
ISSUE: Some A2000 EATX boards present a black screen when using accelerators designed for the MC68000 socket. Examples: Spitfire, TF534, TF536.

SEVERITY: High

SCOPE: All revisions.

FIX:

1) In the event you have black screen issues with this style of accelerator, you should change U103 and U105 to the 74F245. This change fixed the system of user sparxUK, as discussed on Discord.

2) Change the schematics and silkscreen to indicate this change for all machines in the next revision.

3) Change the BOM to 74F245 logic at U103 and U105. This change will be implemented immediately.

OTHER COMMENTS: 74AHCT245 will likely work as well, but has not been specifically tested.

jasonsbeer, 2023-03-01:
Changed to 74AHCT245 in Rev 3.0.

Closed 2023-03-01.

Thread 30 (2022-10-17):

20 pin ATX power supplies and SMD oscillator

thepillock, 2022-10-17:
ISSUE: Does not start up when 20pin PSU is used and SMD oscillator has been installed

Pin 12 on the ATX connector is 3.3v, and supplies power to the SMD oscillator. When a 20-pin PSU is used, pins 11/12/23/24 are missing and although 11/23/24 are connected to their equivalents elsewhere on the connector (i.e. 11 is connected to 10, 23 connected to 22, 24 connected to all other GND) pin 12 isn't connected to any other 3.3v pins so the oscillator doesn't get power.

(Thanks to LIV2 on Discord for working out where Pin12 was going)

TEMP SOLUTION 1: Short Pin 12 to 1 to provide power to the oscillator (verified - it boots like this)
TEMP SOLUTION 2: Use TH oscillator (not verified, can't see why it wouldn't work)

jasonsbeer, 2023-03-01:
Updated ATX power connector to include all +3.3V inputs.

Closed 2023-05-11.

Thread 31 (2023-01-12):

C305 Improperly Labeled

jasonsbeer, 2023-01-12:
The silkscreen shows 1000pF. The correct value is 0.1uF.

jasonsbeer, 2023-03-01:
Fixed in Revision 3.0.

Closed 2023-03-01.

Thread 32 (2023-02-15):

Buster _D2P Pull Down

jasonsbeer, 2023-02-15:
Starting with revision 6.2, the Commodore A2000 board incorporated a pull down data bus. Due to the way it was implemented, this added a pull down to the direction signal on the Zorro 2 data bus buffers. This pull down is not necessary, but apparently has not caused any issues (?). Consider removing it.

jasonsbeer, 2023-02-27:
It would be best to replace this with a pull up resistor. In the event Buster is absent, or otherwise failing in a specific way, the data buffers between Zorro 2 and 68000 will be going in the wrong direction. This will cause a failure to start condition due to data bus contention. To aid in troubleshooting (if it should be necessary), these buffers should be held in the 68000 -> Zorro 2 state.

It would be beneficial to add a pull up to _DBOE for the similar reasons.

jasonsbeer, 2023-03-01:
Added a pull up to _DBOE in Revision 3.0. That should cover it.

Closed 2023-03-01.

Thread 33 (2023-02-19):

Q: Will there be any chance of getting hold an mostly ready board for us with disatreous soldering skills?

janderssonse, 2023-02-19:
This project looks amazing, I bet there are quite a few out there, including me, that don't have the skills,. nor the time free to learn the skills needed to succesfully order a board and make it a reality, i.e ready to put in a case. I fully understand that you the creator might  rather want to perfect the design than to build and ship pre-populated boards, but have any of the regular amiga dealers( the few that ar active) showed any interest in this.Or is there any other way to obtain a mostly complete board, or plans for a more user ready viersion?

jasonsbeer, 2023-02-20:
I recommend you visit the Discord channel and open a discussion there. There have been previous runs of "mostly assembled" boards that were started by members of the community. Might be some interest and doing another.

https://discord.gg/NU7SPYfNFj

I have not been approached by anyone about doing runs for commercial sales.

janderssonse, 2023-02-20:
Thanks for the quick response, will join! Cheers!

Closed 2023-02-20.

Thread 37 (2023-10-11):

Amiga 2000-EATX rev 1.2.1 reset troubles

Trakman500, 2023-10-11:
Hi! Finally I finished assembling the a2000 and it started up almost immediately! :) But as it turned out, the reset practically doesn’t work... every third or tenth time, or even the twentieth time, it works... I can’t understand the reason? When inspecting the reset generation circuit, the following was noticed - if you put your finger on the side 8-9-10-11 of the U805 leg and press the reset button, then the reset works well; removing the finger also starts to work poorly... I measured the esr of capacitors C813 C814, everything is fine normal... where to look?

jasonsbeer, 2023-12-14:
Does the keyboard reset work? If not, there may be issues with U805 or associated passives. The reset switch works by pulling pin 1 of XU1 to ground. This also pulls pin 10 of U805 to ground. XU1 will then hold pin 1 low for 150ns after the reset button is released.

Placing your finger on an IC can create just enough pressure to "fix" a floating leg. If you have a floating leg, it can be hard to check continuity because placing a probe on the leg can bend it just enough to work. I would start by reflowing U805, XU1, and associated passives.

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

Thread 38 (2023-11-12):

wrong termination on Zorro II bus pin 96

LordZodiac76, 2023-11-12:
Hello Jason,

The termination from C675 on pin 96 must be on pin 95. The orginal schematic from A2000_R6 has no termination on pin 96 but C678 on pin 95.

cheers Marco

jasonsbeer, 2023-12-13:
Confirmed. Pin 96 (_EINT1) is unnecessarily terminated. Pin 95 (_GBG) is not terminated, but is in the Rev 6.x Amiga B2000 design.

**Issues/Observations**:
1) I am not aware of reports of Zorro 2 bus issues, so it seems devices are working as expected.
2) Termination of _EINT1 is not of concern.
3) The _GBG signal is a way for Buster to signal all devices on the Zorro 2 bus that one of the Zorro 2 devices owns the bus. Lacking termination on _GBG could result in signal reflections during assertion. My personal speculation is this signal is not commonly used.

**Recommendation**: Include fix in next PCB revision. A bodge to fix this may be applied to Rev 3.0 and earlier boards, but is not recommended unless problems are encountered when DMA Zorro 2 devices are present.

jasonsbeer, 2024-06-02:
Fixed in Revision 3.1

Closed 2024-06-02.

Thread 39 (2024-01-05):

Polarity of C408 (-12V Rail)

Matz70, 2024-01-05:
Hi
I'm in the middle of the build and I've just gotten to the point where I've put voltage on the mainboard for the first time to take some measurements regarding the power rails. That's were i have noticed that the voltage on C408 (-12V) is reversed. C408 is not populated yet, so it isn't a problem. But i'am a bit hasitant to put it in like marked on the silkscreen. C412 (-5v) is marked the other (correct) way. Am i wrong ?

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

jasonsbeer, 2024-01-06:
Confirmed. The polarity of C408 is incorrect. You should install it reversed from the silkscreen.

**Boards affected**: Rev 3.0 and earlier.
**Recommendation**: Remove C408 and install with the polarity reversed from the silkscreen.

jasonsbeer, 2024-06-02:
Fixed in Revision 3.1

Closed 2024-06-02.

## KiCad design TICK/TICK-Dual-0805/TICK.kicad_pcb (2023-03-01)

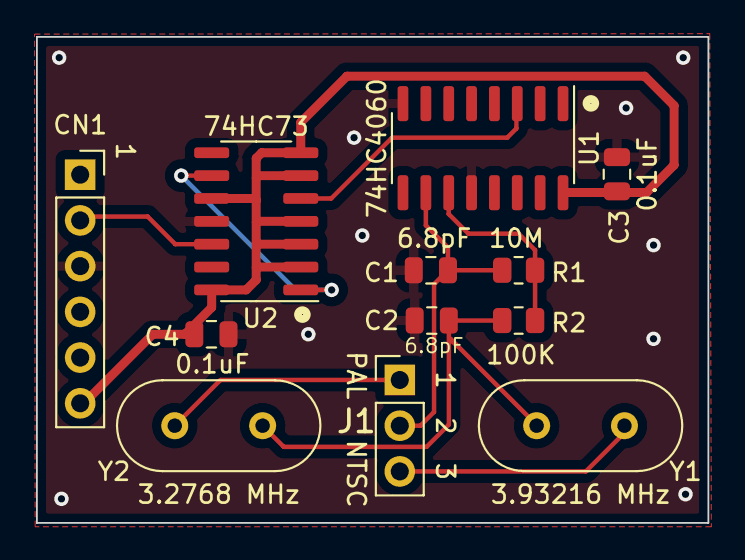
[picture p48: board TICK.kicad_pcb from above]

Board: 2 copper layers, 37.3 x 27.0 mm, 12 parts (0 on the bottom side), 10 nets.

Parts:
C1, C2: 6.8pF; C_0805_2012Metric
C3, C4: 0.1uF; C_0805_2012Metric
CN1: To_Amiga; PinSocket_1x06_P2.54mm_Vertical
J1: Conn_01x03_Male; PinHeader_1x03_P2.54mm_Vertical
R1: 10M; R_0805_2012Metric
R2: 100K; R_0805_2012Metric
U1: 74HC4060; SOIC-16_3.9x9.9mm_P1.27mm
U2: 74HC73; SOIC-14_3.9x8.7mm_P1.27mm
Y1: 3.93216 MHz; Crystal_HC49-U_Vertical
Y2: 3.2768 MHz; Crystal_HC49-U_Vertical

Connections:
+5V: C3.1, C4.2, CN1.6, U1.16 (V+), U2.2 (~R), U2.3 (K), U2.4 (VCC), U2.6 (~R), U2.7 (J), U2.10 (K), U2.14 (J)
/TBASE: CN1.2, U2.12 (Q)
GND: C1.2, C2.2, C3.2, C4.1, CN1.3, U1.8 (GND), U1.12 (MR), U2.11 (GND)
unnamed: C1.1, J1.2, R1.1, U1.10 (RTC)
unnamed: C2.1, R2.2, Y1.2, Y2.1
unnamed: J1.1, Y2.2
unnamed: J1.3, Y1.1
unnamed: R1.2, R2.1, U1.11 (RS)
unnamed: U1.3 (Q13), U2.5 (C)
unnamed: U2.1 (C), U2.9 (Q)

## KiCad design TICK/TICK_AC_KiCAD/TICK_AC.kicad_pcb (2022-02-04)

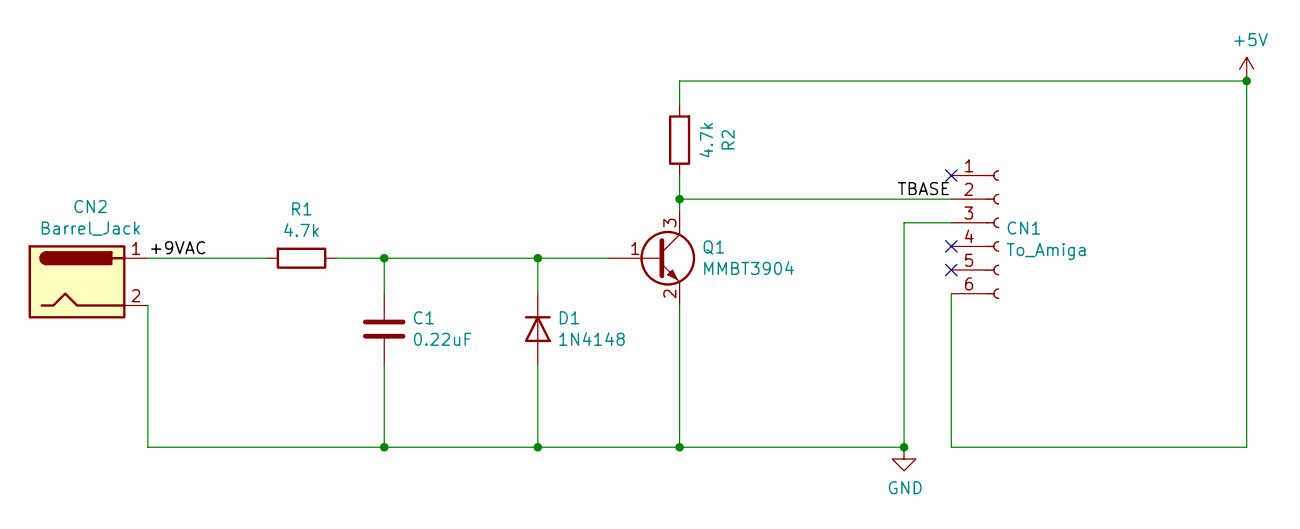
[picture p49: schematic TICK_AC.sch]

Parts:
C1: 0.22uF; C_1206_3216Metric
CN1: To_Amiga; PinSocket_1x06_P2.54mm_Vertical
CN2: Barrel_Jack; BarrelJack_Horizontal
D1: 1N4148; D_SOD-323
Q1: MMBT3904; SOT-23
R1, R2: 4.7k; R_1206_3216Metric

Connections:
+5V: CN1.6, R2.2
/+9VAC: CN2.1, R1.2
/TBASE: CN1.2, Q1.3 (C), R2.1
GND: C1.2, CN1.3, CN2.2, D1.2 (A), Q1.2 (E)
unnamed: C1.1, D1.1 (K), Q1.1 (B), R1.1

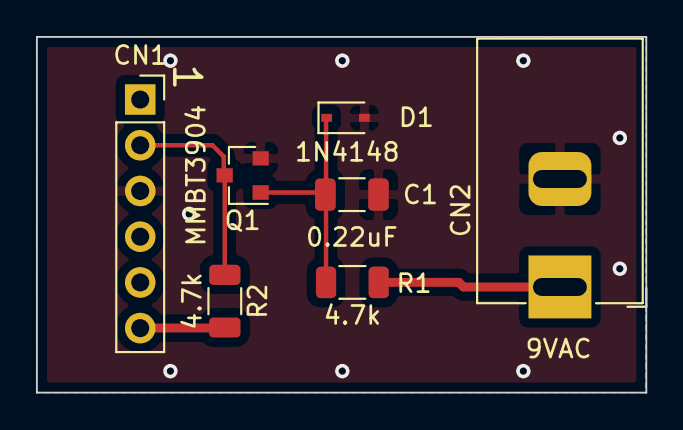
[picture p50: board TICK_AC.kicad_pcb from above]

Board: 2 copper layers, 33.9 x 19.8 mm, 7 parts (0 on the bottom side), 5 nets.

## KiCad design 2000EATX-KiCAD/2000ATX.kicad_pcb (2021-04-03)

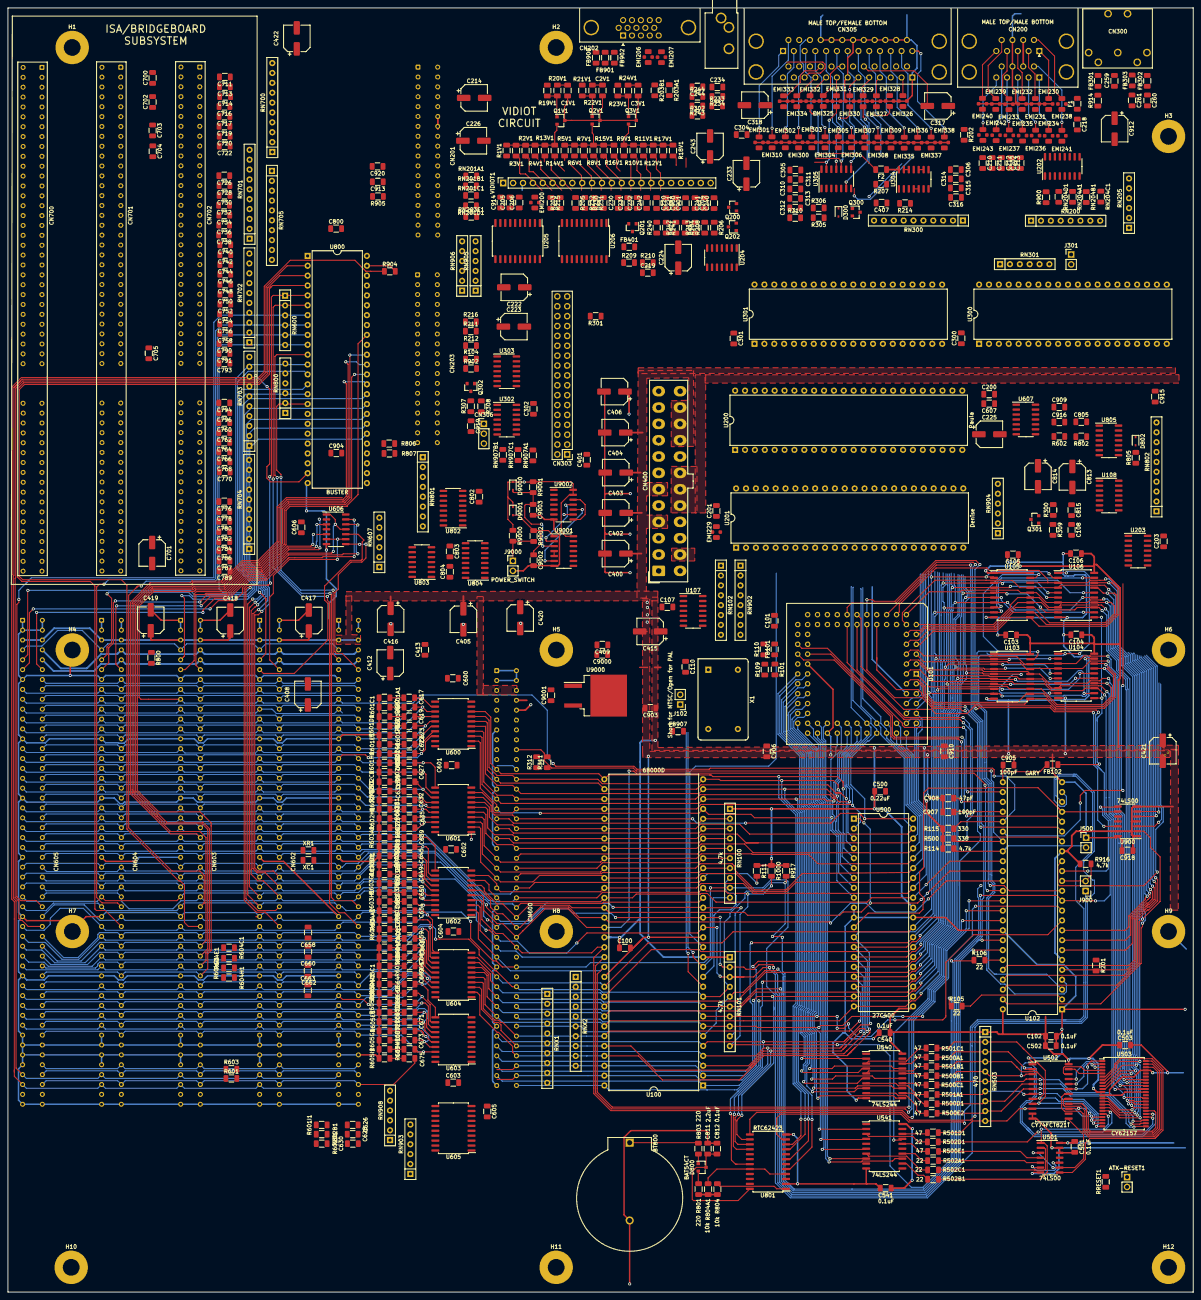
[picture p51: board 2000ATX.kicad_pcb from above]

Board: 2 copper layers, 304.8 x 330.2 mm, 579 parts (0 on the bottom side), 722 nets.

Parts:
ATX-RESET1: ATX RESET; PinHeader_1x02_P2.54mm_Vertical
BT800: Battery_Cell; BatteryHolder_ComfortableElectronic_CH273-2450_1x2450
C1V1, C2V1, C3V1: 100nF; C_1206_3216Metric
C100, C101, C102, C103, C104, C105, C106, C107, C108, C110, C200, C202, C203, C204, C205, C206, C218, C230, C234, C240, C244, C300, C301, C302, C305, C501, C502, C503, C540, C541, C600, C601, C602, C603, C604, C605, C606, C607, C800, C802, C803, C804, C805, C812, C815, C900, C901, C909, C915, C916, C918, C919: 0.1uF; C_1206_3216Metric
C201, C219, C220, C221, C500, C700, C702, C703, C704, C705: 0.22uF; C_1206_3216Metric
C210, C211, C212, C213: 0.047uF; C_1206_3216Metric
C214, C225, C226, C912: 470uF; CP_Elec_6.3x5.8
C222, C223, C402, C403, C404, C405, C406, C408, C412, C420, C421, C422: 47uF; CP_Elec_6.3x5.8
C224, C415: 4.7uF; CP_Elec_6.3x5.8
C231, C241: 6800pF; C_1206_3216Metric
C232, C242: 3900pF; C_1206_3216Metric
C233, C243, C317, C318, C701, C813, C814: 22uF; CP_Elec_6.3x5.8
C259, C260, C261, C304, C306, C904, C905, C907, C914, C920: 100pF; C_1206_3216Metric
C310, C311, C312, C313, C314, C315, C316, C617, C619, C620, C621, C622, C623, C624, C625, C626, C627, C628, C629, C630, C631, C632, C633, C635, C637, C639, C641, C645, C647, C649, C650, C651, C652, C654, C655, C657, C658, C659, C660, C661, C662, C663, C664, C665, C666, C667, C668, C669, C670, C671, C672, C673, C674, C675, C711, C713, C714, C716, C717, C719, C720, C722, C726, C728, C730, C732, C734, C736, C738, C740, C742, C744, C746, C748, C750, C752, C754, C756, C758, C760, C762, C764, C766, C768, C770, C776, C778, C780, C782, C784, C786, C787, C789, C790, C791, C793, C794, C796: 1000pF; C_1206_3216Metric
C400, C416, C417, C418, C419: 220uF; CP_Elec_6.3x5.8
C401, C407, C409, C413, C903, C906, C910: 0.1uf; C_1206_3216Metric
C811: 2.2uF; C_1206_3216Metric
C908, C913: 47pF; C_1206_3216Metric
C9000, C9002: 1uF; C_1206_3216Metric
C9001: 0.33uF; C_1206_3216Metric
C9003: 10uF; C_1206_3216Metric
CN200: DB9_Male_Stack; DSUB-9_Male_Stack
CN201, CN203: Amiga-2000-Video-Slot; 2x18_P2.54mm_Horizontal
CN202: DB15_Female_HighDensity; DSUB-15-HD_Female_Horizontal_P2.29x1.98mm_EdgePinOffset3.03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
CN205: AudioJack; Jack_3.5mm_CUI_SJ1-3533NG_Horizontal_CircularHoles
CN300: KEYBOARD; DIN5
CN303: FLOPPY; PinHeader_2x17_P2.54mm_Vertical
CN305: DB25_Stack_FemaleAndMale; DSUB-25_Stack_Female_Bottom_Male_Top
CN306: POWER LED; PinHeader_1x03_P2.54mm_Vertical
CN400: ATX-24; Molex_Mini-Fit_Jr_5566-24A_2x12_P4.20mm_Vertical
CN600: Amiga-2000-CPU-Slot; Samtec_HLE-150-02-xx-DV-TE_2x43_P2.54mm_Horizontal
CN601, CN602, CN603, CN604, CN605: Amiga-2000-Zorro-Slot; Samtec_HLE-150-02-xx-DV-TE_2x50_P2.54mm_Horizontal
CN700, CN701, CN702: ISA-16-BIT-Slot; ISA_16-BIT_P2.54mm_Horizontal
D300, D802, D9000, D9001: 1N4148; D_SOD-323
D800: BAT54CT; SOT-23
EMI200, EMI206, EMI207, EMI229, EMI230, EMI231, EMI232, EMI233, EMI234, EMI235, EMI236, EMI237, EMI238, EMI239, EMI240, EMI241, EMI242, EMI243, EMI325, EMI326, EMI327, EMI328, EMI329, EMI330, EMI331, EMI332, EMI333, EMI334: 100pF; C_1206_3216_Feedthrough
EMI300, EMI301, EMI302, EMI303, EMI304, EMI305, EMI306, EMI307, EMI308, EMI309, EMI310, EMI335, EMI336, EMI337, EMI338: C_Feedthrough; C_1206_3216_Feedthrough
F1, F2: 4A; Fuse_1206_3216Metric
FB101, FB102, FB301, FB302, FB303, FB401, FB900, FB901, FB902, FB907: Ferrite_Bead; C_1206_3216Metric
H1, H2, H3, H4, H5, H6, H7, H8, H9, H10, H11, H12: MountingHole_Pad; MountingHole_4.3mm_M4_Pad
J102: Short for NTSC/Open for PAL; PinHeader_1x02_P2.54mm_Vertical
J301: CLOSE FOR DF1; PinHeader_1x02_P2.54mm_Vertical
J500: Conn_01x02_Male; PinHeader_1x02_P2.54mm_Vertical
J900: Enable Chip RAM slowdown during DMA; PinHeader_1x02_P2.54mm_Vertical
J9000: POWER_SWITCH; PinHeader_1x02_P2.54mm_Vertical
Q1V1, Q2V1, Q3V1, Q300: MMBT3904; SOT-23
Q200, Q201: MMBFJ211; SOT-23
Q202, Q301, Q302: MMBT3906; SOT-23
R1V1, R5V1, R9V1, R233, R243, R301, R302, R311, R312, R601, R601A1, R601B1, R601C1, R601D1, R601E1, R601F1, R601G1, R601H1, R601I1, R602, R602A1, R602B1, R602C1, R602D1, R602E1, R602F1, R602G1, R602H1, R602I1, R603, R603A1, R603B1, R603C1, R603D1, R603E1, R603F1, R603G1, R603H1, R603I1, R604, R604A1, R604B1, R604C1, R604D1, R604E1, R604F1, R604G1, R604H1, R604I1, R605, R605A1, R605B1, R605C1, R605D1, R605E1, R605F1, R605G1, R605H1, R605I1, R800, R802, R805, R900: 1k; R_1206_3216Metric
R2V1, R7V1, R11V1: 4k; R_1206_3216Metric
R3V1, R6V1, R10V1: 2k; R_1206_3216Metric
R4V1, R8V1, R12V1: 8k; R_1206_3216Metric
R13V1, R15V1, R17V1, R9002: 470; R_1206_3216Metric
R14V1, R16V1, R18V1, R234, R244: 390; R_1206_3216Metric
R19V1, R20V1, R21V1, R22V1, R23V1, R24V1: 75; R_1206_3216Metric
R101, R109, R201, R300, R309, R500, R806, R807, R902, R916: 4.7k; R_1206_3216Metric
R104: 4.7k; C_1206_3216Metric
R105, R106, R212, R502A1, R502B1, R502C1, R502D1: 22; R_1206_3216Metric
R110, R114, R115: 330; R_1206_3216Metric
R111, R917, R1000: 407; C_1206_3216Metric
R202, R203, R206, R211, R214, R216, R231, R232, R241, R242, R305, R306, R804, R804A1, R9000, R9001: 10k; R_1206_3216Metric
R203A1, R203B1, R500A1, R500B1, R500C1, R500D1, R500E1, R500E2, R501A1, R501B1, R501C1, R501D1, R904, R905: 47; R_1206_3216Metric
R204, R205: 470k; R_1206_3216Metric
R207, R208: 10; R_1206_3216Metric
R209, R210: 1.2k; R_1206_3216Metric
R213: 2.7k; R_1206_3216Metric
R215: 1; R_1206_3216Metric
R230, R240: 360; R_1206_3216Metric
R307: 68; R_1206_3216Metric
R308: 200; R_1206_3216Metric
R310: 47 0.5W; R_1206_3216Metric
R801, R803: 220; R_1206_3216Metric
R914: 1 0.5W; R_1206_3216Metric
RN100, RN101: 4.7k; R_Array_SIP10
RN102, RN902: 47; R_Array_SIP8
RN200, RN801: 4.7k; R_Array_SIP8
RN201A1, RN201B1, RN201C1, RN201D1, RN203E1, RN907A1, RN907B1, RN907C1: 47; R_1206_3216Metric
RN204A1, RN204B1, RN204C1, RN204D1: 68; R_1206_3216Metric
RN205, RN301, RN607, RN800, RN903, RN908: 1k; R_Array_SIP6
RN300: 10k; R_Array_SIP10
RN503: 470; R_Array_SIP10
RN600: 10k; R_Array_SIP6
RN700, RN701, RN702, RN703, RN704, RN705, RN802: 1k; R_Array_SIP10
RN904, RN905, RN906: 4.7k; R_Array_SIP6
RNX1, RNX2: 2.7k; R_Array_SIP10
RRESET1: 1k; R_1206_3216Metric
U100: 68000D; DIP-64_W25.4mm
U101: FATTERAGNUS; PLCC-84_THT-Socket
U102: GARY; DIP-48_W15.24mm
U103, U105, U600, U601, U602, U603, U604, U605: 74LS245; SOIC-20W_7.5x12.8mm_P1.27mm
U104, U106: 74LS373; SOIC-20W_7.5x12.8mm_P1.27mm
U107: 74LS04; SOIC-14_3.9x8.7mm_P1.27mm
U108: 74LS74; SOIC-14_3.9x8.7mm_P1.27mm
U200: Paula; DIP-48_W15.24mm
U201: Denise; DIP-48_W15.24mm
U202: 74LS157; SOIC-16_3.9x9.9mm_P1.27mm
U203: 74LS38; SOIC-14_3.9x8.7mm_P1.27mm
U204: LF347; SOIC-14_3.9x8.7mm_P1.27mm
U205, U206: 74HCT244; SOIC-20W_7.5x12.8mm_P1.27mm
U300: 8520; DIP-40_W15.24mm
U301: U8520; DIP-40_W15.24mm
U302, U606: 74LS32; SOIC-14_3.9x8.7mm_P1.27mm
U303, U607, U803: 74LS08; SOIC-14_3.9x8.7mm_P1.27mm
U304: SN75188DR; SOIC-14_3.9x8.7mm_P1.27mm
U305: SN75189DR; SOIC-14_3.9x8.7mm_P1.27mm
U500: 27C400; DIP-40_W15.24mm
U501, U900: 74LS00; SOIC-14_3.9x8.7mm_P1.27mm
U502: CY74FCT821T; SOIC-24W_7.5x15.4mm_P1.27mm
U503: CY62157; TSOP-II-44_10.16x18.41mm_P0.8mm
U540, U541: 74LS244; SOIC-20W_7.5x12.8mm_P1.27mm
U800: BUSTER; DIP-48_W15.24mm
U801: RTC62423; SOIC-24W_7.5x15.4mm_P1.27mm
U802: 74LS138; SOIC-16_3.9x9.9mm_P1.27mm
U804: 74LS148; SOIC-16_3.9x9.9mm_P1.27mm
U805: LM339; SOIC-14_3.9x8.7mm_P1.27mm
U9000: MC7905; TO-263-2
U9001: 74HC14; SOIC-14_3.9x8.7mm_P1.27mm
U9002: 74HC74; SOIC-14_3.9x8.7mm_P1.27mm
VIDIOT1: HY200; PinSocket_1x22_P2.54mm_Vertical
X1: 28.63636MHz; Oscillator_DIP-14
XC1: 270pf; C_1206_3216Metric
XR1: 68; C_1206_3216Metric

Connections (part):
7M: RN907A1.1, U100.15, U201.35
28M: CN600.9, FB101.2, U101.34
+3V3: CN400.1, CN400.2, CN400.12, CN400.13
+5V: C100.1, C101.1, C102.1, C103.1, C104.1, C105.1, C106.1, C107.1, C108.2, C110.1, C200.1, C202.2, C203.2, C218.1, C225.1, C300.2, C301.1, C302.2, C305.1, C400.1, C401.1, C402.1, C403.1, C404.1, C405.1, C415.1, C416.1, C417.1, C418.1, C419.1, C420.1, C421.1, C422.1, C500.1, C501.1, C502.1, C503.1, C540.1, C541.1, C605.2, C606.1, C607.2, C700.1, C701.1, C705.1, C800.1, C802.1, C803.1, C804.1, C805.1, C903.1, C906.1, C910.1, C918.1, CN201.6, CN201.8, CN400.4, CN400.6, CN400.21, CN400.22, CN400.23, CN600.5, CN600.6, CN601.5, CN601.6, CN602.5, CN602.6, CN603.5, CN603.6, CN604.5, CN604.6, CN605.5, CN605.6, CN700.B3, CN700.B29, CN700.D16, CN701.B3, CN701.B29, CN701.D16, CN702.B3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
+12V: C406.1, C407.1, C704.1, CN201.10, CN400.10, CN400.11, CN600.10, CN601.10, CN602.10, CN603.10, CN604.10, CN605.10, CN700.B9, CN701.B9, CN702.B9, F2.1, R207.1, U304.14
+AV: C220.1, C222.1, C900.1, Q202.1, R207.2, R213.1, U204.4
+VID: C205.2, C206.2, C214.1, C226.1, R215.1, U205.20, U206.20, VIDIOT1.2, VIDIOT1.21
-5V: C412.1, C413.1, C702.1, C9001.1, CN201.31, CN600.8, CN601.8, CN602.8, CN603.8, CN604.8, CN605.8, CN700.B5, CN701.B5, CN702.B5, U9000.3
-12V: C408.1, C409.1, C703.1, C9000.1, CN400.14, CN601.20, CN602.20, CN603.20, CN604.20, CN605.20, CN700.B7, CN701.B7, CN702.B7, EMI334.2, R208.2, U304.1, U9000.2
-AV: C221.2, C223.2, C901.2, R206.2, R208.1, U204.11
/Floppy and Parallel/CHNG: CN303.2, RN301.2, U300.4
/Floppy and Parallel/DKWDB: CN303.22, U203.8
/Floppy and Parallel/DKWEB: CN303.24, U203.11
/Floppy and Parallel/INUSE1: CN303.4, CN303.14, U108.9, U203.4
/Floppy and Parallel/KBCLK: C260.1, CN300.3, FB302.1
/Floppy and Parallel/KBDATA: C261.1, CN300.2, FB303.1
/Floppy and Parallel/MTROD: CN303.16, Q301.3
/Floppy and Parallel/POUT: CN305.12, EMI337.2
/Floppy and Parallel/RDY: CN303.34, J301.2, RN301.5, U300.7
/Floppy and Parallel/SEL: CN305.13, EMI338.2
/Floppy and Parallel/TRK0: CN303.26, RN301.3, U300.6
/Floppy and Parallel/WPROT: CN303.28, RN301.4, U300.5
/Floppy and Parallel/_INUSE0: CN303.6, U900.3
/Floppy and Parallel/_IORST: C916.1, EMI300.2, U607.8
/Memory and Kickstart/DRAB0: R500A1.1, RN503.3, U502.2, U503.27
/Memory and Kickstart/DRAB1: R500B1.1, RN503.5, U502.3, U503.26
/Memory and Kickstart/DRAB2: R500C1.1, RN503.6, U502.4, U503.25
/Memory and Kickstart/DRAB3: R500D1.1, RN503.8, U502.5, U503.24
/Memory and Kickstart/DRAB4: R500E2.1, RN503.9, U502.6, U503.23
/Memory and Kickstart/DRAB5: R501A1.1, RN503.7, U502.7, U503.22
/Memory and Kickstart/DRAB6: R501B1.1, RN503.4, U502.8, U503.21
/Memory and Kickstart/DRAB7: R501C1.1, RN503.2, U502.9, U503.20
/Memory and Kickstart/DRAB8: R501D1.1, RN503.10, U502.10, U503.19
/Memory and Kickstart/DRAC0: U502.23, U503.5
/Memory and Kickstart/DRAC1: U502.22, U503.4
/Memory and Kickstart/DRAC2: U502.21, U503.3
/Memory and Kickstart/DRAC3: U502.20, U503.2
/Memory and Kickstart/DRAC4: U502.19, U503.1
/Memory and Kickstart/DRAC5: U502.18, U503.44
/Memory and Kickstart/DRAC6: U502.17, U503.43
/Memory and Kickstart/DRAC7: U502.16, U503.42
/Memory and Kickstart/DRAC8: U502.15, U503.28
/Memory and Kickstart/_CAS: U501.6, U501.10
/Memory and Kickstart/_MCASL: R500E1.1, U501.4
/Memory and Kickstart/_MCASU: R502A1.1, U501.5
/Memory and Kickstart/_MEMCLK: U501.3, U501.9, U502.13
/Memory and Kickstart/_MRAS0: R502B1.1, U501.1, U503.18
/Memory and Kickstart/_MRAS1: R502C1.1, U501.2
/Memory and Kickstart/_MWE: R502D1.1, U503.17
/Memory and Kickstart/_SRAMCE: U501.8, U503.6
/Paula/+5VMOUSE: CN200.7, CN200.16, F1.2
/Paula/FIR0: CN200.15, EMI241.1
/Power/+5VSB: CN400.9, D9000.1, D9001.1, R9000.1, R9001.1, U9001.14, U9002.13, U9002.14
/Power/PS_ON: CN400.16, U9002.9
/Serial/+V: CN305.34, EMI332.1
/Serial/-V: CN305.35, EMI334.1
/Serial/AI: C306.1, C317.2, CN305.43
/Serial/AO: C304.1, C318.1, CN305.36
/Serial/CD: CN305.33, EMI331.2, U301.7, U305.11
/Serial/CTS: CN305.30, EMI329.2, U301.6, U305.6
/Serial/DSR: CN305.31, EMI330.2, U301.5, U305.8
/Serial/DTR: CN305.45, EMI325.2, U301.9, U304.12, U304.13
/Serial/RI: CN305.47, EMI333.1
/Serial/RTS: CN305.29, EMI327.2, U301.8, U304.4, U304.5
/Serial/RxD: CN305.28, EMI328.2
/Serial/TxD: CN305.27, EMI326.2
/Video/BLUE: C3V1.2, CN201.15, FB902.2, R18V1.1, R24V1.2, VIDIOT1.17
/Video/BURST: CN201.18, U205.16
/Video/COMPSYNC: CN201.28, VIDIOT1.20
/Video/DB_(B3): CN201.25, RN201B1.2
/Video/DG_(G3): CN201.27, RN201C1.2
/Video/DI_(B0): CN201.23, RN201A1.2
/Video/DR_(R3): CN201.29, RN201D1.2
/Video/GREEN: C2V1.2, CN201.11, FB901.2, R16V1.1, R22V1.2, VIDIOT1.12
/Video/HSYNC: EMI206.1, R203B1.1
/Video/PIXELSW: CN201.30, RN203E1.1
/Video/RED: C1V1.2, CN201.7, FB900.2, R14V1.1, R20V1.2, VIDIOT1.7
/Video/VSYNC: EMI207.1, R203A1.1
/Zorro_Expansion/_CFGIN1: CN605.11, RN607.5, U606.13
/Zorro_Expansion/_CFGIN2: CN604.11, RN607.4, U606.2
/Zorro_Expansion/_CFGIN3: CN603.11, RN607.3, U606.5
/Zorro_Expansion/_CFGIN4: CN602.11, RN607.2, U606.10
/Zorro_Expansion/_CFGOUT2: CN604.12, U606.1, U606.11
/Zorro_Expansion/_CFGOUT3: CN603.12, U606.3, U606.4
/Zorro_Expansion/_CFGOUT4: CN602.12, U606.6, U606.9
/Zorro_Expansion/_CFGOUT5: CN601.12, U606.8
A1: CN600.29, U100.29, U101.60, U500.9, U600.2
A2: CN600.27, U100.30, U101.61, U500.8, U600.3, U801.5
A3: CN600.26, U100.31, U101.62, U500.7, U600.5, U801.7
A4: CN600.24, U100.32, U101.63, U500.6, U600.7, U801.9
A5: CN600.21, U100.33, U101.64, U500.5, U600.8, U801.10
A6: CN600.23, U100.34, U101.65, U500.4, U600.6
A7: CN600.28, U100.35, U101.66, U500.3, U600.4
A8: CN600.30, U100.36, U101.67, U300.38, U301.38, U500.2, U601.9
A9: CN600.32, U100.37, U101.68, U300.37, U301.37, U500.40, U601.8
A10: CN600.34, U100.38, U101.69, U300.36, U301.36, U500.39, U601.7
A11: CN600.36, U100.39, U101.70, U300.35, U301.35, U500.38, U601.6
A12: CN600.38, U100.40, U101.71, U302.1, U500.37, U601.5
A13: CN600.39, U100.41, U101.72, U302.5, U500.36, U601.4
A14: CN600.41, U100.42, U101.73, U500.35, U601.3
A15: CN600.43, U100.43, U101.74, U500.34, U601.2
A16: CN600.45, U100.44, U101.75, U500.33, U602.9
A17: CN600.47, U100.45, U101.76, U102.33, U500.32, U602.8
A18: CN600.52, U100.46, U101.77, U102.34, U500.1, U602.7
A19: CN600.54, U100.47, U101.59, U102.35, U602.6
A20: CN600.56, U100.48, U102.36, U602.5
A21: CN600.58, U100.50, U102.37, U602.4
A22: CN600.57, U100.51, U102.38, U602.3
A23: CN600.59, U100.52, U102.39, U602.2
AUDIN: C317.1, R202.1
AUDIO: C204.2, C219.2, C220.2, C221.1, C222.2, C223.1, C224.2, C232.2, C242.2, C900.2, C901.1, CN203.34, CN203.36, FB401.2, R210.2
AUDOUT: C243.2, R243.2, R302.1
B0: R12V1.2, RN201A1.1, U206.9, VIDIOT1.16
B1: CN203.10, R11V1.2, U206.7, VIDIOT1.15
B2: CN203.11, R10V1.2, U206.5, VIDIOT1.14
B3: R9V1.2, RN201B1.1, U206.3, VIDIOT1.13
BA1: C624.2, CN601.29, CN602.29, CN603.29, CN604.29, CN605.29, U600.18
BA2: C622.2, CN601.27, CN602.27, CN603.27, CN604.27, CN605.27, U600.17
BA3: C621.2, CN601.26, CN602.26, CN603.26, CN604.26, CN605.26, U600.15
BA4: C620.2, CN601.24, CN602.24, CN603.24, CN604.24, CN605.24, U600.13
BA5: C617.2, CN601.21, CN602.21, CN603.21, CN604.21, CN605.21, U600.12
BA6: C619.2, CN601.23, CN602.23, CN603.23, CN604.23, CN605.23, U600.14
BA7: C623.2, CN601.28, CN602.28, CN603.28, CN604.28, CN605.28, U600.16
BA8: C625.2, CN601.30, CN602.30, CN603.30, CN604.30, CN605.30, U601.11
BA9: C627.2, CN601.32, CN602.32, CN603.32, CN604.32, CN605.32, U601.12
BA10: C629.2, CN601.34, CN602.34, CN603.34, CN604.34, CN605.34, U601.13
BA11: C631.2, CN601.36, CN602.36, CN603.36, CN604.36, CN605.36, U601.14
BA12: C632.2, CN601.38, CN602.38, CN603.38, CN604.38, CN605.38, U601.15
BA13: C633.2, CN601.39, CN602.39, CN603.39, CN604.39, CN605.39, U601.16
BA14: C635.2, CN601.41, CN602.41, CN603.41, CN604.41, CN605.41, U601.17
BA15: C637.2, CN601.43, CN602.43, CN603.43, CN604.43, CN605.43, U601.18
BA16: C639.2, CN601.45, CN602.45, CN603.45, CN604.45, CN605.45, U602.11
BA17: C641.2, CN601.47, CN602.47, CN603.47, CN604.47, CN605.47, U602.12
BA18: C645.2, CN601.52, CN602.52, CN603.52, CN604.52, CN605.52, U602.13
BA19: C647.2, CN601.54, CN602.54, CN603.54, CN604.54, CN605.54, U602.14, U800.30
BA20: C649.2, CN601.56, CN602.56, CN603.56, CN604.56, CN605.56, U602.15, U800.31
BA21: C651.2, CN601.58, CN602.58, CN603.58, CN604.58, CN605.58, U602.16, U800.32
BA22: C650.2, CN601.57, CN602.57, CN603.57, CN604.57, CN605.57, U602.17, U800.33
BA23: C652.2, CN601.59, CN602.59, CN603.59, CN604.59, CN605.59, U602.18, U800.34
BD0: C664.2, CN601.75, CN602.75, CN603.75, CN604.75, CN605.75, U603.11
BD1: C666.2, CN601.77, CN602.77, CN603.77, CN604.77, CN605.77, U603.12
BD2: C668.2, CN601.79, CN602.79, CN603.79, CN604.79, CN605.79, U603.13
BD3: C670.2, CN601.81, CN602.81, CN603.81, CN604.81, CN605.81, U603.14
BD4: C672.2, CN601.83, CN602.83, CN603.83, CN604.83, CN605.83, U603.16
BD5: C674.2, CN601.86, CN602.86, CN603.86, CN604.86, CN605.86, U603.18
BD6: C673.2, CN601.84, CN602.84, CN603.84, CN604.84, CN605.84, U603.17
BD7: C671.2, CN601.82, CN602.82, CN603.82, CN604.82, CN605.82, U603.15
BD8: C669.2, CN601.80, CN602.80, CN603.80, CN604.80, CN605.80, U604.18
BD9: C667.2, CN601.78, CN602.78, CN603.78, CN604.78, CN605.78, U604.17
BD10: C665.2, CN601.76, CN602.76, CN603.76, CN604.76, CN605.76, U604.16
BD11: C661.2, CN601.71, CN602.71, CN603.71, CN604.71, CN605.71, U604.15
BD12: C659.2, CN601.69, CN602.69, CN603.69, CN604.69, CN605.69, U604.14
BD13: C657.2, CN601.67, CN602.67, CN603.67, CN604.67, CN605.67, U604.13
BD14: C655.2, CN601.65, CN602.65, CN603.65, CN604.65, CN605.65, U604.12
BD15: C654.2, CN601.63, CN602.63, CN603.63, CN604.63, CN605.63, U604.11
BFC0: C626.2, CN601.31, CN602.31, CN603.31, CN604.31, CN605.31, RN903.6, U605.15
BFC1: C628.2, CN601.33, CN602.33, CN603.33, CN604.33, CN605.33, RN903.5, U605.16
BFC2: C630.2, CN601.35, CN602.35, CN603.35, CN604.35, CN605.35, RN903.4, U605.17
C1: C907.1, U101.40, U102.28, U107.3, U107.13, U200.28, U201.36, U800.19
C3: C908.1, U101.39, U102.27, U107.5, U107.9, U200.29, U800.20
D0: CN305.2, CN600.75, EMI302.2, RNX1.3, U100.5, U105.2, U106.2, U300.33, U301.33, U500.13, U603.9, U801.19
D1: CN305.3, CN600.77, EMI303.2, RNX1.4, U100.4, U105.3, U106.5, U300.32, U301.32, U500.15, U603.8, U801.16
D2: CN305.4, CN600.79, EMI304.2, RNX1.5, U100.3, U105.4, U106.6, U300.31, U301.31, U500.17, U603.7, U801.15
D3: CN305.5, CN600.81, EMI305.2, RNX1.6, U100.2, U105.5, U106.9, U300.30, U301.30, U500.19, U603.6, U801.14
D4: CN305.6, CN600.83, EMI306.2, RNX1.10, U100.1, U105.6, U106.12, U300.29, U301.29, U500.22, U603.4
D5: CN305.7, CN600.86, EMI307.2, RNX1.9, U100.64, U105.7, U106.15, U300.28, U301.28, U500.24, U603.2
D6: CN305.8, CN600.84, EMI308.2, RNX1.8, U100.63, U105.8, U106.16, U300.27, U301.27, U500.26, U603.3
D7: CN305.9, CN600.82, EMI309.2, RNX1.7, U100.62, U105.9, U106.19, U300.26, U301.26, U500.28, U603.5
D8: CN600.80, RNX2.9, U100.61, U103.2, U104.2, U500.14, U604.2
D9: CN600.78, RNX2.8, U100.60, U103.3, U104.5, U500.16, U604.3
D10: CN600.76, RNX2.7, U100.59, U103.4, U104.6, U500.18, U604.4
D11: CN600.71, RNX2.6, U100.58, U103.5, U104.9, U500.20, U604.5
D12: CN600.69, RNX2.5, U100.57, U103.6, U104.12, U500.23, U604.6
D13: CN600.67, RNX2.4, U100.56, U103.7, U104.15, U500.25, U604.7
D14: CN600.65, RNX2.3, U100.55, U103.8, U104.16, U500.27, U604.8
D15: CN600.63, RNX2.2, U100.54, U103.9, U104.19, U500.29, U604.9
DIR: CN303.18, U301.11
DKWE: U102.8, U200.39
DMAL: U101.18, U200.12
DMAOUT: U302.11, U600.1, U601.1, U602.1, U605.1
DOE: CN601.93, CN602.93, CN603.93, CN604.93, CN605.93, R601.2, R904.1
DRA0: U101.43, U540.2
DRA1: U101.44, U540.4
DRA2: U101.45, U540.6
DRA3: U101.46, U540.8
DRA4: U101.47, U540.17
DRA5: U101.48, U540.15
DRA6: U101.49, U540.13
DRA7: U101.50, U540.11
DRA8: U101.51, U541.2
DRD0: U101.14, U105.18, U106.3, U200.10, U201.7, U503.7
DRD1: U101.13, U105.17, U106.4, U200.9, U201.6, U503.8
DRD2: U101.12, U105.16, U106.7, U200.7, U201.5, U503.9
DRD3: U101.11, U105.15, U106.8, U200.6, U201.4, U503.10
DRD4: U101.10, U105.14, U106.13, U200.5, U201.3, U503.13
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

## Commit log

2021-05-07 Update ShoppingList.csv
    Fixed floppy header part number.
    [ShoppingList.csv]
2021-05-18 Remove Rev 0 Kicad Files
    [2000ATX.sch, Processor.sch, Zorro_Expansion.sch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]
2021-06-18 Delete 2000EATX-KiCAD-R1 directory
    Delete old revision
    [2000ATX.sch, Processor.sch, Zorro_Expansion.sch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]
2021-07-15 Update with current testing status
2021-07-22 Delete 2000EATX-KiCAD-R11 directory
    Delete Deprecated Revision.
    [2000ATX.csv, 2000ATX.sch, Processor.sch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]
2021-08-11 Upload Rev PCB 1.2.1 Image
2021-08-12 Gerber for Rev 1.2.1
2021-08-12 Updated to include production board information.
2021-08-14 Added photo of Amiga 2000 EATX in computer case
2021-08-17 Updated SRAM part number
    [AMIGA_2000_EATX_REV12_SHOPPINGLIST.csv]
2021-08-21 Add Insane Jumper Edition
    This was a trial run to make schematics to support either 8375 or 8372A with one board. Total jumpers to configure: 34.
    [2000ATX-REFERENCE_REV12.csv, 2000ATX.sch, Agnus-Multi.sch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]
2021-09-30 Additional footprints and symbols
2021-11-18 Revision 2.1 BOM and Shopping List
    [AMIGA_2000_EATX_REV12_SHOPPINGLIST.csv]
2021-11-18 Amiga 2000 EATX Schematics
2021-12-11 Update AssemblyNotes.md
    Fixed BOM links.
2021-12-21 Added additional details to case selection.
2021-12-21 Updated case selection section.
2021-12-21 Added information to the case selection section.
2021-12-21 Updated case considerations section.
2021-12-23 Corrected part number line 111.
    [Amiga_2000_EATX_REV21_SHOPPINGLIST.csv]
2022-01-04 Update AssemblyNotes.md
    Agnus part numbers 390544-01 and 390544-02 were in the wrong column in Table A3. Fixed.
2022-01-05 Updated Rev 2.1 Gerber
    Updated the Agnus configuration table.
2022-01-05 Update Rev 2.1 KiCad Agnus Configuration Jumpers
    Update the agnus configuration jumper tables in the schematics and on the board.
    [2000ATX.sch, Agnus-Multi.sch]
2022-02-04 Add TICK Board Gerbers
2022-02-04 Add Rev 2.2 KiCAD Files
    [2000ATX.sch, Agnus-Multi.sch, Processor.sch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]
2022-02-04 New with Rev 2.2
    [TICK.kicad_pcb, TICK.sch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]
2022-02-04 Updated for Rev 2.2
    [2000ATX-REFERENCE_REV22.csv]
2022-03-25 Gerber Files
2022-07-17 Updated Digikey Part Numbers
    [Amiga_2000_EATX_REV22_SHOPPINGLIST.csv]
2022-10-11 Update to include 74F245 change.
    [Amiga_2000_EATX_REV22_SHOPPINGLIST.csv]
2022-10-11 Change U103/105 to 74F245.
    [2000EATX-REFERENCE_REV22.csv]
2023-01-23 Interactive BOM
2023-02-13 Description of Rev 6.2/A2630/A2091 DMA Issue
2023-03-01 Add dual oscillator TICK.
    [TICK.kicad_pcb, TICK.kicad_sch]
2023-05-11 Rev 3.0 Schematics
2023-05-11 Rev 3.0 Gerber
2023-05-11 Rev 3.0 KiCAD
    [2000ATX.kicad_sch, 2000ATX.sch, Agnus-Multi.kicad_sch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]
2024-06-02 Update to Rev 3.1 02-JUN-2024
    [2000ATX-REV30-ShoppingList.csv, 2000ATX.kicad_sch, 2000ATX.sch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]
2024-06-02 Update Schematic 02-JUN-2024
    [2000ATX.kicad_sch]
